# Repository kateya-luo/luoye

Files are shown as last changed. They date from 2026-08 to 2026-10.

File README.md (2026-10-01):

# 落叶（Luoye）录音卡---会议纪要AI录音卡

<!-- split-project-navigation -->
## 固件与服务器独立入口

落叶是同一个完整项目，固件与服务器通过 `luoye-device-api/2` 配合，分开维护和发布。

| 组件 | 独立入口 | 版本下载 |
| --- | --- | --- |
| 录音卡固件、硬件与使用说明 | [固件页面](https://github.com/kateya-luo/luoye/tree/main/firmware) | [固件历史发布](https://github.com/kateya-luo/luoye/releases) |
| ClearMeeting 服务器与网页 | [服务器项目](https://github.com/kateya-luo/clearmeeting-server) | [V2.1.0 R2](https://github.com/kateya-luo/clearmeeting-server/releases/tag/v2.1.0-r2) |

**最新服务器版本为 V2.1.0 R2。** 本仓库原 `server/` 和旧服务器 Release 保留作历史归档；
新部署、升级及服务器源码请使用上面的独立服务器项目。
下方旧兼容基线和固件功能描述对应历史公开版本，不代表新版省电固件的功能。
本次不发布或替换固件二进制。

<!-- /split-project-navigation -->

起因是我觉得钉TALK太贵了，这么个玩意儿自己做一个得了，结果就是漫长的三个月。
这也是我第一个全自研（AI助力）的项目，希望您能喜欢。
落叶是一套以 ESP32-S3、1.54 英寸电子墨水屏、双麦克风和 microSD 为核心的录音卡系统。设备负责可靠录音、离线保存、实时字幕显示与断点补传；ClearMeeting 负责转写、多人识别、会议纪要、待办和网页管理。

## 项目预览

|  |  |
| :---: | :---: |
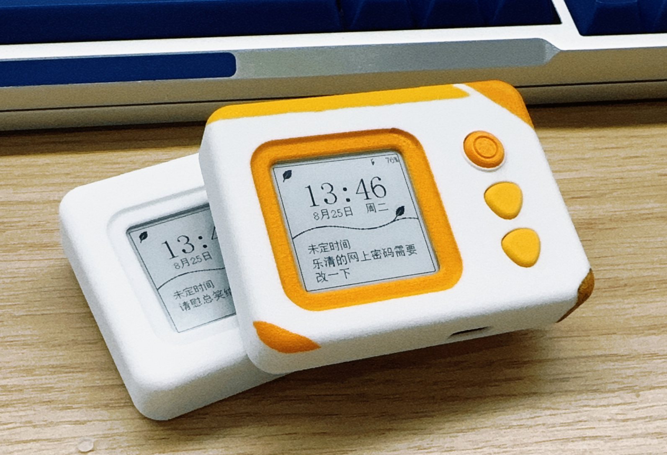
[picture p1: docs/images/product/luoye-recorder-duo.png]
两台落叶录音卡工程样机
|  | 截图_20261001234019 |
| **桌面使用** | **实机操作** |
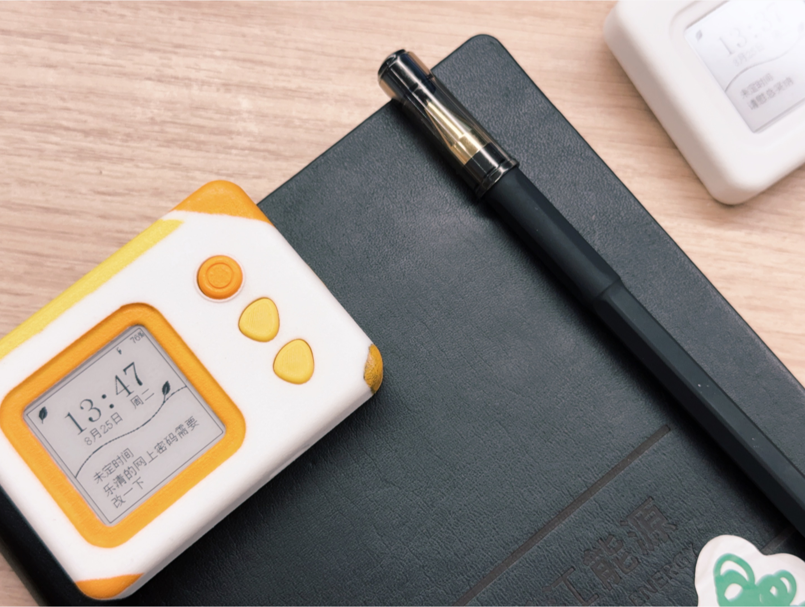
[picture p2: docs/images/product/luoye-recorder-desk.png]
落叶录音卡桌面使用场景
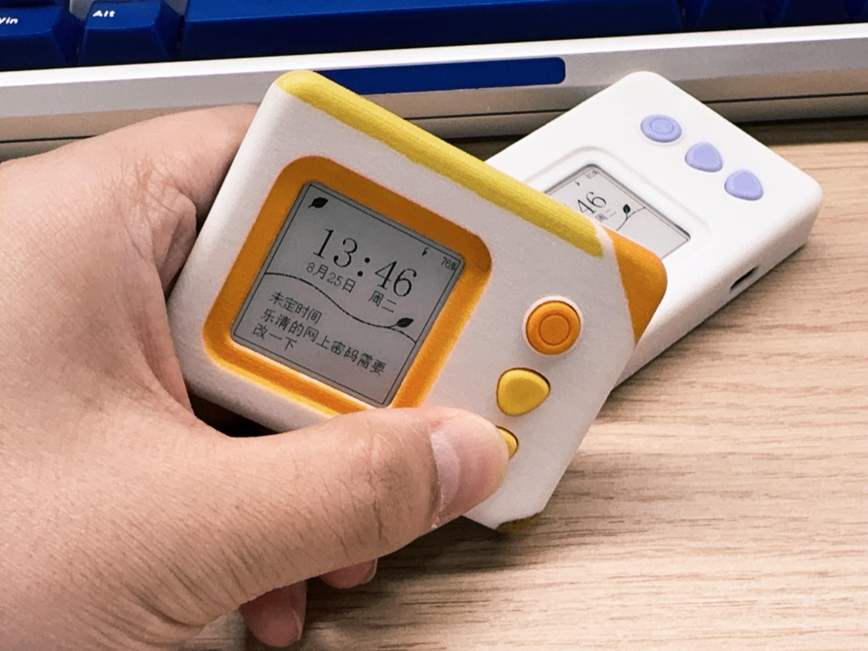
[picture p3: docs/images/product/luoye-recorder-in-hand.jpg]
手持操作落叶录音卡
|  |  |

以上为当前 3D 打印外壳的工程样机实拍。

## 当前兼容基线

| 组件 | 版本/标识 | 说明 |
| --- | --- | --- |
| 固件 | `2.0.0 stable-sdspi R1` | 由已验证的 `1.7.2` 稳定基线重新编号 |
| 服务器 | `2.0.0 stable R1` | 由 `0.21.0-upload-progress-r9` 稳定基线重新编号 |
| 设备 API | `luoye-device-api/2` | 固件与服务器的兼容边界 |
| 硬件 | `LY-HW-ENG-20260710` | 当前工程样机，尚未形成量产归档 |

详细变化和验证要求见 [发布兼容矩阵](docs/RELEASE_COMPATIBILITY.md)。

## ClearMeeting 网页

| 实时会议 | 会议历史 |
| :---: | :---: |
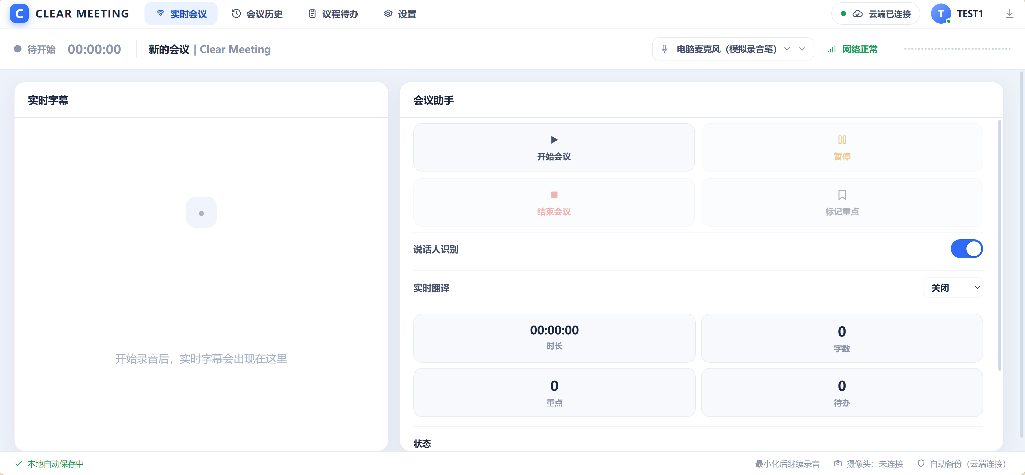
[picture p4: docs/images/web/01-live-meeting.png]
ClearMeeting 实时会议
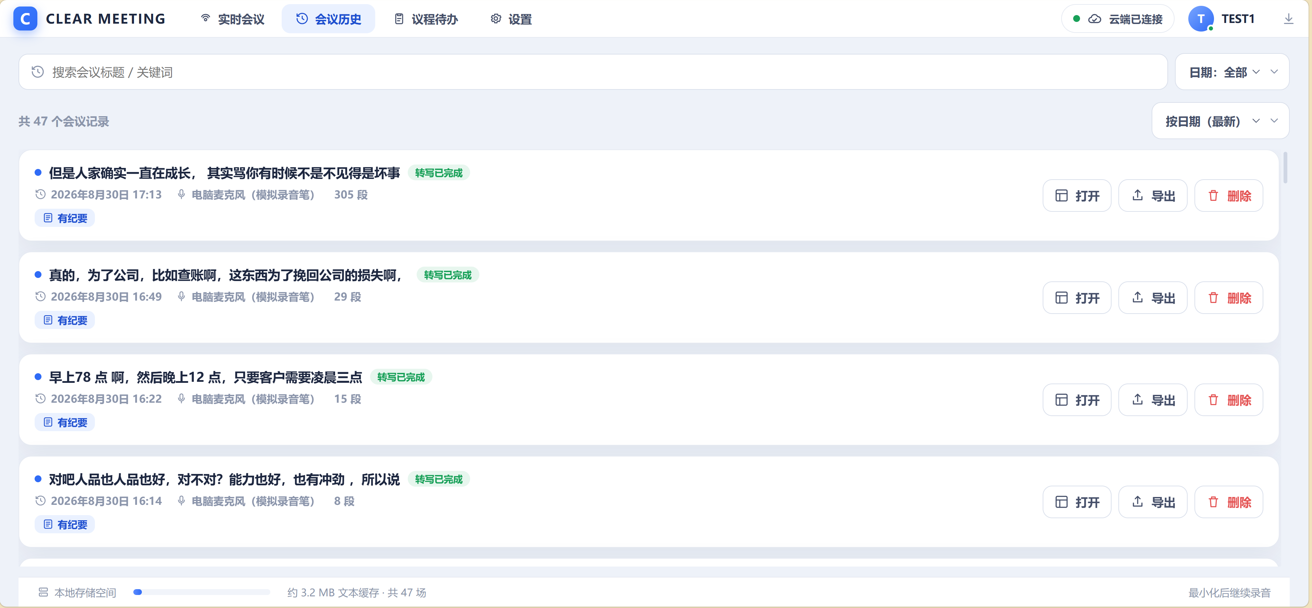
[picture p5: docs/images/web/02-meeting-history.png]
ClearMeeting 会议历史
|  |  |

| 完整转写与人员 | 议程与待办 |
| :---: | :---: |
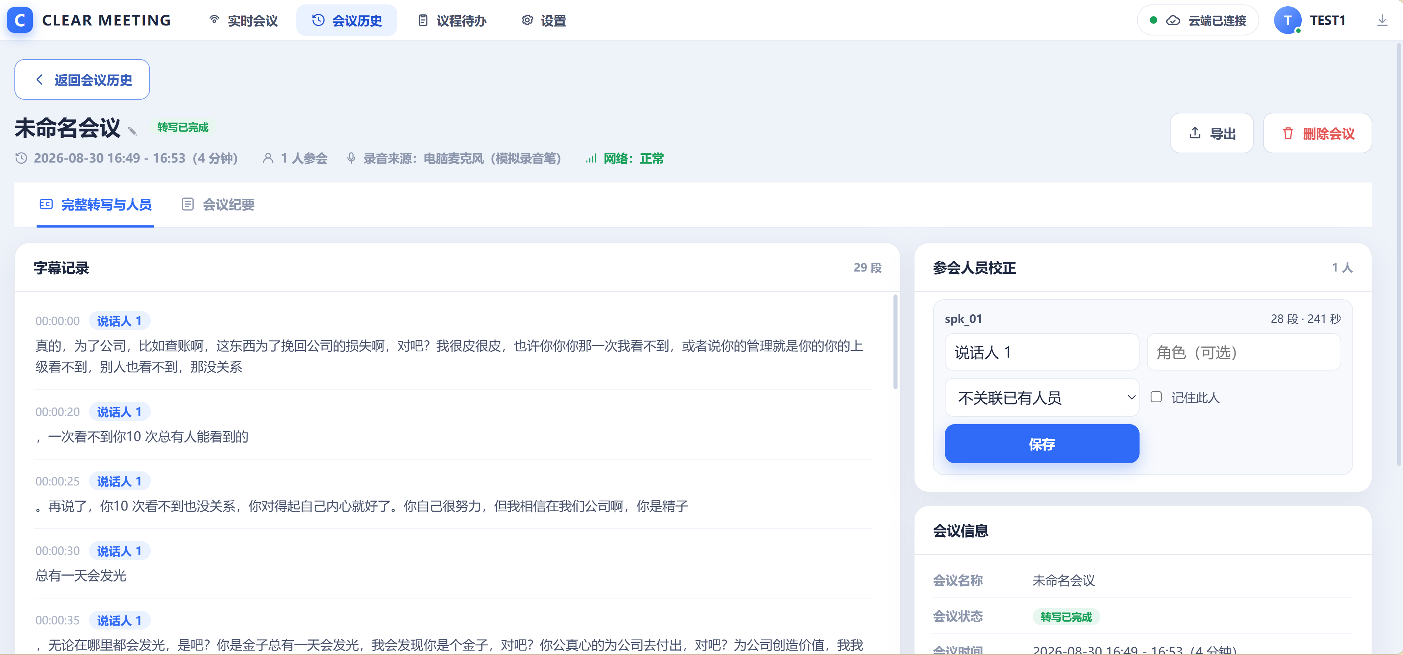
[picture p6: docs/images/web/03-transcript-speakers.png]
完整转写与说话人校正
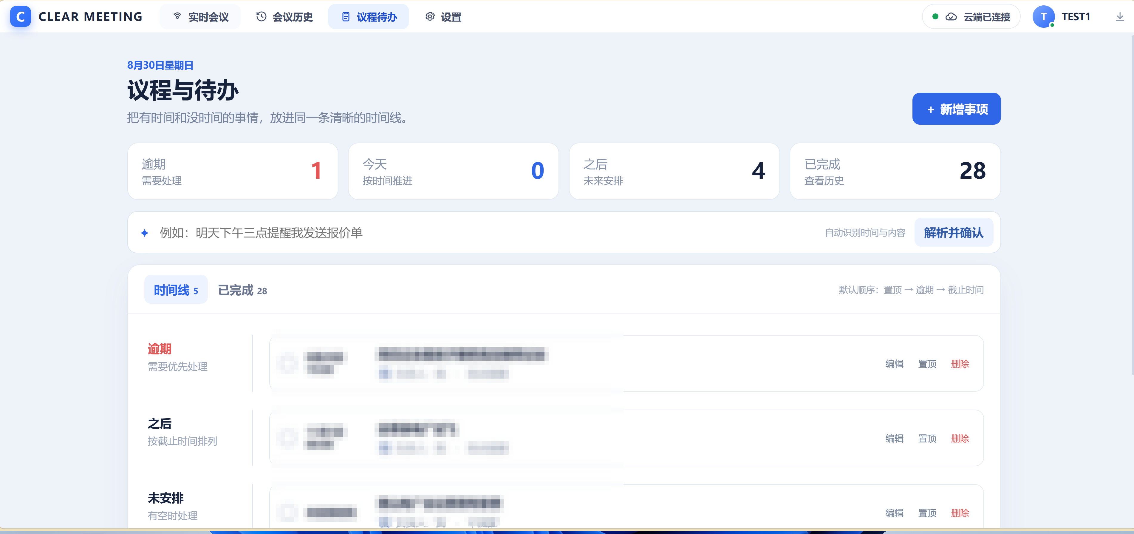
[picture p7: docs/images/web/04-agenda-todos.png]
议程与待办页面
|  |  |

| 设备管理 | 会议导出 |
| :---: | :---: |
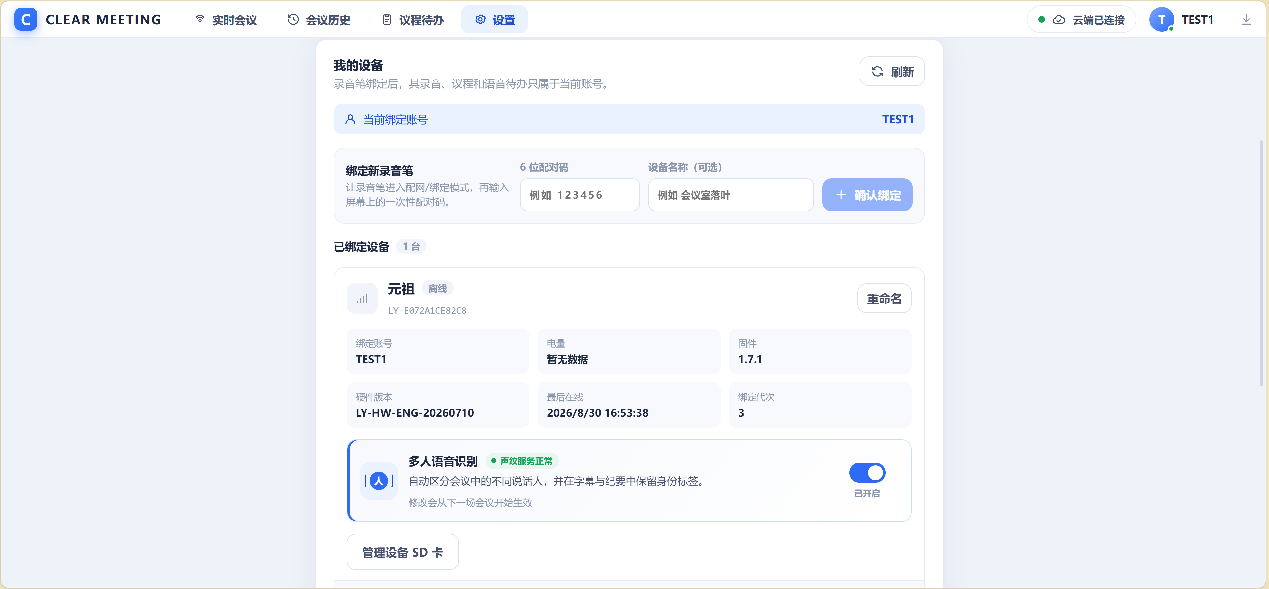
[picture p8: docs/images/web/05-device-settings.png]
录音卡设备管理
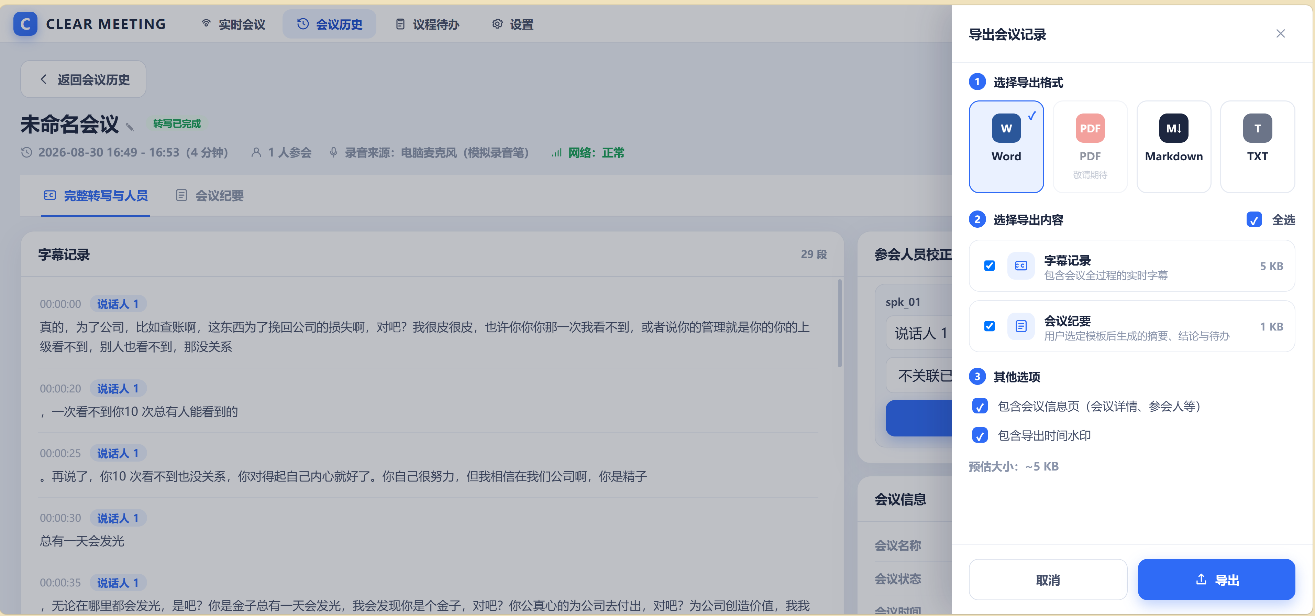
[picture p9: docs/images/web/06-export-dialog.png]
会议记录导出
|  |  |

## 主要能力

- 双 PDM 麦克风录音，16 kHz 单声道 PCM/WAV 先落 microSD。
- 断网、重启和手动退出后按服务器缺口继续补传。
- 电子墨水屏显示时钟、电量、录音状态、字幕、议程、提醒和语音待办。
- ClearMeeting 提供实时转写与翻译、整场离线规范化、多人识别和模板化会议纪要。
- 设备与网页共享账号隔离、幂等会话、SD 管理和后台处理状态。
- 固件、服务器、PCB 与机械结构在同一仓库记录兼容关系。

## 使用说明

### 产品的基本使用流程

1. 在自己的服务器上部署 ClearMeeting，复制 `.env.example` 为 `.env`，填写账号密钥、AI 服务密钥和自己的 HTTPS 地址。
2. 给录音卡插入 FAT32 microSD 卡并开机；首次使用时按屏幕提示完成 Wi-Fi 配网，然后在网页“设置”中输入六位配对码绑定设备。
3. 使用录音键开始或结束录音。音频先可靠写入 SD 卡，联网时同步到服务器；断网时继续本地录音，恢复网络后按服务端缺口续传。
4. 录音期间可在墨水屏和网页查看实时文字；启用翻译后，还可同步查看目标语言内容。
5. 会议结束后，在网页历史记录中查看完整转写、说话人、纪要和待办，并导出 Word、Markdown 或文本。

### 录音卡功能

- 双麦克风采集、16 kHz WAV 本地保存，断网、复位和中途退出后可继续补传。
- 电子墨水屏显示时间、电量、录音时长、实时文字、翻译、滚动纪要、议程与提醒。
- 待机期间以 RTC 保持离线到点提醒；联网唤醒后同步日程和待办。
- 录音与上传使用独立的持久化状态，上传不会清空日程数据。
- microSD 异常、服务器状态和上传进度均有诊断日志，便于通过 USB 串口排查。

### ClearMeeting 网页功能

- 账号登录、录音卡配对、在线状态与 SD 卡管理。
- 浏览器直接发起会议，或接收录音卡上传的在线/离线会议。
- 实时字幕、实时翻译、完整离线定稿和多人说话人识别。
- 会议历史检索、纪要模板、待办提取、时间线、人员校正和多格式导出。
- 日历式议程与待办同步，可创建有时间或无时间的提醒事项。

### 典型场景

- **会议与访谈**：可靠录音、实时字幕、会后定稿、说话人区分和纪要导出。
- **外文课堂**：把实时转写与翻译显示在网页或录音卡上，作为随身课堂字幕/翻译设备。
- **课程表提醒**：利用和日历系统关联的议程与待办，把课程安排同步到录音卡，并由 RTC 离线提醒。
- **讲座与学习整理**：长时间录音后自动形成可检索文字、重点和后续任务。

按键、烧录、串口诊断和开发构建的详细说明见 [固件使用文档](firmware/README.md)；部署和环境变量见 [服务器使用文档](server/README.md)。

## 数据流

```text
双麦克风 → ESP32-S3 → microSD/WAV → luoye-device-api/2 → ClearMeeting
               ↓                              ↓
          电子墨水屏                    转写 / 多人识别
                                             ↓
                                      纪要 / 待办 / 导出
```

## 仓库结构

```text
firmware/             ESP32-S3 固件源码、构建检查和诊断工具
server/               ClearMeeting 服务端、Web 前端与部署文件
hardware/pcb/         主板/双麦板原理图与 EPRO 工程
hardware/mechanical/  外壳、内壳、底壳和按钮 STEP
docs/                 跨组件版本、制造与发布说明
scripts/              发布前仓库审计
```

## 快速开始

- 固件编译、烧录和串口诊断：[firmware/README.md](firmware/README.md)
- 服务器部署与验证：[server/README.md](server/README.md)
- PCB 与机械资料：[hardware/README.md](hardware/README.md)
- GitHub 发布前检查：[docs/GITHUB_PUBLISH_CHECKLIST.md](docs/GITHUB_PUBLISH_CHECKLIST.md)

## 隐私与部署配置

- 仓库不内置作者的 DeepSeek API Key、个人服务器域名/IP、Wi-Fi 名称、账号密码或设备令牌。
- `DEEPSEEK_API_KEY`、CORS 来源和公开服务地址只在本地 `.env` 或构建参数中配置；`.env` 已被 Git 忽略。
- 固件公开源码默认使用不可路由的 `https://meeting.example.invalid`。构建前必须用 `-ServerBaseUrl https://你的域名` 指定自己的服务。
- 如需同一 Wi-Fi 下走局域网服务器，可同时设置 `LUOYE_LAN_WIFI_SSID` 与 `LUOYE_LAN_SERVER_BASE_URL`；公开源码中的默认值为空。

## 版本和发布

源码仓库不提交烧录包、服务端压缩包、数据库、录音或密钥。二进制发布附件使用独立组件标签：

- `firmware-v2.0.0`
- `server-v2.0.0`

固件当前仍按 Engineering 版本发布。正式量产前必须完成真机长录音、跨 10 MiB 边界、上传中断恢复、SD 故障和重复复位验证。

## 工程边界

- 当前硬件资料属于自研样机。不能直接作为生产或开模依据；详见 [制造归档检查](docs/MANUFACTURING_STATUS.md)。
- 工程部署仍可显式使用 HTTP；真实账号、设备令牌和真实录音必须改用 HTTPS。
- 当前未选择开源许可证。在加入 `LICENSE` 前，代码和设计资料默认保留全部权利。

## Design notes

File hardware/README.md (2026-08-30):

# 硬件资料

- `pcb/`：2026-08-30 主板与双麦板 EPRO 工程，以及 2026-06-21 原理图 PDF。
- `mechanical/`：V2 外壳、底壳、内壳和两个按钮的 STEP 文件。

> [!WARNING]
> ECAD 与 MCAD 当前是两个独立的工程参考基线，尚未完成板框、接口位置、按键行程、螺柱和装配公差的联合锁版。仓库中的实物照片能证明当前样机已经装配运行，但不能证明这些源文件可以直接投产。

正式发板、打印定版或开模前，请完成 [制造归档检查](../docs/MANUFACTURING_STATUS.md)。

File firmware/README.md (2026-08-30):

# 落叶（Luoye）录音卡固件

ESP32-S3 + 1.54" 方形墨水屏(GDEY0154D67/SSD1681, 200×200)+ 双 PDM 麦 + microSD。

当前方屏版本说明、按键表和烧录步骤见 [docs/UI154_FIRMWARE.md](docs/UI154_FIRMWARE.md)。
内部产品名为 **落叶 / Luoye**，ESP-IDF 工程名保留为 `recorder_card`。
当前固件版本：`2.0.0`，设备协议：`luoye-device-api/2`，配套服务器：ClearMeeting `2.0.0`（源自 `0.21.0-upload-progress-r9`）。
V1.5.0 的电量百分比改为 3.180–4.100V 被动电压映射；它只负责显示，不参与充电终止或录音权限判断。详见 [docs/V1_5_0_PASSIVE_BATTERY_DISPLAY.md](docs/V1_5_0_PASSIVE_BATTERY_DISPLAY.md)。
V1.5.1 调整墨水屏维护节奏：每分钟时间局刷、每10分钟 FAST、每逢整点 FULL，充电页每跨5%执行一次 FAST。详见 [docs/V1_5_1_REFRESH_CADENCE.md](docs/V1_5_1_REFRESH_CADENCE.md)。
V1.5.2 删除所有人为电量涨跌速度和99%封顶，滤波电压直接映射百分比。详见 [docs/V1_5_2_DIRECT_VOLTAGE_SOC.md](docs/V1_5_2_DIRECT_VOLTAGE_SOC.md)。
V1.6.0 R2 只修复手动补传再次进入时未立即继续的问题：重新确认同步会解除旧重试等待，并再次依据服务器 `upload-plan` 续传；不增加NVS状态，也不改变10 MiB和底层上传参数。详见 [docs/V1_6_0_MINIMAL_MANUAL_RESUME.md](docs/V1_6_0_MINIMAL_MANUAL_RESUME.md)。
V1.7.2 固定项目本地 ESP-IDF 5.5.4 `sdmmc` 组件。SDSPI 主机已拥有永久516字节内部 DMA 中转，因此通用读写层不再为 FatFS/PSRAM 缓冲临时申请512字节 DMA；原生 SDMMC 规则不变。实时录音、实时读取和离线上传共用这一根因修复，10 MiB分段、SHA、断点续传及网络参数保持不变。详见 [docs/V1_7_2_SDSPI_OUTER_DMA.md](docs/V1_7_2_SDSPI_OUTER_DMA.md)。
V2.0.0 是已通过真机稳定验证的 V1.7.2 正式升版，不引入功能或参数变化。它取代早期同号的 live-caption 实验包，作为后续维护基线。详见 [docs/V2_0_0_STABLE_BASELINE.md](docs/V2_0_0_STABLE_BASELINE.md)。
交互行为以 **250×122 交互模拟器** 为规格书(`ai-recorder-card-sim-index-250x122.html`),
`main/app_state.c` 是其中状态机的 1:1 C 移植 —— **改交互先改模拟器,确认后两边同步**。

## 架构

```
keys(10ms轮询) ──┐
power_poll(5s) ──┼─→ [app事件队列] → app_task(串行) → app_state 状态机 → hooks
network scheduler ─┘                                        │
                                                   ┌────────┼─────────┐
audio_cap(核1,p18) → StreamBuffer(PSRAM 256KB) → sd_writer(核0,p15)   │
                                                   ui(渲染,p6)   led(50ms)
```

数据流：
**PDM 双麦 → 16k 单声道 PCM → SD(WAV,先落卡) → 在线 160 KiB 实时上传；
整段离线/断网补洞按 10 MiB 逻辑范围、64 KiB RAM 流式上传
→ 最多 4 秒一次 revision 游标轮询字幕/译文 → 墨水屏节流回屏**。议程以 UTC/revision 缓存到固定 SD，
PCF8563 调度最近提醒；待机按住待办键可另存最长 30 秒的语音待办。当前录音在线时
实时上传，已结束的历史录音由录音键长按进入、待办键确认的 FIFO 同步；服务器验证字节覆盖并
完整确认后立即删除对应本地目录。录音与待办请求都使用稳定幂等键。所有已认证
HTTP 由单一网络业务调度器仲裁，SD 录音写入不依赖网络。

## 目录

| 路径 | 内容 |
|---|---|
| `main/board_pins.h` | **引脚真源**(网表+BOM 验证,2026-07-10),改板先改这里 |
| `main/luoye_build_info.[ch]` | 单一版本源、commit、硬件版本、IDF 和启动身份日志 |
| `main/luoye_diag.[ch]` | 统一 `LYE-xxx` 错误码、子系统状态和事件丢弃计数 |
| `main/app_state.[ch]` | 核心状态机(纯逻辑,可 PC 单测) |
| `main/input_keys.c` | 三键去抖 + 每键每态长按阈值（录音键1.5s/关机3s，设置键3s，待办键待机600ms） |
| `main/led_ctrl.c` | 三灯花样(语义同模拟器 renderLeds) |
| `main/ui_render.c` | 帧缓冲 + 各屏布局(中文文案对齐模拟器);5×7 ASCII 兜底 |
| `main/ui_font.c` | 16px 中文点阵字库加载与渲染(assets 分区 `font16.bin` → PSRAM,二分查找) |
| `tools/gen_font.py` | 字库生成脚本(TTF/TTC → font16.bin) |
| `tools/preview_screens.py` | 屏幕布局预览(不烧板看 250×122 真机像素效果) |
| `tools/test_app_state.c` | 状态机 PC 回归测试(`run_state_test.bat` 一键编译运行,改 app_state.c 必跑) |
| `tools/build_profile.ps1` | 固化 dev / rc / release 三种构建配置 |
| `tools/run_engineering_checks.ps1` | 回归测试、版本检查、构建和可选打包门禁 |
| `tools/package_firmware.ps1` | 生成带 manifest、SHA-256 和烧录说明的内部发布包 |
| `assets/font16.bin` | 21159 字 / 703KB(Noto Sans SC Light，GBK 全集汉字 + 中英标点 + 全角) |
| `components/epd_ssd1680/` | 屏驱动(厂商时序逐条移植;全刷 0xF7 / 快刷 0xC7 / 局刷 0xFF) |
| `components/audio_pdm/` | I2S PDM 采集 → PSRAM 环形缓冲 |
| `components/storage_sd/` | SD 挂载 + WAV 写入(64KB 修头+fsync,断电可恢复)+ 容量巡检 |
| `components/net_uploader/` | SoftAP、账号认领、持久补传、实时字幕/翻译协议 |
| `components/power_mgr/` | BQ25186 / MAX17048 / PCF8563(I2C)+ 深睡 |
| `components/agenda_todo/` | 议程原子缓存、RTC 调度、语音待办旁路录制与状态持久化 |

## 构建（固定 ESP-IDF v5.5.4）

在 ESP-IDF PowerShell 中执行：

```powershell
cd <仓库目录>\firmware
.\tools\run_engineering_checks.ps1 -Profile dev -FullClean
```

正式 HTTPS 开发构建（默认连接 `https://meeting.example.invalid`）：

```powershell
.\tools\build_profile.ps1 -Profile dev
```

局域网/公网工程联调必须显式给出服务器 origin 并打开明文 HTTP；该开关只允许 `dev` 或 `engineering`
工程构建，不能用于真实账号或敏感录音：

```powershell
.\tools\build_profile.ps1 -Profile dev `
  -ServerBaseUrl http://192.0.2.10:34567 `
  -AllowInsecureHttp
```

`ServerBaseUrl` 只能是无路径、无末尾 `/` 的 `http(s)://host[:port]`。
`rc` / `release` 构建拒绝 HTTP，并固定使用系统 CA 验证 HTTPS。

公开源码不包含作者的 SSID 或局域网服务器地址。如需在指定 Wi-Fi 下自动切换到局域网服务，
配置时必须同时传入 `LUOYE_LAN_WIFI_SSID` 和 `LUOYE_LAN_SERVER_BASE_URL`；两项默认均为空。

生成工程烧录包（必须先提交源码并保持 Git 工作树干净）：

```powershell
.\tools\run_engineering_checks.ps1 -Profile engineering -FullClean -Package `
  -ReleaseId luoye-fw-v2.0.0-engineering-stable-sdspi-r1 `
  -ServerBaseUrl https://meeting.example.invalid
```

当前正式构建机已使用 ESP-IDF v5.5.4 完成 baseline 干净构建。构建会自动把
`assets/`（含字库）生成 `assets.bin`；打包脚本不会擦除或覆盖设备 NVS。

版本单一真源是根 `CMakeLists.txt` 的 `PROJECT_VER`。UI、ESP app descriptor、
串口 `LY|BOOT` 记录和 release manifest 必须保持一致。

当前硬件标识暂定为 `LY-HW-ENG-20260710`，表示基于 2026-07-10 网表的工程样板；
正式 PCB 丝印版本确定后必须同步更新，禁止把暂定标识用于量产。

## 中文字库

- 运行时:`ui_font.c` 开机把 `font16.bin` 载入 PSRAM;文件缺失时 UI 自动退回 ASCII(中文显示空心框),设备不砖。
- 重新生成:`python tools/gen_font.py --font <字体文件> --out assets/font16.bin`,
  `--test 会议` 可先预览点阵,`--dump 会议` 验证已生成文件的解码。
- **字体授权**:当前 `font16.bin` 使用 Noto Sans SC Light 生成；固件页面使用单色点阵，
  不包含灰阶抗锯齿。

## 首次点亮前必读

1. **墨水屏方向校准**:若首帧镜像/颠倒,改 `epd_ssd1680.h` 里
   `EPD_ROT_FLIP_X / EPD_ROT_FLIP_Y / EPD_X_OFFSET` 三个宏即可,不用动代码。
2. **Strap 脚**(引脚表里已标 ⚠):
   - GPIO46(EPD_MOSI)启动瞬间必须为低 —— 屏端不得有上拉;
   - GPIO45(FULL_LED)、GPIO3(EPD_SCLK)同为 strap,当前用法安全,改板别挂强上拉。
3. **到点提醒的低功耗策略**:`RTC_INT` 在 **GPIO41(非 RTC-IO)**，不能作为深睡
   唤醒源。固件在存在已缓存提醒时改用 GPIO light sleep，由 GPIO41 或长按 REC
   唤醒；没有提醒时仍进入深睡。这样现板无需飞线即可到点唤醒，代价是有提醒期间
   待机功耗高于深睡。下一版 PCB 仍建议把 `RTC_INT` 改到 RTC-IO。
4. 按键无外部上拉(只有 100nF 去抖电容):运行态开内部上拉,深睡前开 RTC 域上拉
   (`power_enter_off` 已处理,别删)。

## 与模拟器的行为对照

| 模拟器 | 固件 |
|---|---|
| 待机短按 REC 开录 / BACK 翻页 | `app_state.c: short_press` |
| 录音短按 REC 暂停 / 长按 REC 1.5s 结束 | 同上 + 安全收尾 |
| 待机按住 REC 说话建待办，松开保存 | 独立截取单声道 WAV；断网上传、ASR 与确认状态均持久化 |
| 中间键 | 待机长按进入同步页；短按确认上传历史录音；BACK 取消 |
| 录音长按 BACK 3s 锁键;待机长按 BACK 配网 | `long_press` |
| 录音开始立即显示；章节纪要按自然分钟边界刷新；待机分钟刷新 | 所有产品页面统一使用 SSD1681 差分快刷 |
| RTC 到点提醒(REC 开录 / BACK 关闭 / 长按 BACK +10min) | `rtc_alarm` + PCF8563 闹钟 |
| 电量 <5% 拒绝开录;SD 将满 FULL 黄灯 | `start_rec` / `space_task` |

## 已知限制（工程版，量产前必修）

- 固件 2.0.0 和 ClearMeeting 2.0.0 已统一到 `luoye-device-api/2`；账号隔离、配对、断网补传、
  字幕/翻译、议程和语音待办仍需完成真实设备端到端验收后才能进入量产状态。
- 设备端只读取服务器给出的同一 revision 原文/译文；不在本地运行 ASR 或翻译模型。
- PCF8563 闹钟没有月份字段；服务器议程接口应只下发未来 14 天窗口。
- 状态快照跨任务读（UI/LED 读 app_state）对 64 位字段仍有理论撕裂风险。
- 有提醒时使用 light sleep 是当前硬件兼容方案，需在真板测量实际待机电流。

## TODO(按优先级)

1. ~~中文渲染~~ ✅ 已完成(16px 点阵字库 + UTF-8 渲染 + 折行;量产前换开源字体重新生成)。
2. ~~SoftAP 配网和账号认领客户端~~ ✅ API/2 客户端完成；待真板端到端验收。
3. ~~实时字幕/翻译协议与会议两页、翻译三页~~ ✅ API/2 客户端完成；待真板端到端验收。
4. ~~语音待办：MARK 按住期间单独截 PCM → 断网补传 → 确认后入日历~~ ✅ API/2 客户端完成；待真板端到端验收。
5. ~~SNTP 校准 PCF8563、议程原子缓存和最近提醒调度~~ ✅ 设备端完成；待真板端到端验收。
6. OTA(切双 app 分区);音频编码抽象(Opus/ADPCM 省流量)。

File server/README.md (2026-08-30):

# ClearMeeting Server 2.0.0

ClearMeeting 是落叶 ESP32-S3 录音卡的自托管云服务。当前 `2.0.0 stable R1` 直接由已经验证的 `v0.21.0-upload-progress-r9` 重新编号，保持 `luoye-device-api/2`、10 MiB 范围补传和真实上传进度语义不变。

## 主要功能

- 账号、会议、设备、议程与待办按用户隔离。
- 一次性设备配对、可撤销设备令牌和绑定代次校验。
- 在线录音实时转写与翻译，离线录音幂等分片补传。
- 完整音频到达后执行整场规范转写、说话人识别和会议纪要。
- 按持久化音频范围的并集显示真实上传覆盖率和缺失时长。
- 网页提供会议历史、人员校正、议程待办、设备/SD 管理及 Word、Markdown、TXT 导出。

## 版本边界

| 项目 | 当前值 |
| --- | --- |
| 服务器 | `2.0.0` / `clearmeeting-server-v2.0.0` |
| 来源基线 | `v0.21.0-upload-progress-r9` |
| 设备协议 | `luoye-device-api/2` |
| 推荐固件 | `Luoye 2.0.0 stable-sdspi R1`（源自固件 1.7.2） |
| 设备鉴权 | `engineering` |

设备可通过 `GET /api/v2/build-info` 检查版本、协议和能力列表。API/2 工程鉴权并不等同于量产设备证书体系。

## 快速部署

```bash
cd deploy
cp .env.example .env
# 编辑 .env，填写独立强密钥、自己的 HTTPS Origin 和可选 AI Key
docker compose --profile real-asr up -d --build
bash check.sh
bash verify_api_v2.sh
```

部署前至少设置：

- `TEST_ACCOUNT_PASSWORD`
- `AUTH_SECRET`
- `DEVICE_API_SECRET`
- `CORS_ALLOW_ORIGINS`
- `DEEPSEEK_API_KEY`（需要翻译或 AI 纪要时）

完整升级流程见 [V2.0.0 部署说明](docs/DEPLOYMENT-V2.0.0.md)。

## 隐私与密钥

- 仓库只提供 `.env.example`，真实 `.env`、数据库、录音、密码、token 和 API Key 不进入 Git。
- `DEEPSEEK_API_KEY` 从运行环境读取，示例值为空；代码中没有内置密钥。
- 示例地址使用 `meeting.example.invalid` 或 RFC 5737 文档地址，部署时替换为自己的 HTTPS 域名。
- 不要把真实 `.env` 打进发布 ZIP；`deploy/package_server.ps1` 只打包示例配置。

## 开发验证

后端：

```powershell
cd server
python -m unittest discover -s tests -p "test_*.py"
```

前端：

```powershell
cd apps/web-client
pnpm install --frozen-lockfile
pnpm test
pnpm build
```

## 目录

```text
server/             FastAPI、SQLite、设备 API 与后台任务
apps/web-client/    React 19 / Vite 网页
deploy/             Docker Compose、nginx、环境模板和验证脚本
docs/               API、部署、升级和架构说明
```

技术栈：FastAPI · React 19 · Vite · SQLite · Docker Compose · nginx · FunASR · CAM++ · DeepSeek

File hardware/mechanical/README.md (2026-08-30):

# 机械结构资料

| 文件 | 用途 | 来源日期 |
| --- | --- | --- |
| `luoye-enclosure-outer-v2.step` | V2 外壳主体 | 2026-08-13 |
| `luoye-enclosure-bottom-v2.step` | V2 底壳/后盖 | 2026-08-13 |
| `luoye-enclosure-inner-v2.step` | V2 内部支撑 | 2026-08-13 |
| `luoye-button-leaf-v2.step` | 圆润叶子按钮 | 2026-08-07 |
| `luoye-button-round-v2.step` | 圆润圆按钮 | 2026-08-07 |

## 已知差异

- 这些 STEP 早于 2026-08-30 的主板/麦克风板 EPRO，没有与最新 ECAD 重新做联合干涉检查。
- 当前仓库没有与最新板框严格对应的 PCB 装配 STEP。
- 实物照片展示的是可工作的工程样机，但不同打印批次、按钮颜色和细节处理存在差异。

打印定版或开模前，应重新核对屏幕窗口、USB/SD 开口、麦克风声孔、按钮行程、螺柱、电池空间、板间连接和装配公差。

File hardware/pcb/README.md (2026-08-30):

# 主板与麦克风板资料

| 文件 | 用途 | 状态 |
| --- | --- | --- |
| `luoye-mainboard-2026-08-30.epro` | 当前主板 ECAD 工程 | 当前工程源 |
| `luoye-microphone-board-2026-08-30.epro` | 当前双麦板 ECAD 工程 | 当前工程源 |
| `luoye-mainboard-schematic-2026-06-21.pdf` | 主板原理图预览 | 历史导出，仅供阅读 |
| `luoye-microphone-board-schematic-2026-06-21.pdf` | 双麦板原理图预览 | 历史导出，仅供阅读 |

## 已知差异

- 两份 PDF 的导出时间早于 2026-08-30 EPRO，不能视为最新工程的等价输出。
- 主板 PDF 中仍可见 nRF52840 模块，而当前固件目标是 ESP32-S3；因此 PDF 只能作为历史设计参考。
- 当前目录没有从 2026-08-30 工程重新导出的 BOM、Gerber、钻孔、贴片坐标和装配 STEP。
- 发板前必须以确认后的 EPRO 为唯一输入，重新导出并逐项核对制造文件。

不要把历史 PDF 与当前 EPRO 混合交付给生产方。

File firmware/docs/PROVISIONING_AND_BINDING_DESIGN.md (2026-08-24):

# 落叶 v0.6.1 配网与账号绑定设计

状态：`API V1 IMPLEMENTED / END-TO-END PENDING`

适用固件：`0.6.1-cloud-v1`

API 契约：`luoye-device-api/1`

## 1. 产品边界

- 落叶自身的 `LUOYE-XXXX` 配网热点为开放网络，不设置热点密码。
- 录音卡只接收并保存目标 2.4 GHz WiFi 的名称和密码；目标网络开放时密码可留空。
- SoftAP 页面不出现账号、账号密码、用户 ID 或服务器地址输入框。
- 服务器地址由固件固定，用户不能把设备引向任意服务器。
- 用户在 ClearMeeting 网页或客户端登录，然后用一次性配对码认领设备。
- 设备只保存服务器签发的可撤销 Device Token 和脱敏账号名。
- 未取得 Device Token 时，不上传会话元数据或音频。
- WiFi、服务器、绑定和录音存储是四个独立状态；任何联网故障都不能阻止本地录音。

## 2. 用户流程

1. 待机状态长按 `BACK` 3 秒。
2. 墨水屏显示开放热点 `LUOYE-XXXX`、“无需密码”和 `192.168.4.1`。
3. 手机连接热点，打开 `http://192.168.4.1/`。
4. 页面扫描并选择 2.4 GHz WiFi，只填写 WiFi 密码。
5. 设备先用候选凭据连接；只有获得 IP 后才原子写入 NVS。
6. 设备通过固定 HTTPS 服务器登记一次性配对码。
7. 用户断开设备热点，在 ClearMeeting 登录自己的账号并输入配对码。
8. 设备轮询同一个 nonce；服务器确认认领后返回 Device Token 和脱敏账号。
9. 设备原子保存绑定结果，自动关闭 HTTP portal/SoftAP、切回 STA 并返回正常页面。

已绑定设备再次主动进入配对时允许原账号认领并轮换 token；旧 token 在新 token
成功持久化前继续有效，轮换后的 `binding_generation` 必须保持不变。其他账号不能
借此转移设备，必须先由原账号解绑。

Device Token 返回 `401/403` 时，设备保留 WiFi，清除失效 token，生成新的
`pairing_code + nonce` 并自动回到账号认领页；旧 binding generation 的本地录音
不会上传到新账号。当本机时间早于 2020 年时，已认领的
`pair/status.server_time` 可一次性校准系统时间并回写 PCF8563；有效本机时间不会被
该兜底路径覆盖。

为解决空白板 1970 时钟无法验证首个 HTTPS 证书的问题，SoftAP 页面提交时用隐藏
字段携带浏览器当前 Unix UTC。固件只接受 2020..2099 的严格十进制秒数，只在
本机早于 2020 时 `settimeofday` 并同步 PCF8563；已有有效 RTC 不受浏览器影响。
字段缺失不会阻断旧浏览器配网，HTTPS 门禁会等待 SNTP 后再发起 API。

## 3. 信息流

```mermaid
sequenceDiagram
    participant U as 用户手机
    participant D as 落叶录音卡
    participant S as ClearMeeting服务器
    U->>D: 直接连接开放 SoftAP
    U->>D: SSID + WiFi密码
    D->>D: 候选凭据连接测试
    D->>D: 获得IP后提交NVS
    D->>S: GET /api/v1/build-info<br/>契约和能力门禁
    D->>S: POST /api/v1/device/pair/start<br/>device_id + code + nonce
    S-->>D: pending
    U->>S: 登录账号
    U->>S: POST /api/v1/me/devices/claim<br/>pairing_code
    S->>S: 固化owner与device关系
    D->>S: POST /api/v1/device/pair/status<br/>device_id + nonce
    S-->>D: bound + Device Token + 脱敏账号
    D->>D: 保存Token，不保存账号密码
```

## 4. 设备身份

工程版使用完整 eFuse WiFi MAC 生成稳定 ID：

```text
LY-AABBCCDDEEFF
```

它比旧版 `REC-XXXX` 后四位身份可靠，但仍是工程过渡方案。量产前必须烧录独立
`device_uuid` 和设备密钥，不能仅依赖 MAC。

## 5. NVS 数据

命名空间：`net`

| Key | 内容 | 写入时机 |
|---|---|---|
| `ssid` | WiFi SSID | 候选网络获得 IP 后 |
| `pass` | WiFi 密码 | 与 SSID 同一次 commit |
| `token` | 可撤销 Device Token | 服务器返回 bound 后 |
| `account` | 脱敏账号 | 与 token 同一次 commit |
| `binding_gen` | 当前 `binding_generation` | 与 token 同一次 commit |

当前 dev.1 工程包尚未启用 NVS 加密，只允许工程测试；不得作为生产安全版本。

## 6. 状态机

```text
IDLE
  -> AP_READY
  -> WIFI_CONNECTING
  -> WIFI_CONNECTED
  -> CLAIM_PENDING
  -> BOUND

任一步失败 -> ERROR
BACK -> IDLE
```

串口只输出状态、HTTP 状态码和错误码，不输出热点密码、WiFi 密码、配对 nonce、
Device Token 或账号内容。

## 7. 固定式 SD 交互

设备没有用户可插拔 SD 卡，因此固件界面删除：

- 请插入 SD 卡
- 插卡后重试
- 请勿拔卡
- 更换 SD 卡
- 检查卡座

统一显示：

- `存储不可用`
- `存储空间已满`
- `录音未保存`
- `正在保护录音文件`

“请勿断电”仍保留在安全收尾页，因为它是用户可执行且影响文件闭合的操作。

## 8. 当前验收点

ClearMeeting v0.12.0 与固件已统一到 API v1。仍需用两组真实测试账号验证：配对码
过期/重放、同账号 token 轮换不增加代次、其他账号不能抢绑、解绑后旧 token 立即
失效、设备重启后 NVS 绑定恢复。完成这些项目以前状态保持端到端待验收。

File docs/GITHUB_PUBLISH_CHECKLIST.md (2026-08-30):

# GitHub 首次发布检查清单

## 1. 确认发布边界

- 建议先创建 Private 仓库，完成团队复核后再决定是否公开。
- 若计划公开，先选择许可证；当前仓库没有 `LICENSE`，默认保留全部权利。
- 确认 PCB、器件库、字体、第三方依赖和模型文件允许按目标方式再分发。

## 2. GitHub 安全设置

- 启用 Secret Scanning 和 Push Protection。
- 启用 Private Vulnerability Reporting。
- 保护 `main` 分支，要求 Pull Request 和检查通过后合并。
- 限制 Actions 权限与仓库管理员数量。

## 3. 本地审计

```powershell
powershell -ExecutionPolicy Bypass -File scripts/repo_audit.ps1
git status --short --ignored
```

人工确认没有真实账号、内网地址、生产域名凭据、设备密钥、录音、数据库和客户数据。固件中当前工程服务器地址不是密钥，但公开或量产前仍应改成可配置且使用 HTTPS 的端点。

## 4. 初始化与首个提交

```powershell
git init -b main
git add .
git status --short
git commit -m "chore: prepare luoye monorepo baseline"
```

首次提交前应逐项审阅 `git status`；不要直接执行不经检查的全量推送。

## 5. 发布二进制附件

本地 `.github-release-assets/` 已被忽略。建议建立两个 GitHub Release：

- `firmware-v2.0.0`：上传固件 flash、symbols 及对应 SHA-256。
- `server-v2.0.0`：上传服务器 R1 发布包及对应 SHA-256。

不要把压缩包直接提交进 Git 历史。

当前固件发布名为 `luoye-fw-v2.0.0-engineering-stable-sdspi-r1`，服务器发布名为
`clearmeeting-server-v2.0.0-stable-r1`。两者都必须从清理过私人地址与密钥的干净源码提交重新打包；
清单中的 `git_clean=true`，关键源码哈希、版本号和烧录镜像 SHA-256 均已核验。
在完成真机长录音和中断续传验收前，仍应作为 Engineering/Pre-release 发布。

## 6. 干净环境复验

在另一台电脑或临时目录中重新克隆仓库，按 README 完成一次固件构建、服务端测试、Docker 部署和真机连接。这样可以发现依赖于本机缓存、绝对路径或未提交文件的问题。

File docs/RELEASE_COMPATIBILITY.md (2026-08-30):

# 发布兼容矩阵

## 当前推荐组合

| 固件 | 服务器 | 设备 API | 硬件 | 状态 |
| --- | --- | --- | --- | --- |
| `2.0.0 R1` | `2.0.0 R1` | `luoye-device-api/2` | 当前 ESP32-S3 工程样机 | Engineering 验证基线 |

固件联网后通过 `/api/v2/build-info` 核对服务器版本、协议标识和能力列表。协议不一致时，不能假定上传、字幕或议程接口兼容。

## 固件 2.0.0 stable-sdspi R1

- 直接由已经真机验证的 `1.7.2` 稳定固件重新编号，不引入上传、界面或电量策略变化。
- 在 1.7.2 基线上加入项目内 `sdmmc` 组件，消除 SDSPI 外层 DMA 临时分配失败的根因。
- SD 卡保持 20 MHz、单任务上传、16 KiB 应用层缓冲和 10 MiB 逻辑范围。
- SDSPI 使用永久内部 DMA 缓冲，但 SPI 线上仍发送精确字节数，避免卡边界错位。
- 修复跨块预读字节被清空为 `0xFF` 的 CRC 问题。
- 真实 SD I/O 故障会锁存，停止后续读写，避免继续破坏 FAT32 元数据。
- 实时录音的 `audio.wav` 改为无 stdio 缓冲、4096 字节内部 DMA 对齐写入块，避免 Wi-Fi 上传压力下为 PSRAM 缓冲临时申请 512 字节 DMA 失败。
- 离线上传、SHA、断点续传、网络窗口和服务器 API 保持不变。
- 电量显示采用 3.180–4.100 V 被动映射，不参与充电终止和录音权限判断。
- 每分钟局部刷新时钟和电量，每 10 分钟 FAST，整点 FULL。

## 服务器 2.0.0 stable R1

- 直接由 `v0.21.0-upload-progress-r9` 稳定服务重新编号，业务行为与 R9 保持一致。
- 实时阶段只提供实时转写；音频完整后执行整场 canonical ASR 与最终多人识别。
- 用户在历史页选择模板后生成正式会议纪要。
- 补传阶段显示服务器确认的真实音频覆盖率，不再使用流程加权百分比。
- 覆盖率按持久化字节范围的并集计算，并显示缺失音频时长。
- 后台进度区分上传、排队、离线转写、多人识别和写回。
- 保持 API/2、10 MiB 范围上传、幂等补传、设备恢复和账号隔离。

## 发布验证

1. `GET /api/v2/build-info` 返回 `server_version=2.0.0` 和 `api_contract=luoye-device-api/2`。
2. FAT32 卡完成启动测速与边界自检，不出现 CRC、DMA 分配或 `STORAGE_FAULT`。
3. 连续录音跨越 10 MiB 边界，验证在线上传和本地 WAV 均连续。
4. 手动同步中按设置键退出，再次进入后依据服务器 `upload-plan` 继续补传。
5. 只有服务器缺口为空且 `/complete` 成功后，设备才显示同步完成并清理本地录音。
6. 网页显示真实上传覆盖率，并在完整音频到达后完成规范转写、多人识别和模板纪要。
7. 验证待办、议程、RTC 提醒、电量刷新和录音上传彼此不互相清空或抢占。
8. 在线录音与实时上传并行时，确认 WAV 4096 字节写入路径无 DMA 分配失败、看门狗或音频断点。

## 版本来源说明

- 固件 `2.0.0` 的上一稳定编号是 `1.7.2`。
- 服务器 `2.0.0` 的上一稳定编号是 `v0.21.0-upload-progress-r9`。
- 两端共同使用 `luoye-device-api/2`；重新编号不代表把旧源码直接覆盖成新版本号。

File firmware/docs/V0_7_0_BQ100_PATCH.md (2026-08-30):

# Luoye v0.7.0 low-complexity rollback patch

This branch stays on the verified `luoye-fw-v0.7.0-engineering-lan` source
baseline. It does not include ESP-SR AFE or additional feed/fetch tasks.

Charge policy:

- BQ25186 is initialized and verified at boot; GPIO38 explicitly pulls CE_N low.
- Before a valid MAX17048 SOC sample, charging starts conservatively at 200mA.
- SOC below 80%: 1000mA battery-charge target.
- SOC 80% through 89%: 500mA battery-charge target.
- SOC 90% through 99%: 200mA battery-charge target.
- Input current limit stays at 1050mA in every band because it includes both
  the battery current and the live ESP32/WiFi/display/SD system load.
- At 100%, CHG_DIS stops charging. At 99%, charging is enabled again.
- An invalid MAX17048 read keeps the previous policy.
- Charge/full UI state changes require two valid five-second samples. A transient
  BQ I2C error does not publish a UI state transition.
- The BQ register watchdog is disabled so the selected policy persists.
- Periodic logs expose ILIM, VDPPM, VINDPM and thermal-regulation status bits.
- SYS uses battery-tracking regulation (`VBAT + 225mV`, minimum 3.8V) instead of
  the 4.5V reset default. The downstream TPS63001 remains the card-rail
  regulator. DPPM protection stays enabled.

Network route policy:

- `YOUR_LAN_SSID` uses `http://192.0.2.10`.
- Every other WiFi uses the compiled public endpoint
  `http://meeting.example.invalid:34567`.

Time display:

- RTC and system timestamps remain UTC.
- The home page consistently uses UTC+8, including when agenda metadata is
  missing or stale.

The audio path remains the original v0.7.0 single `audio_cap` task with hardware
PDM-to-PCM, software gain and L/R averaging. ESP-SR is absent.

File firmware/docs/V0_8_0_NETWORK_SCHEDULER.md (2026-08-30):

# 落叶 v0.8.0 网络调度与 API/2 发布说明

配套版本：ClearMeeting `0.14.0` / `luoye-device-api/2`。

## 本版本完成内容

- 在线录音维持 160 KiB 分片，字幕状态轮询上限为 4 秒。
- 完全离线录音与断网缺口统一使用固定 10 MiB 逻辑范围；无 2 MiB 回退。
- 10 MiB 正文使用 64 KiB 缓冲从 SD 流式发送，不在 ESP32 内存中整块展开。
- 单一网络调度任务统一处理在线录音、收尾、历史同步、待办、议程和存储命令。
- 每个通道独立退避，一次 HTTP 完成后重新仲裁；录音 SD writer 完全独立。
- 服务器 ACK、范围覆盖和上传模式写入 `upload.state`，断电/唤醒后继续。
- 远端不完整会话先取消再删除 SD；完整云端会议不会随 SD 副本删除。
- 正在录音或安全收尾时禁止休眠；闭合离线队列在联网失败 60 秒后允许持久休眠。
- 局域网 `YOUR_LAN_SSID` 使用 `http://192.0.2.10`，其他网络使用
  `http://meeting.example.invalid:34567`（仅工程版明文 HTTP）。

## 自动验证门槛

1. ESP-IDF v5.5.4 全量编译成功，目标 ESP32-S3、16 MiB Flash。
2. 状态机、存储格式、配网表单、上传协议、实时协议、议程协议主机测试全部通过。
3. API/2、无 2 MiB 回退、单调度器、手动 FIFO、删除和 UI154 静态门禁通过。
4. 配套服务器真实 HTTP 测试必须覆盖乱序范围、重复范围、双账号隔离、MARK、
   原子完成、取消和解绑令牌失效。

自动门禁通过只代表 `BUILD_PASS`。烧录真板后还需验证在线录音、纯离线录音、
中途断网补洞、重启续传、云端删除、60 秒休眠与按键唤醒，才进入 `BOARD_PASS`。

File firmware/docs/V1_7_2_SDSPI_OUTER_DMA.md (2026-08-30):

# V1.7.2：SDSPI 外层 DMA 根因修复

## 根因闭环

V1.7.1 已取消实时 WAV 的 Newlib 隐藏缓冲，但 WAV 数据从44字节头部后开始，
FatFS 仍需使用扇区缓存处理非512字节对齐的首尾数据。该缓存优先位于 PSRAM，
ESP-IDF 5.5.4 通用 `sdmmc_read_sectors`/`sdmmc_write_sectors` 因而在每次传输前
临时申请512字节 DMA。实时录音与上传并行时，这个运行期申请仍可能失败。

## 修复

- 固定项目本地 ESP-IDF 5.5.4 `sdmmc` 组件。
- 仅当 `host_is_spi(card)` 且主机对齐检查通过时，直接进入 SDSPI 事务层。
- SDSPI 事务层继续把非 DMA/PSRAM 数据分块复制到永久516字节内部 DMA。
- 原生 SDMMC 主机仍执行上游的 PSRAM DMA 能力判断和临时缓冲逻辑。
- 读写两条路径使用同一个 SPI 专用判断，覆盖 FatFS数据、元数据和离线上传。

## 保持不变

SD 20 MHz、单任务上传、16 KiB读取缓冲、10 MiB范围、SHA、断点续传、
TCP/HTTP参数和服务器协议均不改变。

## 真机验收

1. 连续录音并实时上传至少2小时。
2. 断网录制后上传多个10 MiB范围，并中断、重启、续传。
3. 不得出现 `sdmmc_*_sectors: not enough mem`。
4. 核对 WAV 时长、范围 SHA 和服务器最终字节数。

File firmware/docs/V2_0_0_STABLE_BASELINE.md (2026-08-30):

# V2.0.0：稳定基线

V2.0.0 由已完成真机稳定验证的 V1.7.2 原样升版。

本次只更新固件版本号、构建目录和发布标识，不改变运行逻辑或参数：

- 保留 SDSPI 永久内部 DMA 中转及读写根因修复；
- 保留 SD 20 MHz；
- 保留单任务串行上传、10 MiB 分段、SHA 和断点续传；
- 保留既有电量、充电、界面刷新、录音及日程策略；
- 继续兼容 `luoye-device-api/2`；配套服务器由 `0.21.0-upload-progress-r9` 同步重新编号为 `2.0.0`。

此前发布目录中的 `V2.0.0 live-caption` 属于早期实验分支，不是本稳定基线。
后续版本应以本目录和 `stable-sdspi` 发布包为准。

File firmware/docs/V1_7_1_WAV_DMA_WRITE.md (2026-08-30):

# V1.7.1：实时 WAV 固定 DMA 写入

## 现场根因

真机在实时录音并上传约54秒后出现：

```text
sdmmc_write_sectors: not enough mem, err=0x101
LY|STORAGE_FAULT|source=pcm_short_write ... errno=5
```

卡已成功挂载、建会并持续读写，故障不是文件系统或扇区对齐错误。Newlib
隐藏的 `FILE` 写缓冲可能位于 PSRAM，ESP-IDF 通用 `sdmmc` 层因此在每次
扇区写入时临时申请512字节 DMA 缓冲；录音与 Wi-Fi 上传并行时该运行期申请
可能失败。

## 修复边界

- 仅实时录音的 `audio.wav` 句柄使用 `_IONBF`。
- 4096字节 PCM 写入数组固定为 `DMA_ATTR` 内部内存。
- 每64 KiB更新 WAV 头、提交 `committed_bytes` 和持久化范围 SHA 的节奏不变。
- 离线上传仍使用独立只读句柄和16 KiB固定读取缓冲。
- TCP、HTTP、SD 20 MHz、10 MiB范围、SHA和断点续传协议均不变。
- 存储失败日志新增内部内存、DMA总余量和最大连续 DMA 块。

## 验证要求

1. 实时录音并上传至少30分钟，不能出现 `sdmmc_write_sectors: not enough mem`。
2. 停止录音后核对 WAV 可播放、长度正确且最终 SHA 一致。
3. 断网录制长文件后恢复网络，验证10 MiB离线上传和断点续传。
4. 手动中断上传并重启，确认服务器从已确认范围继续。

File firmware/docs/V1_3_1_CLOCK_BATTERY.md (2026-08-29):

# Luoye V1.3.1 clock and battery maintenance release

V1.3.1 is based exactly on the clean V1.3.0 serial-upload release. It keeps
Server V0.20.2 compatibility and does not change SD recording, the 160 KiB
live upload geometry, the single uploader task, offline ranges or caption
semantics.

## Fixed behavior

- The standby home page still wakes once per minute with Wi-Fi suspended.
- Clock and battery now share one fixed 174 x 78 logical partial window.
- The SSD1681 no longer receives an unreliable tiny glyph-only auto-diff after
  panel sleep.
- A minute is acknowledged only after the panel driver reports `ESP_OK`.
- A failed transaction remains pending and is retried by the one-second UI
  scheduler.
- The existing half-hour whole-panel refresh remains unchanged.

## Battery behavior retained from V1.3.0

- MAX17048/BQ25186 are sampled every five seconds while the CPU is awake.
- Charge display rises at most one percent per 30 seconds.
- Discharge display falls at most one percent per 60 seconds, except for the
  existing low-voltage fast path.
- The home battery percentage is carried by the same minute window as the
  clock; the status page continues to refresh immediately when its displayed
  percentage changes.

## Serial acceptance

Normal minute update:

```text
LY|UI_CLOCK|refresh=clock+battery-partial ... result=ESP_OK
```

If a panel transaction fails, V1.3.1 must log `event=render_retry`, must not
advance the acknowledged minute, and must try again without enabling Wi-Fi.

Test at least 45 minutes in standby and cross both an ordinary ten-minute
boundary and a `:00` or `:30` full refresh boundary.

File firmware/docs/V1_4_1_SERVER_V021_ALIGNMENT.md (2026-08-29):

# Luoye V1.4.1 / ClearMeeting V0.21.0 alignment

V1.4.1 is a narrow compatibility release based on the proven V1.3.1
maintenance branch.  It does not import the experimental V2.x storage or
dual-task upload work.

## Runtime contract

- Device API remains `luoye-device-api/2`.
- Required server release is ClearMeeting `0.21.0`.
- Build-info must advertise `transcript_only_live_v1` and
  `canonical_offline_diarization_v2` in addition to the existing upload,
  pairing, agenda, todo and storage capabilities.
- Live recording displays captions only.  The obsolete rolling-minutes parser,
  cache and recording-page switch have been removed.
- A short MARK press during recording still uploads a timeline mark.  A long
  MARK press during recording is intentionally inert.  Standby long MARK still
  records a voice todo.

## Post-meeting boundary

The recorder owns reliable audio delivery, not server-side finalization.  The
existing upload ACK rules are retained and explicitly match V0.21.0:

1. All audio bytes and marks must be acknowledged.
2. `/end` or `/complete` must report no missing chunks/ranges.
3. `processing` is a successful durable handoff, just like `done`; the local
   upload queue can settle and the server continues canonical ASR and final
   speaker diarization independently.
4. `transcript_ready`, template selection and DeepSeek minutes generation are
   web/server concerns and are never polled by the recorder.

This prevents a several-minute canonical finalization job from holding the
device on its upload screen or keeping the upload lane busy.

## Deliberately unchanged from V1.3.1

- single uploader task;
- 160 KiB live chunks and 10 MiB range repair;
- SD recording, storage format and deletion-after-cloud-ACK rules;
- TCP/HTTP/SD performance profile;
- caption polling and five-second recording-page refresh;
- clock/battery partial refresh fix;
- power, agenda, pairing and standby scheduling.

## Acceptance checks

- V0.21.0 build-info is accepted; a server without the two V0.21 capabilities
  is rejected instead of silently restoring obsolete rolling behavior.
- Recording starts on captions and can never switch to rolling minutes.
- Short MARK still increments the meeting mark count.
- After a complete upload returns `processing`, local data follows the existing
  cloud-accepted cleanup policy without waiting for `transcript_ready`.
- All host tests, static checks and an ESP-IDF 5.5.4 clean build must pass.

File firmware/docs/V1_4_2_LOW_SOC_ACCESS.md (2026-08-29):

# Luoye V1.4.2 low-SOC recording access

V1.4.2 is a narrow maintenance release based on V1.4.1.  Its server
contract and networking behaviour remain aligned with ClearMeeting 0.21.0.

## User-visible battery behaviour

- Battery percentage is display information only.  A displayed 0%, 1%, 2%,
  3%, or 4% does not block recording or voice-todo capture.
- A percentage update never stops an active recording.
- While unplugged, the measured cell voltage supplies a calibrated low-end
  display floor: 5% at 3500 mV, 4% at 3450 mV, 3% at 3400 mV, 2% at
  3300 mV, 1% at 3150 mV, and 0% below 3150 mV.
- The existing monotonic discharge filter remains active, so a resting-voltage
  rebound cannot make the displayed percentage rise while discharging.

The low-end anchors come from `0%很耐用版本.csv`, captured on 2026-08-28.
That run first displayed 0% around 3457 mV and later reached 3061 mV before
USB power was attached.  The new tail prevents integer SOC rounding from
hiding that usable reserve as a long-lived 0% reading.

## Physical data-integrity guard

Percentage-based restrictions are removed, but the firmware still protects an
open WAV from a real brownout.  When unplugged cell voltage is at or below
3000 mV for three consecutive power polls (approximately 15 seconds), the
power manager asks the recording state machine to close the active WAV safely.
This event does not create a percentage latch and does not forbid starting a
recording merely because the UI says 0%.

## Unchanged from V1.4.1

- ClearMeeting server release 0.21.0 and `luoye-device-api/2`
- recording, upload, storage, Wi-Fi, and charging implementations
- clock refresh and dynamic battery refresh behaviour
- ESP-IDF 5.5.4 engineering build profile

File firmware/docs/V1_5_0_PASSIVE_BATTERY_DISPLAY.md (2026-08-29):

# V1.5.0 被动电量显示策略

V1.5.0 只调整用户看到的电量百分比，不改变 BQ25186 的充电寄存器、1A 充电电流、1050mA 输入限流、恒压终止和自动补充充电策略。

## 电压映射

电池电压先经过 5 次采样中值滤波，再按下列锚点做分段线性插值：

| 电压 | 百分比 | 电压 | 百分比 |
|---:|---:|---:|---:|
| 3.180V | 0% | 3.650V | 30% |
| 3.200V | 1% | 3.700V | 39% |
| 3.250V | 2% | 3.750V | 48% |
| 3.300V | 3% | 3.800V | 57% |
| 3.350V | 4% | 3.850V | 66% |
| 3.400V | 5% | 3.900V | 75% |
| 3.450V | 7% | 3.950V | 83% |
| 3.500V | 10% | 4.000V | 90% |
| 3.550V | 15% | 4.050V | 96% |
| 3.600V | 22% | 4.100V | 100% |

3.180V 以下显示 0%，4.100V 以上显示 100%。曲线在低电区下降更快，符合本机完整放电数据呈现的锂聚合物放电末端特征。

## 显示稳定规则

- 电压窗口为 5 个样本，每个样本间隔约 5 秒，取中值抑制瞬时负载和充电纹波。
- 新百分比连续确认 3 次后才成为稳定目标。
- 放电时百分比不因静置回弹而上升；10% 以上最多每分钟下降 1%，10% 以下确认后直接跟随低电目标。
- 充电时最多每 30 秒上升 1%；BQ25186 尚未报告 Charge Done 时最高显示 99%。
- BQ25186 连续确认 Charge Done 后显示 100%。
- 插拔 USB 时清空旧电压窗口；拔线后立即按当前电池电压重新定基准，避免刷机或低电启动后长期卡在 0%。

## 与设备控制解耦

- 百分比仅用于屏幕和离线 `power.csv` 诊断，不决定充电是否继续。
- 显示 0% 仍允许开始录音、继续录音和上传。
- 数据安全只保留独立物理欠压保护：未接 USB 且电压连续 3 次不高于 3.100V 时，若正在录音则安全修复并关闭 WAV。该保护不属于电量百分比策略。
- MAX17048 原始 SOC 继续写入诊断日志用于对比，但不再作为屏幕百分比或充电控制输入。

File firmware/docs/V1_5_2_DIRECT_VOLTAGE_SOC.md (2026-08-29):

# V1.5.2 纯电压电量显示

V1.5.2 将电量百分比彻底改为被动只读值：同一滤波电压永远得到同一百分比，不再保存或模拟一个独立的“电量进度”。

## 计算链路

1. 每5秒读取一次 MAX17048 的电池端电压。
2. 对最近最多5个电压样本做中值滤波；偶数个样本取中间两项的平均值。
3. 将滤波电压直接代入 V1.5.0 确定的 3.180–4.100V 分段曲线。
4. 将结果直接提交给界面，不再进行第二层百分比限速或确认。

插入或拔出 USB 时会清空旧电压窗口，新供电状态的第一个电压样本立即生效，避免充电电压和放电电压相互污染。

## 已删除的行为

- 删除充电时每30秒最多上涨1%。
- 删除放电时每60秒最多下降1%。
- 删除放电百分比不允许回升的限制。
- 删除未 Charge Done 时最高99%的限制。
- 删除 Charge Done 强制把百分比写成100%的行为。
- 删除重启后会与运行中限速状态不同的虚拟百分比状态。

因此，滤波电压达到4.100V即可显示100%，但 BQ25186 仍可能继续其恒压和终止阶段。Charge Done只控制“充电中/已充满”文字，绝不控制百分比或充电寄存器。

## 保持不变

- BQ25186 仍按原有1A充电、1050mA输入限流、恒压终止及自动补充策略工作。
- 3.180V显示0%，4.100V显示100%，中间非线性曲线不变。
- 充电页每跨5%执行一次FAST。
- 时间每分钟局刷、每10分钟FAST、每逢00分FULL。
- 显示0%不限制录音和上传；3.100V连续三次物理欠压只负责安全关闭正在写入的WAV。

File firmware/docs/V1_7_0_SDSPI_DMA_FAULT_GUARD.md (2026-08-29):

# V1.7.0 R2：SDSPI 精确长度 DMA 与故障隔离

本版以 V1.5.2 的稳定存储、录音和上传行为为功能基线，只保留
V1.6.0 R2 的纯 RAM 手动续传重启逻辑。V1.6.0 R1 的 NVS 持久化方案
不在本版中；V1.7.0 R1 改变 SD 线上字节数的方案也已撤回。

## 已确认的根因

V1.7.0 R1 为规避 ESP-IDF 5.5.4 的临时 DMA 缓冲分配，把 SDSPI
事务的实际线上长度向上补齐到4字节。最终块原本应为512字节数据加
2字节 CRC，共514字节，却被发送成516字节。

部分 SD 卡会把这两个额外时钟带入下一块边界。现场测速块应以
`0x5A` 开始，实际却以相邻块 CRC 的首字节 `0x5C` 开始；错误块计算
出的 CRC 又与日志完全相同。因此这是确定的协议边界错误，不是
FAT32、卡容量或旧文件造成的，格式化无法修复驱动根因。

复核还发现第二个确定性边界错误：中间块为下一块预读的首字节仍
指向同一个516字节缓冲，旧代码会先清空该缓冲、再复制预读字节，
等同于主动把下一块首字节改成 `0xFF`。R2 在任何缓冲复用前先把
预读内容复制到最终目标，并拒绝超出当前块长度的异常 look-ahead。

## R2 根因修复

- 工程内固定 ESP-IDF 5.5.4 的 `esp_driver_spi` 与
  `esp_driver_sdspi`，构建时核验两个覆盖组件都实际生效。
- 回移 Espressif 后续 `release/v5.5` 的 DMA 判断：ESP32-S3 的内部
  DMA 缓冲只要求地址对齐，不要求有效事务长度也是4字节倍数。
- SDSPI 在设备初始化时一次性预留516字节、4字节对齐、
  `MALLOC_CAP_INTERNAL | MALLOC_CAP_DMA` 的缓冲。
- 上传任务使用 PSRAM 栈，因此命令对象也改为全局串行保护的内部
  DMA 对象；token、busy、CRC、停止命令等全部小事务复用永久缓冲。
- 全部12处 SPI 事务使用 `SPI_TRANS_DMA_BUFFER_ALIGN_MANUAL`，地址或
  能力不满足时直接失败；SDSPI 路径不再在上传压力下临时申请任何
  TX/RX bounce buffer。
- DMA 描述符可以拥有516字节容量，但 HAL 严格按照
  `spi_transaction_t.length` 产生线上时钟：中间块最多516字节，最终
  完整块严格514字节。
- 保留 SPI 私有缓冲 OOM 清理保护，避免任何其他调用者分配失败时
  在清理路径崩溃。

## 运行期故障边界

- SD 初始化完成后进入 `READY`；确认 EIO、ENODEV、ENXIO 或 ETIMEDOUT
  后只允许转入一次 `FAULTED`。
- `FAULTED` 后不热重挂载、不继续扫描、不删除测速文件，也不继续
  `unlink`、`rename`、`fsync` 或可写文件关闭；由下一次重启完整初始化。
- uploader 在 backlog 扫描前检查 `FAULTED`，保留最后已知进度，不再
  每3秒访问卡或刷错误日志。
- 会话目录扫描区分 FOUND、END、ERROR。真实 I/O 错误不能被解释为
  队列为空；单个缺文件、坏 JSON 或孤儿目录会保留并跳过，健康会议
  仍可上传。若只剩逻辑坏目录，手动同步报告失败而不是虚假完成。

## 明确保持不变

- 10 MiB 离线范围及服务器 `upload-plan` 权威断点。
- 单上传任务、16 KiB 应用层内部 DMA 顺序读取。
- SD SPI 固定20 MHz。
- TCP发送65535、接收32768、HTTP TX 16384、TCP SACK。
- 上传期间 `WIFI_PS_NONE`，结束后恢复省电模式。
- 电量显示、充电策略、墨水屏刷新、字幕和待办逻辑。
- 不自动格式化。空 FAT32 卡仍会自动创建 `/rec`、`/diag` 和卡清单；
  exFAT、NTFS 或损坏文件系统只安全拒绝，由用户明确格式化。

## 放行标准

自动检查覆盖 `extra_data_size=0..7` 的精确线上长度与516字节描述符
容量边界，并核验本地 SPI/SDSPI 覆盖组件。真机仍需完成：128 KiB
测速逐字节比对、连续多次超过10 MiB上传、设置键中断后按服务器
缺口续传，以及故障后仅一次 `STORAGE_FAULT` 且无后续 SD 写入。

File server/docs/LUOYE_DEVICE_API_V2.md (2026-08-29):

# 落叶设备 API/2

适用版本：ClearMeeting `0.15.0`、落叶固件 `0.8.2`。契约标识为
`luoye-device-api/2`，设备接口统一位于 `/api/v2`。

ClearMeeting v0.15.0 保持设备协议兼容，并在服务器内部把设备事项同步映射到统一事项模型。
设备上传协议和固件请求格式没有变化；网页通过现有活动会话和旁听 WebSocket
接收字幕与 `meeting_update`，因此 v0.8.2 固件无需重新烧录。

## 1. 音频和认证

- PCM S16LE、16 kHz、单声道、16 bit；一个采样 2 字节。
- 设备请求携带 `X-Luoye-Protocol`、固件版本和设备 ID。
- 配对后使用与账号、设备和 `binding_generation` 绑定的设备 Bearer token；解绑后旧 token 立即失效。
- 创建会话、实时分片、MARK、切换实时 epoch、延迟补洞和完成请求均支持幂等重放。

## 2. 在线录音

设备先调用 `POST /api/v2/device/sessions` 创建会议，再按 160 KiB 调用：

`PUT /api/v2/device/sessions/{server_id}/audio/{seq}`

请求携带绝对 `X-Byte-Offset`、长度和 SHA-256。服务器分别返回：

- `acknowledged_bytes`：从文件开头连续完整的权威进度；
- `live_acknowledged_bytes`：当前实时 epoch 的最新进度。

两条游标分离，保证网络恢复后实时字幕不需要等待旧缺口补完。

## 3. 录音中断网和恢复

断网期间录音始终继续写入 SD。恢复网络且录音仍在进行时，设备调用：

`POST /api/v2/device/sessions/{server_id}/live-resume`

请求给出缺口开始字节和当前录音字节。服务器登记新的实时 epoch，设备立即上传当前声音；断网期间的旧音频仍留在 SD，不占用实时通道追赶。

录音停止时，如存在缺口，设备调用：

`POST /api/v2/device/sessions/{server_id}/defer`

服务器将会议置为 `awaiting_repair` 并返回缺失范围。服务器重启恢复会跳过该状态，不会在用户同步前提前结束会议。

## 4. 手动同步和 10 MiB 补洞

用户长按中间键进入同步页，再单击中间键确认。固件调用 `upload-plan` 获取缺失范围，并以最大 10 MiB 的逻辑范围调用 `audio-range`。服务器按绝对字节偏移重建完整 PCM，再按时间轴识别并插入断网遗漏内容。没有 2 MiB 自动降级。

全部范围、MARK 和元数据到齐后调用 `complete`。只有服务器验证从字节 0 到文件末尾无缺口，会议才进入后台处理。

## 5. SD 删除完全独立

网页端的单项删除和一键删除全部，仅向对应录音卡下发本地删除命令：

- 不调用会议 `cancel`；
- 不删除云端会议、字幕、纪要、待办或音频；
- 不检查上传状态、会议状态或录音年龄；
- 正在录音的文件由固件等到安全收尾后再执行，本地删除结果通过命令 ACK 返回。

因此，网页“会议历史删除”和“设备 SD 删除”是两套互不关联的业务。

## 6. 关键端点

| 用途 | 方法与路径 |
|---|---|
| 兼容检查 | `GET /api/v2/build-info` |
| 配对 | `POST /api/v2/device/pair/start`、`pair/status` |
| 创建录音 | `POST /api/v2/device/sessions` |
| 在线分片 | `PUT /api/v2/device/sessions/{id}/audio/{seq}` |
| 恢复当前实时音频 | `POST /api/v2/device/sessions/{id}/live-resume` |
| 结束并等待补洞 | `POST /api/v2/device/sessions/{id}/defer` |
| 获取补洞计划 | `POST /api/v2/device/sessions/{id}/upload-plan` |
| 上传 10 MiB 范围 | `PUT /api/v2/device/sessions/{id}/audio-range` |
| 补洞完成 | `POST /api/v2/device/sessions/{id}/complete` |
| SD 清单和命令 | `/api/v2/device/storage/*`、`/api/v2/me/devices/*/storage*` |

## 7. 调度优先级

录音写 SD 独立于网络任务。云请求同一时刻最多执行一个，优先级为：在线音频/字幕、录音收尾、用户手动同步、语音待办、议程、SD 清单与删除命令。失败任务只记录自己的重试时间，不以长延时阻塞整个调度器。

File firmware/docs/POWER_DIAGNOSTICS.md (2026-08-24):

# 电量离线诊断

本版本按 1000mAh、3.7V 单节聚合物锂电池设置 BQ25186：

- ICHG 请求值固定为 1000mA；
- 输入限流为 1050mA；
- BQ25186 负责 CC、CV、ITERM 和自动再充电；
- MAX17048 只用于估算电量，不再用它的 100% 提前停止充电；
- BQ25186 连续两次 5 秒采样报告 Charge Done 后，UI 显示 100%；
- USB 在位但尚未 Charge Done 时，UI 最高显示 99%。
- 放电显示使用 2026-08-20 实测曲线进行单调分段校准；
- 正常放电段最多每分钟追降 1%，低于 10% 或电压不高于 3.55V 时立即服从
  安全低电量，防止显示虚高。

实际电池充电电流可能因系统负载、输入限流、DPPM、VINDPM 或热调节而低于
1000mA。诊断时必须同时观察相应状态位。

## 离线日志

日志不依赖 Wi-Fi、账号或服务器。SD 成功挂载后，固件每 60 秒追加一行：

`/sdcard/diag/power.csv`

同一条摘要也会通过 USB 串口输出，前缀为：

`LY|POWER_DIAG|`

CSV 主要字段：

| 字段 | 含义 |
|---|---|
| `epoch_utc` | RTC/SNTP 可用时的 UTC 秒；未校时以 `uptime_s` 为准 |
| `recording` | 1 表示采样时正在写录音，可用于比较录音与待机掉电速度 |
| `gauge_soc` | MAX17048 原始 SOC，保留两位小数 |
| `filtered_soc` | 实测分段校准后，再进行三点中值滤波的 SOC |
| `displayed_soc` | 屏幕实际显示值 |
| `mv` | MAX17048 VCELL 换算的电池电压 |
| `usb` | 1 表示 BQ PG 检测到输入电源 |
| `charge_state` | 0=未充电，1=充电中，2=已充满 |
| `bq_phase` | 0=空闲，1=CC，2=CV，3=Charge Done |
| `ichg_ma` | BQ25186 ICHG 寄存器请求值，不等于瞬时实测电流 |
| `ilim_ma` | 输入限流设置 |
| `stat0/stat1` | BQ25186 原始状态和故障寄存器 |
| `max_config` | MAX17048 CONFIG/RCOMP |
| `max_hibrt` | MAX17048 休眠阈值 |
| `max_status` | MAX17048 STATUS |
| `max_version` | MAX17048 VERSION |
| `voltage_fallback` | 1 表示 SOC 读取失败，UI 使用了电压兜底 |

## 建议测试流程

1. 从低于 10% 开始，断开网络或不配置 Wi-Fi也可以；
2. 插入稳定的 5V、至少 2A 电源；
3. 充到 `bq_phase=3` 和 `charge_state=2`，确认屏幕显示 100%；
4. 拔掉 USB，按正常场景录音放电到低电安全收尾；
5. 保存完整 `power.csv`，不要只截取百分比；
6. 分析 CC/CV 时间、VCELL、原始 SOC、显示 SOC，以及 ILIM/DPPM/热调节状态。

此日志不能测量真实电流。若要区分电量计误差和真实功耗，仍需用 USB 功率计、
电源分析仪或串联电流表测量输入/电池电流。

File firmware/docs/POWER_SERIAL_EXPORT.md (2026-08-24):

# 电量日志串口导出

固件通过 USB Serial/JTAG 提供只读命令，不把 SD 卡挂成电脑磁盘，也不会格式化、
删除或改写原有日志。

## 一键导出

1. 停止录音并用 USB 连接设备；
2. 双击 `EXPORT_POWER_CSV.bat`；
3. 如果电脑有多个串口，运行 `EXPORT_POWER_CSV.bat COM23`，把 COM23 换成实际端口；
4. 工具收到全部 Base64 数据块并通过长度、SHA-256 双重校验后，才会保存
   `power-YYYYMMDD-HHMMSS.csv`。

电脑需要 Python 和 pyserial。ESP-IDF 环境通常已经带有 pyserial；缺少时运行：

```powershell
python -m pip install pyserial
```

## 手工串口命令

用 115200 波特率打开串口后可以输入：

- `power_info`：只查看 `/diag/power.csv` 的大小和 SHA-256；
- `power_export`：输出带序号的 Base64 数据块；
- `power_help`：显示命令摘要。

录音过程中导出会返回 `recording_active`，防止读取 SD 卡影响录音写入。

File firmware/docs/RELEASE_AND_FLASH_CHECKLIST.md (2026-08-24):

# 落叶固件构建、烧录与发布门禁

> 适用项目：落叶（Luoye）Recorder Card
> 核心规则：**未达到 `READY_TO_FLASH` 的版本不烧录；未通过真板验收的版本不标记完成。**

## 1. 构建类型

| 类型 | 版本示例 | 允许用途 | 禁止用途 |
|---|---|---|---|
| Dev | `v0.2.0-dev.3` | 开发板调试、专项验证 | 交付、量产 |
| RC | `v0.2.0-rc.1` | 完整版本验收 | 量产 |
| Accepted | `v0.2.0` | 下一版本开发基线 | 对外正式发布 |
| Release | `v1.0.0` | 正式交付和生产 | 未审批变更 |

## 2. READY_TO_FLASH 前置检查

### 源码

- [ ] 当前工作树无来源不明的修改。
- [ ] 当前 commit 已记录。
- [ ] `PROJECT_VER` 与计划烧录版本一致。
- [ ] 本版本目标清单已全部完成。
- [ ] 不包含 WiFi 密码、账号密码、Token、私钥或生产证书。
- [ ] `board_pins.h` 与目标 PCB 硬件版本一致。
- [ ] 分区表变更已经单独评审。
- [ ] NVS/manifest schema 变更有迁移与回滚方案。

### 自动测试

- [ ] 状态机 PC 回归测试通过。
- [ ] 本版本新增单元测试通过。
- [ ] API 协议测试向量通过。
- [ ] 静态检查和编译警告检查通过。
- [ ] 若修改存储：断电恢复测试通过。
- [ ] 若修改上传：重复 chunk/final 幂等测试通过。
- [ ] 若修改账号：账号隔离和 Token 吊销测试通过。
- [ ] 若修改 OTA：升级失败和自动回滚测试通过。

### 干净构建

在“ESP-IDF 5.5 CMD/PowerShell”中执行：

```powershell
cd /d D:\OPENOP\recorder-card-hw-test\firmware\recorder-card
idf.py set-target esp32s3
idf.py fullclean
idf.py build
```

- [ ] 使用路线图指定的 ESP-IDF 版本。
- [ ] `idf.py build` 返回 0。
- [ ] 记录 app、IRAM、DRAM、Flash 和分区占用。
- [ ] 检查没有越过分区或内存预算。
- [ ] 保存完整 build log。

## 3. 产物归档

每个候选版本建立：

```text
releases/<version>/
  recorder_card.bin
  bootloader.bin
  partition-table.bin
  assets.bin
  flash_args
  build.log
  serial-COMxx.log
  manifest.json
  TEST_REPORT.md
  RELEASE_NOTES.md
```

`manifest.json` 至少记录：

```json
{
  "version": "v0.2.0-rc.1",
  "git_commit": "<40-char sha>",
  "idf_version": "v5.5.4",
  "hardware_revision": "<pcb revision>",
  "build_utc": "<ISO-8601>",
  "app_sha256": "<sha256>",
  "bootloader_sha256": "<sha256>",
  "partition_sha256": "<sha256>",
  "assets_sha256": "<sha256>",
  "sdkconfig_sha256": "<sha256>",
  "api_contract_version": "<contract version>",
  "server_release_id": "<server release>",
  "minimum_client_version": "<app version>"
}
```

- [ ] 所有文件存在。
- [ ] 所有 SHA-256 已重新计算并写入 manifest。
- [ ] manifest 的 commit 与源码一致。
- [ ] API contract、服务器 release、数据库 migration 和客户端兼容范围已记录。
- [ ] 上一个 accepted 版本 release 包仍完整可用。

## 4. 烧录前检查

- [ ] 确认目标板编号、PCB 版本和芯片型号。
- [ ] 确认串口号，不能凭上一次 COM 号假定。
- [ ] 关闭占用串口的 monitor、串口助手和其它程序。
- [ ] 确认目标是开发板、RC 板还是量产板。
- [ ] 保存当前 accepted 版本的回滚产物。
- [ ] 分区表或 NVS schema 变化已明确是否需要擦除。
- [ ] 普通版本禁止执行 `erase_flash`，除非版本说明明确要求且用户批准。
- [ ] 普通烧录禁止执行任何 eFuse 命令。

推荐先验证芯片连接：

```powershell
esptool.py --chip esp32s3 -p COMxx chip_id
```

烧录候选版本：

```powershell
cd /d D:\OPENOP\recorder-card-hw-test\firmware\recorder-card
idf.py -p COMxx flash monitor
```

退出 monitor：

```text
Ctrl + ]
```

## 5. 烧录后通用冒烟测试

- [ ] 串口打印的版本、commit、硬件版本与 manifest 一致。
- [ ] Reset reason 符合预期，无 boot loop 或 panic。
- [ ] Flash、PSRAM 初始化正常。
- [ ] 红、黄、绿 LED 状态正确。
- [ ] 墨水屏方向、镜像和文字正确。
- [ ] REC、MARK、BACK、BOOT 按键正常。
- [ ] BQ25186、MAX17048、PCF8563 正常。
- [ ] RTC 时间与电池电量合理。
- [ ] 双麦能够采集且左右输入均非固定值。
- [ ] SD 可挂载、写入、关闭和播放 WAV。
- [ ] WiFi 和服务器状态符合本版本能力。
- [ ] 无明显任务栈、内存、看门狗或 BUSY 超时错误。

## 6. 版本专项测试

每个版本必须执行路线图对应的真板验收；以下故障测试不得省略：

### 存储

- [ ] 录音时拔卡。
- [ ] 卡满/短写。
- [ ] close/fsync 前后复位。
- [ ] 启动时无卡、启动后插卡。
- [ ] 新旧 SD 卡 volume identity 不同。

### 网络和上传

- [ ] WiFi 断开/恢复。
- [ ] DNS、TLS、超时和 5xx。
- [ ] 401、403、409、413、429。
- [ ] chunk 已收但 ACK 丢失。
- [ ] final 已收但 ACK 丢失。
- [ ] 旧会话未完成又创建新会话。

### 电源

- [ ] 低电量告警。
- [ ] 临界电量安全收尾。
- [ ] USB 插拔和充满。
- [ ] 录音中请求关机。
- [ ] RTC 和按键深睡唤醒。

### 账号和隐私

- [ ] 账号 A/B 数据隔离。
- [ ] 设备解绑后旧 Token 失效。
- [ ] 换绑时旧 backlog 不上传给新账号。
- [ ] 删除/保留策略符合产品规则。

## 7. 判定规则

### 允许标记 BOARD_PASS

- 通用冒烟测试全部通过。
- 本版本专项测试全部通过。
- 串口无未解释的 panic、WDT、SD 写错和协议错误。
- 所有测试证据已保存。

### 必须判定失败并回滚

- 版本/commit 与 manifest 不一致。
- 启动循环、panic 或看门狗复位。
- 录音界面显示正常但 WAV 未写入。
- 会话未闭合却允许关机或新录音。
- 服务器 ACK 未确认却删除本地音频。
- 账号之间可看到对方会议。
- TLS 失败后降级为 HTTP。
- OTA 失败后无法回到旧版本。

回滚后：

- [ ] 记录失败版本和复现步骤。
- [ ] 保留失败串口日志和产物，禁止覆盖。
- [ ] 状态退回 `IN_PROGRESS`。
- [ ] 修复后增加 `dev.N` 或 `rc.N`，不得复用同一版本号。

## 8. 单次烧录记录模板

```text
烧录时间：
操作者：
设备编号：
PCB版本：
串口：
固件版本：
Git commit：
ESP-IDF版本：
构建类型：Dev / RC / Accepted / Release
是否修改分区：
是否擦除NVS：
App SHA-256：

烧录命令：
烧录结果：
启动结果：
冒烟测试：
专项测试：
串口日志路径：
发现问题：
回滚版本：
最终结论：FLASHED / BOARD_PASS / FAILED / ACCEPTED
```

## 9. eFuse 安全红线

下列命令或动作不属于普通固件烧录，必须单独批准：

- Secure Boot key digest 烧录。
- Flash Encryption Release 模式启用。
- 禁用 UART 下载、USB 下载或 JTAG。
- Anti-rollback `secure_version` 推进。
- 任何 `espefuse.py burn_*` 操作。

开发阶段只准备配置、镜像和验证流程，不执行不可逆烧录。

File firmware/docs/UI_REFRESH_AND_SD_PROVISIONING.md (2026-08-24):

# UI refresh and replacement SD-card behavior

## E-paper refresh policy

- The home clock wakes on each minute boundary and refreshes only the clock
  rectangle (`24,24,152,58`).
- At minute `00` and `30`, the visible clock page uses a FULL waveform to clear
  accumulated partial-refresh ghosting.
- Reconnecting Wi-Fi and refreshing the account binding while the home page is
  visible update cached state only; they do not repaint the panel.
- Entering/leaving the settings status page uses a full-screen partial window.
  Subsequent network, cloud, storage and battery changes refresh only the
  status area (`0,28,200,170`).
- The active recording body keeps its five-second partial refresh and uses a
  whole-panel FAST refresh every five minutes to bound accumulated ghosting.

## Blank or replacement SD cards

Boot follows this order:

1. Try four normal FAT/FAT32 mounts, including the existing SPI idle-clock
   recovery. Automatic formatting is always disabled.
2. Create `/rec` and `/diag` when missing.
3. Perform a durable create/write/fsync/close/delete probe.
4. Create `/luoye-card.json` on a card not previously initialized by Luoye.
5. Recover interrupted sessions before enabling recording.

ESP-IDF v5.5.4 has exFAT disabled in its FatFs component. An exFAT, NTFS or
unformatted card is left untouched and reported unavailable. Format a truly
blank replacement card as FAT32 on a computer before installing it.

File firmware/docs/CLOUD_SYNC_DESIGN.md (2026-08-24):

# 落叶 v0.7.0 API v1 手动历史同步设计

适用固件：`v0.7.0-ui154-r2.11-syncqueue-r1`

设备 API：`luoye-device-api/1`

状态：`DEVICE + SERVER IMPLEMENTED / BOARD PENDING`

## 核心规则

- 每段录音都是独立会话，目录、会话 ID 和上传进度互不覆盖。
- 当前录音在线时读取最近一次 `fsync` 的安全边界并实时上传；闭合后继续完成尾片、MARK 和 final。
- 旧的已闭合历史会话默认不抢占网络；用户长按中间键进入同步页并确认后，才按最早优先 FIFO 上传。
- 活动会话只发送完整 160 KiB 分片；闭合后才发送不足一整片的尾部。
- 每个 160 KiB 分片在发送前计算 SHA-256。
- 云端 PCM 分片固定使用 `Content-Type: audio/L16;rate=16000;channels=1`；
  语音待办 WAV 仍使用 `audio/wav`。
- 分片携带字节 offset/count/SHA；ACK 的 `next_seq`、`received_samples` 和
  `acknowledged_bytes` 必须形成同一个连续确认点，并至少覆盖本次分片，否则拒绝推进。
- create、audio chunk、marks、final 各自使用稳定幂等键。
- `upload.state` 使用临时文件、`fflush + fsync`、备份和 rename 原子更新，并镜像到 `session.json`。
- `final_ack=true` 持久化后立即进入本地删除阶段；云端已经接管完整音频和处理任务。
- `marks.jsonl` 按物理行流式读取，每行使用稳定的 `mark-N` PUT；总文件可超过
  16 KiB。断网重启从首行幂等重放，单条损坏或超长记录会被记录并跳过，不阻塞音频收尾。
- 云端完整确认后自动删除对应本地 WAV 和会话目录。
- 网页可在任意时间下发删除命令，不要求录音先上传完成；如果目标仍在写入，命令留在服务器排队，WAV 安全闭合后设备自动重试执行。

## 工作流

```text
local_closed/recovered
  -> wait for middle-key sync confirmation
  -> create session (幂等)
  -> chunk 0..N (每片 ACK 后持久化)
  -> marks (幂等)
  -> final (幂等)
  -> persist final ACK
  -> atomic local delete
```

活动会话在 create/chunk 之间轮询 live revision，保证字幕时效。活动会话关闭并完成
云端 final 后才释放实时通道；手动历史同步随后从最早一场继续。设备重启后不存在
“前台会话”持久特权，所有未完成历史会话重新等待用户确认同步。

断网、超时、429 和 5xx 进入指数退避，3 秒起步、随机抖动、最大 5 分钟。
401/403 清除失效 Device Token、保留 WiFi 和所有本地会话，并自动生成新配对材料
回到认领流程；普通 409 与 400/413/422 等
协议错误停止该会话上传。只有 end 返回明确 `AUDIO_CHUNKS_MISSING` 才回退补片。

## 账号隔离

创建录音时把当前 `binding_generation` 固化进会话。未绑定时录制的会话不自动归属
后续账号；重新绑定后，旧 generation 的积压不会上传给新账号。

## 当前验收点

服务端接口已经实现。仍需真板注入断网、超时、重复分片、响应丢失、缺片、重启和解绑，
验证每种情况下服务端只有一份音频、设备断点不倒退、旧账号录音不泄漏，并且只有
final ACK 或明确网页删除命令能清除已闭合本地目录。

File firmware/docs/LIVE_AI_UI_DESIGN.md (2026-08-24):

# 落叶 v0.6.1 实时字幕、翻译与墨水屏设计

适用固件：`0.6.1-cloud-v1`

设备 API：`luoye-device-api/1`

交互基准：250×122 HTML 真机像素模拟器

状态：`DEVICE + SERVER IMPLEMENTED / END-TO-END PENDING`

## 数据流

```text
PDM -> SD WAV
          |
          +-> 64 KiB 周期修头、fflush、fsync
          |
          +-> 仅从 committed boundary 读取
                 -> 完整 160 KiB 活动分片
                 -> HTTPS 幂等上传 + 精确 ACK
                 -> GET state?after_revision=N
                 -> 会话/游标/偏移/文本校验
                 -> RAM 最新结果快照
                 -> 墨水屏约 15 秒节流刷新
```

SD 仍是录音真源。网络线程不得读取 writer 尚未 `fsync` 的数据；活动录音的不足
160 KiB 尾部不能提前发送，否则一次失败重试可能让同一个幂等键对应不同正文。
只有会话闭合后才能上传不足一整片的最终尾片。
create 请求不携带会持续变化的 PCM 长度，保证响应丢失后同一 create 幂等键重试时
请求正文仍完全一致；最终长度只在 end 请求中提交。

## 结果一致性

- 服务端为每个活动会话维护单调 `revision`。
- 每个结果带 `upload.received_samples`，设备换算为连续 PCM 字节确认点。
- 设备只接受严格递增 revision、不倒退的连续偏移和不超过本地 ACK 的偏移。
- 原文和译文必须放在同一 translation 对象、同一 revision 中返回。
- 新会话开始时清空旧 RAM 结果，禁止跨会话串字幕。
- `result_revision` 与 `result_pcm_bytes` 写入 `upload.state`，断网恢复后从正确游标继续。
- final 确认云端已完整接管音频与后处理任务；设备持久化 ACK 后删除本地副本，
  最终结果继续在网页端生成，不再占用设备历史同步队列。
- state 只携带游标后的最新受限结果，整个响应不超过设备 8191-byte JSON 上限。
- 正文不写工程日志；本版本也不把完整云字幕另存到 SD。

## 页面映射

### 待机

- 主页：真实 RTC 时间、日期、场景和“暂无同步日程”。日程同步属于 v0.6，不显示
  虚构课程或会议。
- 充电页：USB-C、实际电量、REC/BACK/MARK 操作提示。
- 设备状态页：WiFi、云 API、账号绑定、固定式 SD、充电和固件版本。
- 配网页、绑定页、关机页、提醒页和错误页沿用现有真实状态机。

### 会议录音（2 页）

1. 字幕页：最新 meeting text 显示窗口；离线时明确显示本地保存和稍后补传。
2. 状态页：时长、SD、积压、网络、重点和待办计数。

### 翻译录音（3 页）

1. 译文页：一行原文 + 大字译文。
2. 双语页：同一 revision 的原文与译文上下对照。
3. 状态页：时长、SD、积压、网络、收藏和待办计数。

BACK 循环翻页；REC 暂停/继续，长按结束；MARK 在会议页标重点、翻译页收藏；
长按 BACK 锁键。重要状态立即刷屏，纯正文更新约 15 秒一次，控制墨水屏闪烁和寿命。

## 真实性边界

- 未绑定或云 API 不可用时，不显示字幕/译文，只显示本地录音事实。
- 服务器只返回 `202/204/304` 时，保留上一 revision，不虚构新内容。
- 收尾页只有在本地 WAV 安全闭合后才显示“本地已保存”；只有云可用时才显示
  “纪要生成中/双语生成中”。
- 今日议程、语音待办入日历、最终纪要和完整历史查看依赖后续服务器/客户端，
  不属于本版本设备端完成项。

## 真板验收

1. 会议模式说话 2 分钟，屏幕只显示来自服务器的 revision，正文刷新间隔约 15 秒。
2. 翻译模式核对每屏原文和译文 revision 相同，BACK 三页循环正确。
3. 断网继续录音，显示本地状态；恢复网络后补分片并继续增加 revision。
4. 注入旧 revision、偏移回退、跨会话 ID 和超长/非法 UTF-8，设备全部拒绝。
5. 连续刷新 4 小时，无错位、镜像、严重残影、栈溢出或持续内存下降。
6. 串口日志只出现长度、revision、偏移和状态，不出现会议正文。

上述接口已经实现，但必须完成真板长录音、断网恢复、旧 revision 注入和双账号隔离
测试后，才能标记 `BOARD_PASS` 或 `ACCEPTED`。

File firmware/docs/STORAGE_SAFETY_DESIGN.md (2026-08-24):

# 落叶 v0.2.0 存储安全设计

适用版本：`0.2.0-dev.1`

## 不变量

1. 屏幕只有收到 `SESSION_CLOSE_DONE` 后才能显示“本地已保存”。
2. `STARTING`、`RECORDING`、`CLOSING` 期间不得开始第二段录音或进入深睡眠。
3. 任意 `fwrite`、`fflush`、`fsync`、`fclose` 失败都进入 `STORAGE_ERROR`，不能继续显示正在录音。
4. 上传器只能读取 `pcm_bytes_committed`，不能读取尚未同步到卡的数据。
5. 每次录音使用“设备 MAC + NVS 单调计数器 + 随机数”生成唯一会话 ID。

## 会话目录

```text
/sdcard/rec/<session-id>/
  session.json
  audio.wav
  marks.jsonl
  upload.state
```

会话创建成功的判据是四个文件均已创建并完成 `fflush + fsync`。`session.json`
以临时文件写入，再替换正式文件。

## 状态与收尾

```text
STANDBY -> STARTING -> RECORDING -> CLOSING -> ENDING -> STANDBY
                      |             |
                      +------ STORAGE_ERROR
```

- `STARTING`：创建会话目录和四个文件，写入可恢复的空 WAV 头。
- `RECORDING`：每 4 KiB 检查短写并刷新 C 库缓冲；每 64 KiB 更新 WAV 头并 `fsync`。
- `CLOSING`：停止麦克风、排空音频环形缓冲、修正 WAV 头、同步并关闭文件，
  原子更新 `session.json`。
- `ENDING`：只在上述步骤全部成功后显示“本地已保存”。
- `STORAGE_ERROR`：停止采集，保留可修复文件，显示具体错误并阻止新录音。

## 断电恢复

挂载 SD 后扫描 `/sdcard/rec/*`：

1. 按 `audio.wav` 实际长度对齐到完整 16-bit PCM 帧；
2. 截断半个样本，重写 44 字节 WAV 头并同步；
3. 将 `marks.jsonl` 截到最后一个换行，移除断电造成的半条 JSON；
4. 将未闭合会话标为 `recovered`，记录修复次数和关闭原因；
5. 保留 `upload.state`，供后续版本断点上传。

## v0.2.0 真板验收

- 录音中拔卡：界面立即退出“录音中”，且不能显示“已保存”。
- 卡写满：已有 WAV 可播放，最后一个完整样本不被破坏。
- 录音中复位/断电：重启自动修复，修复后的 WAV 可播放。
- 连续录音 2 小时：音频丢弃计数为 0；若非 0，日志和会话元数据必须可见。
- 低电临界：停止麦克风、排空缓冲并完成同步后才允许关机。

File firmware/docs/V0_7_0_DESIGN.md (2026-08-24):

# 落叶 v0.7.0 电源、RTC、长稳与固定 SD 管理

版本：`0.7.0`
服务端：ClearMeeting `0.13.0`
协议：`luoye-device-api/1`（新增 `storage_management` 能力）

## 固件行为

- 电量低于或等于 5% 后锁定新录音和新语音待办；充电或恢复到 8% 才解除，避免阈值抖动。
- 录音中电量到 3% 时复用可靠录音收尾路径，先完成 WAV 头、日志与同步，再退出录音。
- MAX17048 读失败时按电池电压保守估算电量；正常样本使用三点中值滤波，临界低电量不延迟。
- PCF8563 的 VL、校时差值、闹钟设置和真实唤醒来源写入结构化串口日志。
- GPIO41 不是 RTC IO：存在日程提醒时使用 light sleep 等待 PCF8563 INT；无提醒时使用按键深睡唤醒。
- 每 10 分钟输出 uploader 堆、最大连续内存、PSRAM、栈余量和补传积压诊断。

## 固定式 SD 管理

- 设备分页上报总容量、可用容量、本地会话、上传状态与是否允许删除。
- 网页删除命令可以在设备离线时排队；上线后设备执行并回执。
- 删除前设备重新读取持久 manifest。仅当会话已关闭、PCM 全部分片确认、MARK 确认、final 确认且绑定代次一致时才允许删除。
- 默认自动策略：低于 15% 可用空间时，删除 30 天前的已上传副本，直到达到 20%；服务器可修改或关闭策略。
- 删除只影响录音笔本地副本，不删除云端会议、字幕、纪要或待办。

## 自动化门禁

- ESP-IDF v5.5.4 编译与分区容量检查。
- 状态机、掉电 WAV 修复、配网表单、上传协议、字幕协议、议程协议主机测试。
- 服务端账号隔离、存储清单、不可删除会话拒绝、命令投递与回执测试。
- Web Client 单元测试与生产构建。

72 小时运行、200 次录音收尾、断网补传、异常断电、RTC 多次唤醒和 SD 满载属于真板验收，由用户执行，不计入自动化构建通过。

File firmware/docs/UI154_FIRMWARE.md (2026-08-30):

# 落叶 1.54 寸方屏固件

## 目标

- 面板：Good Display `GDEY0154D67`
- 控制器：`SSD1681`
- 分辨率：`200 × 200`，黑白 1-bit
- 原有 ESP32-S3、双麦、SD、I²C、电源、配网、绑定、上传、议程与待办逻辑继续复用
- 页面视觉唯一来源：`D:\OPENOP\AI录音卡\UI设计图`

## 显示实现

`tools/gen_ui154_assets.py` 按 `docs/luoye_ui_layout_23pages_with_icons.json` 生成
23 个行优先、MSB 在左、`1=黑` 的 5000 字节页面资源。较低阈值不会把
设计图的灰色抗锯齿边缘误判为黑色，因此小字笔画更细、更清楚。生成结果位于
`assets/ui154/`，并随 `assets.bin` 一起烧录。

页面装饰、叶片、曲线、构图和静态文案直接使用设计图取模结果；以下字段在运行时覆盖：

- 时钟、日期和电量
- 今日日程和下一项日程
- Wi-Fi、云端、上传积压和存储状态
- 录音时长、暂停、锁键和安全收尾
- 录音开始时立即显示首帧；实时字幕/章节纪要在自然分钟边界刷新
- 第 23 页“本段纪要”的时间范围、章节标题和两条动态要点
- SoftAP 名称、密码、配对码和绑定账号
- 语音待办文本、时间和日程提醒

SSD1681 首帧用 `0xF7` 建立黑白基准；后续页面使用随屏幕模组提供的 GDEY0154D67
原厂快速初始化序列（`0xB1 → 0x1A/0x64 → 0x91`）和 `0xC7` 快刷。RAM 地址方向沿用
本项目已经验证的方向，因此移植快刷波形不会改变页面朝向。

## 按键定义

| 状态 | REC | BACK | 中间键 |
|---|---|---|---|
| 待机 | 短按开始会议；按住说语音待办，松开保存 | 短按主页/日程/状态翻页；长按 3 秒配网 | 长按进入同步确认页 |
| 同步确认 | 无动作 | 短按取消并回主页 | 短按开始按时间顺序上传历史录音 |
| 同步进行 | 无动作 | 短按回主页，后台继续上传 | 无动作 |
| 录音 | 短按暂停/继续；长按 1.5 秒安全结束 | 短按字幕/状态翻页；长按 3 秒锁键或解锁 | 无动作 |
| 提醒 | 短按开始会议 | 短按关闭；长按 3 秒推迟 10 分钟 | 无动作 |
| 待办确认 | 短按确认 | 短按取消 | 无动作 |

硬件电源开关负责整机断电，因此待机长按 REC 不再承担软件关机。

## 构建与烧录

当前验证构建目录为 `build-v170`，服务器地址为
`http://meeting.example.invalid:34567`。在 ESP-IDF 5.5 CMD 中执行：

```bat
cd /d D:\LUOYE_PROJECT_HANDOFF_2026-08-19\01_FIRMWARE\maintenance\recorder-card-v1.7.0
powershell -ExecutionPolicy Bypass -File tools\build_profile.ps1 -Profile engineering -ServerBaseUrl http://meeting.example.invalid:34567 -AllowInsecureHttp
idf.py -B build-v170 -p COM22 flash monitor
```

也可使用最终 FLASH 包里的 `flash_COM22.bat`。

## 真板首轮验收

1. 开机首帧允许做一次完整基准刷新，之后页面应为快速刷新。
2. 确认待机页方向、镜像和文字朝向正确。
3. BACK 连按两次，核对日程页、设备状态页。
4. 短按 REC，核对准备页、字幕页和红色录音灯。
5. 再短按 REC，核对暂停页；短按继续，长按结束，核对保存页。
6. 待机按住 REC 说一句待办，松开后核对识别与确认页。
7. 待机长按中间键进入同步确认页；短按 BACK 应取消，重新进入后短按中间键应开始上传。

如果方向不对，只调整 `components/epd_ssd1681/include/epd_ssd1681.h` 中的
`EPD_SWAP_XY / EPD_FLIP_X / EPD_FLIP_Y`，不修改 UI 坐标和页面资源。

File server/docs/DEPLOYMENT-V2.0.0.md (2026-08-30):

# ClearMeeting Server V2.0.0 部署说明

V2.0.0 是已稳定运行的 V0.21.0 R9 的正式版本升级。除版本标识外，不改变
上传、实时与离线转写、多人声纹、模板纪要、会议记忆或导出行为；设备 API
契约继续为 `luoye-device-api/2`，数据库仅沿用既有兼容迁移。

## 部署

```bash
cd /srv/clearmeeting
unzip -q clearmeeting-server-v2.0.0-stable-r1.zip -d clearmeeting-v2.0.0-stable-r1

# 1. 备份数据库与生产配置
mkdir -p /srv/clearmeeting/clearmeeting-backups/v2.0.0-predeploy
cd /srv/clearmeeting/clearmeeting/deploy
docker compose exec -T server python -c "import sqlite3; s=sqlite3.connect('/app/data/clearmeeting.db'); d=sqlite3.connect('/app/data/clearmeeting.db.pre-v2.0.0'); s.backup(d); d.close(); s.close()"
cp -p .env /srv/clearmeeting/clearmeeting-backups/v2.0.0-predeploy/deploy.env

# 2. 更新程序，保留会议数据、密钥和生产配置
rsync -a --delete \
  --exclude 'server/data/' \
  --exclude 'deploy/.env' \
  /srv/clearmeeting/clearmeeting-v2.0.0-stable-r1/ /srv/clearmeeting/clearmeeting/

cd /srv/clearmeeting/clearmeeting/deploy
if grep -q '^SERVER_RELEASE=' .env; then
  sed -i 's/^SERVER_RELEASE=.*/SERVER_RELEASE=clearmeeting-server-v2.0.0/' .env
else
  echo 'SERVER_RELEASE=clearmeeting-server-v2.0.0' >> .env
fi

# 3. 只重建业务服务与网页代理，不重新构建 ASR 模型
docker compose --profile real-asr --profile offline-asr-cpu build server nginx
docker compose --profile real-asr --profile offline-asr-cpu up -d server nginx

EXPECTED_SERVER_VERSION=2.0.0 bash ./verify_api_v2.sh http://127.0.0.1
```

验收时 `/api/v2/build-info` 必须返回：

```json
{
  "server_version": "2.0.0",
  "server_release": "clearmeeting-server-v2.0.0",
  "api_contract": "luoye-device-api/2"
}
```

## 回退

将部署前代码备份同步回 `/srv/clearmeeting/clearmeeting`，保留 `server/data` 与
`deploy/.env` 后重建 `server nginx`。若程序回退仍不足，停服务后再恢复
`clearmeeting.db.pre-v2.0.0`；数据库恢复前应先额外保存当前数据库。

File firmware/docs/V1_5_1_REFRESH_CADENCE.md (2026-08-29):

# V1.5.1 墨水屏刷新节奏

V1.5.1 只调整墨水屏刷新调度，保留 V1.5.0 的被动电量曲线、充电参数、录音、上传和日程同步策略。

## 待机时间页面

| 时刻 | 波形 |
|---|---|
| 普通分钟 | 时间与电池固定区域 PARTIAL |
| 每逢 10、20、30、40、50 分 | 整屏 FAST |
| 每逢 00 分 | 整屏 FULL |

`00` 分只执行一次 FULL，不额外叠加 FAST。原有每半小时日程同步仍在 `00/30` 分运行；`30` 分同步结束后只合并执行一次 FAST，取消原来的 FULL。

## 充电页面

- 插入 USB、退出充电页面时执行 FAST。
- 充电百分比跨入新的 5% 档位时执行 FAST，例如 82% 首次刷新到 85%，之后刷新到 90%、95%、100%。
- 83%、84% 等档位内部变化只更新内存，不触发屏幕。
- `充电中 → 已充满` 与紧随其后的 100% 合并为一次 FAST，避免连续闪两次。
- 后台仍每5秒采样一次电池；显示百分比在充电中最快每30秒增长1%，这两个频率都不是屏幕刷新频率。

## 录音页面

录音页保持原策略：计时每5秒局刷，累计5分钟执行一次 FAST。本次没有修改录音刷新节奏。

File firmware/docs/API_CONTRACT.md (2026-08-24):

# 落叶固件 API 契约

适用版本：落叶 `v0.9.1`、ClearMeeting `v0.14.2`。

## 基础契约

- 协议：`luoye-device-api/2`
- 音频：PCM S16LE、16 kHz、单声道、16 bit
- 在线分片：160 KiB
- 离线/补洞逻辑范围：10 MiB，不降级为 2 MiB
- 所有已认证请求由固件网络调度器串行仲裁，录音写 SD 不依赖网络

## 配对与认证

设备通过 `/api/v2/device/pair/start` 和 `/pair/status` 配对。业务请求使用与账号、设备和 `binding_generation` 绑定的设备 token；解绑后旧 token 失效。

## 在线录音

设备创建 `upload_mode=live` 会话后，将实时音频发送到 `/audio/{seq}`。每片携带绝对字节偏移、字节数和 SHA-256。服务器同时返回连续文件游标和当前实时 epoch 游标。

录音中断网时继续写 SD。网络恢复后，固件调用 `/live-resume`，从当前录音位置建立新实时 epoch，立即恢复当前字幕；断网缺口不会阻塞当前声音。

## 手动补洞

存在断网缺口的录音停止后，固件调用 `/defer`，本地进入等待手动同步状态。用户长按中间键进入同步页，单击中间键确认后，固件调用 `upload-plan`，只按服务器返回的缺失范围上传 `/audio-range`。全部范围补齐后调用 `/complete`。

服务器按绝对时间轴把补传转写插回原会议。设备和服务器重启均保留进度，重复范围按偏移、长度和 SHA-256 幂等处理。

## SD 删除

设备管理的 SD 删除与云端会议历史完全独立：

- `delete_sessions` 只删除指定的本地录音目录；
- `delete_all_closed` 只删除本机当前绑定下的全部已闭合录音目录；
- 不调用会议取消接口，不查询上传完成状态，不按保留天数限制；
- 正在写入的录音延迟到安全闭合后执行；
- 删除结果只作为存储命令 ACK 上报，不删除云端会议、字幕、纪要、待办或音频。

旧的 `cleanup_synced`、自动保留天数策略和 SD 删除前云端 `cancel` 路径不属于 v0.8.2。

## 调度优先级

1. 在线录音音频与字幕；
2. 录音安全收尾、MARK、`defer/end/complete`；
3. 用户手动同步；
4. 语音待办；
5. 议程；
6. SD 清单和删除命令。

失败任务仅设置自身的下次重试时间，不用长时间延时占住整个网络任务。

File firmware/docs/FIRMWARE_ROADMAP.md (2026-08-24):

# 落叶（Luoye）录音卡固件路线图

> 目标硬件：ESP32-S3 N16R8、GDEY0213B74、双 PDM 麦克风、microSD、BQ25186、MAX17048、PCF8563
> 正式固件目录：`D:\OPENOP\recorder-card-hw-test\firmware\recorder-card`
> 内部产品标识：`Luoye`；工程名：`recorder_card`
> 文档状态：V1 实施基线（2026-07-30）

## 1. 不可改变的实施原则

1. **SD 优先**：音频先可靠落卡，网络失败绝不能中断本地录音。
2. **录音与上传解耦**：录音生命周期和上传生命周期分别维护状态。
3. **真实状态驱动 UI**：未收到真实成功事件前，不显示“已保存、已同步、已入日历”。
4. **账号密码不进设备**：录音卡只接收 WiFi 凭据；账号在手机/电脑客户端登录并认领设备。
5. **会话可恢复**：断网、重启、重复分片、ACK 丢失均不能造成丢失或重复录音。
6. **安全收尾优先**：SD 故障、低电量和关机必须等待本地会话安全闭合。
7. **一个版本只解决一个主问题**：上一版本未验收，不进入下一版本。
8. **无证据不完成**：没有构建产物、SHA-256、串口日志和真板测试记录，不标记版本完成。
9. **生产链路强制 HTTPS**：禁止证书失败后自动降级 HTTP。
10. **普通烧录不操作 eFuse**：Secure Boot、Flash Encryption 等不可逆操作必须走独立量产审批。

## 2. 版本状态机

```text
PLANNED
  → IN_PROGRESS
  → CODE_COMPLETE
  → BUILD_PASS
  → READY_TO_FLASH
  → FLASHED
  → BOARD_PASS
  → ACCEPTED
```

任何阶段失败都回到 `IN_PROGRESS`。只有 `ACCEPTED` 版本可以作为下一版本的开发基线。

版本命名：

- 开发构建：`v0.2.0-dev.1`
- 候选构建：`v0.2.0-rc.1`
- 验收版本：`v0.2.0`
- 正式发布：`v1.0.0`

## 3. 总体版本路线

| 版本 | 主目标 | 前置依赖 | 完成后的能力 |
|---|---|---|---|
| `v0.1.0-baseline` | 冻结当前可运行基线 | 当前代码和硬件 | 可重复构建、烧录、回滚 |
| `v0.1.1-engineering` | 工程化与可追踪性 | baseline | 版本号、构建信息、结构化日志、测试框架 |
| `v0.2.0-storage-safe` | 可靠录音与安全收尾 | engineering | SD 故障不假录音，断电可恢复 |
| `v0.3.0-provisioning` | SoftAP 配网和账号绑定 | 线上后端源码/API 固化 | 新设备可由普通用户联网并绑定指定账号 |
| `v0.4.0-cloud-sync` | 持久离线补传 | provisioning | 重启、断网、多会话都能可靠上传 |
| `v0.5.0-live-ai-ui` | 字幕、翻译和 HTML V2 页面 | cloud-sync | 真实字幕/译文回屏，客户端可查看活动会话 |
| `v0.6.0-agenda-todo` | 议程、提醒和语音待办 | live-ai-ui | 日程同步、RTC 提醒、待办入日历 |
| `v0.6.1-cloud-v1` | 三端 API v1 收敛 | agenda-todo | 唯一正式协议、账号隔离、可端到端联调 |
| `v0.7.0-power-recovery` | 电源、恢复和长期稳定性 | agenda-todo | 低电量安全关机、RTC 唤醒、看门狗、长稳 |
| `v0.8.0-ota-security` | OTA 与安全加固 | power-recovery | 签名升级、失败回滚、量产安全配置 |
| `v0.9.0-rc` | 发布候选与故障注入 | 所有功能版本 | 功能冻结，完整产品验收 |
| `v1.0.0` | 首个正式发布 | RC 通过 | 可复制生产和交付 |

## 4. 各版本详细目标

### v0.1.0-baseline：冻结当前基线

目标：证明当前源码能够被重新构建、烧录和复现，保留一个确定可回退的起点。

- [ ] 在正式固件目录初始化 Git 仓库。
- [ ] 排除 `build/`、临时文件、密钥和本机配置。
- [ ] 保存当前源码快照。
- [ ] 使用固定 ESP-IDF 版本执行一次干净构建。
- [ ] 运行状态机 PC 回归测试。
- [ ] 在开发板烧录并保存完整启动日志。
- [ ] 验证按键、LED、墨水屏、麦克风、SD、I²C 和 WiFi 基础能力。
- [ ] 保存 bootloader、partition table、app、assets 和 flash 参数。
- [ ] 生成所有产物 SHA-256。
- [ ] 标记 `fw-v0.1.0-baseline`。

验收限制：

- 该版本只作为开发回退点。
- 不声明配网、账号绑定、可靠补传、字幕、翻译、待办或 OTA 已完成。

### v0.1.1-engineering：工程化与可追踪性

目标：以后每一次烧录都能回答“烧了什么、由什么源码构建、为什么失败”。

- [ ] CMake 注入 `PROJECT_VER`、Git commit、构建时间和硬件版本。
- [ ] 开机串口打印固件版本、commit、IDF 版本、硬件版本、reset reason。
- [ ] 增加统一错误码和子系统状态快照。
- [ ] 事件投递失败必须计数并报警，不允许静默丢失关键事件。
- [ ] 建立 `release/` 打包脚本和 manifest 格式。
- [ ] 固化开发、RC、Release 三套构建配置。
- [ ] 建立接口契约、会话 manifest 和测试向量文档。
- [ ] 固件 release manifest 记录兼容的 API contract、服务器 release 和最低客户端版本。
- [ ] 保证现有按键、屏幕和录音行为无回归。

真板验收：

- 连续重启 20 次版本信息一致。
- 串口日志可定位每个子系统初始化结果。
- 任意构建产物都能追溯到唯一源码提交。

### v0.2.0-storage-safe：可靠录音与安全收尾

目标：在没有网络的情况下，先把录音卡做好成一台可靠录音机。

- [ ] 使用随机 UUID 或设备 UUID + 持久计数生成会话 ID。
- [ ] 创建 `session.json`、`audio.wav`、`marks.jsonl`、`upload.state`。
- [ ] 增加 `STARTING`、`CLOSING`、`STORAGE_ERROR` 等真实状态。
- [ ] 检查所有 `fwrite`、`fflush`、`fsync`、`fclose` 返回值。
- [ ] 短写、卡满、拔卡和文件系统错误立即停止“假录音”。
- [ ] 收到 `SESSION_CLOSE_DONE` 后才能显示“本地已保存”。
- [ ] 会话未闭合时禁止新开录音和进入深睡。
- [ ] 启动扫描未闭合会话，根据真实文件长度修复 WAV 头。
- [ ] 修复 `marks.jsonl` 尾部不完整记录。
- [ ] 记录音频缓冲溢出和丢帧数量。
- [ ] 低电量进入 `CRITICAL_FLUSH`，主动停麦、排空和落盘。
- [ ] 增加“无 SD、SD 满、写失败、MIC 失败、电量不足”页面。

真板验收：

- 录音任意时刻拔卡不会继续显示正常录音。
- 写满 SD 后已有 WAV 保持可播放。
- 录音过程中复位，重启后 WAV 可修复并保留。
- writer 最坏积压下关机仍等待闭合。
- 连续录制 2 小时无丢帧、无文件损坏。

### v0.3.0-provisioning：SoftAP 配网和账号绑定

前置 Gate：必须同步线上正在运行的后端源码，并冻结设备 API 请求/响应结构。

- [ ] 服务器提供只读 `/api/build-info`，能返回 release、commit、镜像、API contract 和数据库 migration。
- [ ] 使用不可碰撞的制造期 `device_uuid`；dev.1 暂以完整 eFuse MAC 作为稳定工程 ID。
- [x] BACK 长按 3 秒启动带随机密码的 SoftAP。
- [x] 本地配置页只接收 WiFi，不接收账号密码或服务器地址。
- [x] 候选 WiFi 获得 IP 后才提交 NVS。
- [ ] 连接固定 HTTPS 生产服务器并验证证书。
- [x] 固件已实现一次性 code/nonce 请求与墨水屏配对码状态；待服务器实现。
- [ ] 客户端登录后选择账号并 Claim 设备。
- [x] 固件已实现轮询和 Device Token/脱敏账号 NVS 保存；待服务器联调。
- [x] 墨水屏已实现 WiFi、服务器、配对中、成功和错误状态。
- [ ] 支持解绑、重新配对和恢复出厂设置。
- [ ] 401/403 不影响本地录音，只暂停上传并提示重新绑定。

真板验收：

- 全新擦除 NVS 后，普通用户可独立完成联网和绑定。
- 账号 A 绑定后可看到设备；账号 B 不可见。
- 解绑后旧 Token 立即失效。
- 重配对不会把旧账号的积压录音上传给新账号。

### v0.4.0-cloud-sync：持久离线补传

- [x] 上传任务扫描所有未完成会话，而不是只处理当前会话。
- [x] 持久化 `remote_session_created`、`next_seq`、`acked_offset` 和 `final_acked`。
- [x] 分片携带 `device_uuid`、`session_uuid`、`seq`、`offset`、长度和 SHA-256。
- [ ] 服务端按 `(device_uuid, session_uuid, seq)` 幂等接收。
- [x] 设备端在 ACK 丢失后用同一幂等键原样重传；待服务端验证不会重复拼接。
- [x] Session create 和 finalize 均为独立、可重复请求。
- [x] 上传 `marks.jsonl` 中的重点、收藏和待办标记。
- [x] HTTP 状态按 401/403/409/413/429/5xx 分类处理。
- [x] 重连使用指数退避和随机抖动。
- [x] API/TLS 状态与 WiFi 获得 IP 状态分离。
- [x] 只有持久化 `final_acked=true` 后才标记会话上传完成。
- [x] 本版本上传后保留固定式 SD 本地录音，不自动删除。

真板验收：

- 离线录音 30 分钟，重启后联网，最终完整上传。
- 旧会话未传完时开始新会话，两场都能完成。
- 每个 chunk 和 final 在“服务已收但 ACK 丢失”窗口复位，服务端最终只有一份数据。
- 恰好整 160 KiB 边界的录音仍能可靠 finalize。

### v0.5.0-live-ai-ui：字幕、翻译和 HTML V2

- [ ] 服务器响应带 `revision`、连续接收偏移和最新结果；设备端 0.4-draft 解析器已完成。
- [x] 会议场景解析最终/临时字幕并缓存。
- [x] 翻译场景支持同一 revision 的原文、译文和双语页面。
- [x] 墨水屏正文约每 15 秒刷新一次，重要状态立即刷新。
- [x] 会议两页、翻译三页与 HTML V2 对齐。
- [x] 完成充电页、议程占位页、设备状态页、配网页、收尾页和错误页。
- [x] 锁键、提醒、待办覆盖层不破坏活动录音。
- [x] 录音中提醒按 REC 只关闭提醒，不重启会话。
- [ ] 客户端“活动会话”能够加入录音卡会话旁听，不再使用电脑麦克风替代。
- [x] UI 文案只表达真实后端状态；无日程、无云结果时明确显示等待或不可用。

真板验收：

- 在线会议字幕可回屏并在客户端同步出现。
- 翻译页的原文和译文来自同一 segment/revision。
- 断网时显示本地录音和积压，恢复后继续更新。
- 墨水屏连续刷新 4 小时无错位、镜像和严重残影。

### v0.6.0-agenda-todo：议程、提醒和语音待办

- [x] SNTP 校时并反向校准 PCF8563。
- [x] 统一使用 UTC 存储，按账号时区显示。
- [x] 同步今日议程和 revision 到本地原子缓存。
- [x] 调度最近一条 PCF8563 闹钟，处理后调度下一条。
- [x] 提醒支持 REC 开始会议、MARK 延后 10 分钟、BACK 关闭。
- [x] 收尾/待办采集期间的提醒进入待处理队列，不允许丢失。
- [x] MARK 按住期间独立截取最长 30 秒待办语音。
- [x] 离线先保存，在线幂等上传并轮询 ASR/时间解析结果（设备端）。
- [x] 收到服务器创建/确认 ACK 后才显示“已创建”。
- [x] 明确本地保存、等待确认、创建成功和永久失败交互。
- [x] 固件与服务器统一实现 `luoye-device-api/1`。
- [ ] 完成配对、断网补传、字幕/翻译、议程与待办的真板端到端联调。

真板验收：

- 离线仍能显示已缓存议程并触发本地提醒。
- “明晚七点学生会”可创建正确时区的待办。
- 延后 10 分钟后 RTC 在正确时间再次提醒。
- 录音中提醒不会重置当前会话。

### v0.7.0-power-recovery：电源、恢复和长期稳定

- [ ] 验证新 PCB 的 `RTC_INT` 已接到可深睡唤醒的 RTC-IO，并同步 `board_pins.h`。
- [ ] 实现 `NORMAL → LOW_WARNING → CRITICAL_FLUSH → SAFE_OFF`。
- [ ] 充电、满电、USB 拔插具有去抖和滞回。
- [ ] 关键任务加入 watchdog/supervisor。
- [ ] 保存 boot count、clean shutdown、reset reason 和最小崩溃记录。
- [ ] 网络上传不能阻塞状态机和按键事件。
- [ ] 关键事件采用不可静默丢失的投递策略。
- [ ] 完成长时间录音的 `hh:mm:ss`、文件分段和容量管理。
- [ ] 完成高通、AGC、限幅和可选降噪的音质验收。

真板验收：

- 电池临界条件下仍有足够能量完成最坏积压的 close + fsync。
- 深睡后按键和 RTC 均能按规格唤醒。
- 连续运行 72 小时无死锁、无内存持续下降。
- WiFi、服务器和 SD 故障交替出现时仍可恢复。

### v0.8.0-ota-security：OTA 与安全加固

- [ ] 重规划 `otadata + ota_0 + ota_1` 分区。
- [ ] assets 与固件版本兼容，必要时实现 A/B 或校验回滚。
- [ ] HTTPS 下载并验证版本、硬件、哈希和签名。
- [ ] 录音中、CLOSING、低电量和未安全持久化时禁止安装重启。
- [ ] 新固件以 TRIAL 启动，通过本地健康门后才标记有效。
- [ ] 失败自动回滚，NVS/manifest schema 迁移保持向后兼容。
- [ ] 启用加密 NVS。
- [ ] 准备 Secure Boot V2、Flash Encryption Release 和调试口量产策略。
- [ ] 建立密钥生成、保管、轮换和报废流程。
- [ ] 将当前开发字体替换为授权允许量产分发的字体，并完成许可证清单。

安全警告：

- 开发和普通真板测试阶段不得烧录不可逆安全 eFuse。
- 只有经过书面审批的 RC 板才执行量产安全配置演练。

### v0.9.0-rc：发布候选

- [ ] 功能冻结，不再加入新功能。
- [ ] 完成断网、拔卡、卡满、低电量、复位、服务器错误和 OTA 断电故障注入。
- [ ] 两个账号互相不可查看、修改或删除对方会议。
- [ ] 解绑后的旧 Token 和旧设备会话访问立即失效。
- [ ] 完成录音保留、删除、导出和隐私策略验收。
- [ ] 至少 5 台设备执行相同测试矩阵。
- [ ] 完成 72 小时长稳和多会话压力测试。
- [ ] 所有 P0/P1 缺陷清零。

### v1.0.0：正式发布

- [ ] 从干净环境可重复构建。
- [ ] 固件、bootloader、partition、assets 全部签名并生成 SHA-256。
- [ ] 完成版本说明、烧录说明、回滚说明和工厂测试说明。
- [ ] 完成服务器 API/数据库迁移备份。
- [ ] 完成最终 RC 到 Release 的差异审计。
- [ ] 经批准后执行量产安全配置。
- [ ] 标记 `fw-v1.0.0`，归档完整 release 包。

## 5. 版本依赖 Gate

### G0：源码与构建可追踪

未完成 Git 基线、版本注入和可重复构建前，不开始功能修改。

### G1：线上服务器源码同步

线上部署已比本地 `server/` 源码更新。未拿到线上准确源码、数据库 schema 和设备 API 契约前，不开始 `v0.3.0`。

线上事实必须注明证据等级：`线上探测确认 / 线上端到端确认 / 部署源码确认 / 本地旧源码参考 / 待确认`。仅看到路由存在，不等于接口契约或账号隔离已经通过。

### G2：存储安全

未通过 `v0.2.0` 的拔卡、卡满、断电和安全闭合测试前，不允许把“已保存”作为产品文案。

### G3：账号隔离

未通过账号 A/B 隔离、解绑和 Token 吊销测试前，不允许设备上传真实用户录音。

### G4：不可逆安全操作

Secure Boot、Flash Encryption Release、JTAG/下载口限制等 eFuse 操作必须等 `v0.9.0-rc` 通过并单独审批。

## 6. 每版统一完成定义

一个版本只有同时满足以下条件才可标记 `ACCEPTED`：

- [ ] 版本范围内所有清单完成。
- [ ] 单元测试、状态机测试和版本专项测试全部通过。
- [ ] 固定 ESP-IDF 环境下执行干净构建通过。
- [ ] 无新增编译警告；已有警告有明确记录。
- [ ] 产物大小、SHA-256、commit 和 sdkconfig 已归档。
- [ ] 使用候选版本烧录开发板并保存完整串口日志。
- [ ] 真板冒烟测试和版本专项验收通过。
- [ ] 失败场景不会显示虚假成功状态。
- [ ] 上一个 accepted 版本仍可回滚。
- [ ] `FIRMWARE_PROGRESS_LOG.md` 和发布记录已更新。
- [ ] Git commit/tag 与归档产物一一对应。

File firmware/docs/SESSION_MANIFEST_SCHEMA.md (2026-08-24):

# 落叶录音会话 Manifest 规范

Schema：`luoye-session/1-draft`
状态：设备端由 `v0.6.1-cloud-v1` 继续读写；API v1 端到端联调待验收。

每个录音目录必须独立拥有 `session.json`。它是录音恢复、后台补传和账号归属的本地
真源，不能只把状态保存在 RAM。

## 1. 示例

```json
{
  "schema": "luoye-session/1",
  "client_session_id": "LY-20260730-210000-a1b2c3d4",
  "server_session_id": null,
  "device_id": "pending-device-id",
  "binding_generation": 1,
  "scene": "meeting",
  "title": null,
  "started_at_utc": null,
  "ended_at_utc": null,
  "source_language": "zh-CN",
  "target_language": null,
  "audio": {
    "path": "audio.wav",
    "codec": "pcm_s16le",
    "sample_rate": 16000,
    "channels": 1,
    "pcm_bytes_committed": 0,
    "wav_closed": false,
    "sha256": null
  },
  "upload": {
    "state": "queued",
    "remote_session_created": false,
    "next_seq": 0,
    "acknowledged_bytes": 0,
    "final_ack": false,
    "marks_acked": false,
    "retry_count": 0,
    "last_http_status": 0,
    "result_revision": 0,
    "result_pcm_bytes": 0,
    "last_error": null
  },
  "marks": {
    "path": "marks.jsonl",
    "count": 0,
    "uploaded_count": 0
  },
  "recovery": {
    "close_reason": null,
    "repair_count": 0,
    "last_repaired_at": null
  }
}
```

## 2. 状态

`upload.state` 是上传进度的原子真源，`session.json.upload` 是同内容的可读镜像。
`v0.5.0` 写入 `luoye-upload/2`，在 v1 字段基础上增加 `result_revision` 和
`result_pcm_bytes`；缺失字段按 0 迁移。
状态只能按下列方向迁移：

```text
recording
  → closing
  → local_closed
  → queued
  → uploading
  → awaiting_final
  → final_acked
  → local_deleted
```

故障可以进入 `local_error`、`upload_retry` 或 `auth_blocked`，但不得删除本地会话。
不可重试的协议错误可进入 `permanent_error`，需由兼容固件或人工迁移后恢复。

## 3. 原子更新

更新 `session.json` 必须：

1. 写入同目录的 `session.json.tmp`。
2. `fflush`。
3. `fsync`。
4. 校验完整 JSON 和 schema。
5. 原子替换正式文件。
6. 目录项同步能力受 FATFS 限制时，保留上一代 `session.json.bak`。

启动恢复顺序：

1. 扫描所有会话目录。
2. 优先读取有效 `session.json`，无效时尝试 `.bak`。
3. 对未闭合 WAV 根据实际文件长度修复 WAV 头。
4. `acknowledged_bytes` 不得超过实际 PCM 长度。
5. 所有未完成会话重新进入队列，不只恢复最近一次会话。

## 4. ID 与幂等

- `client_session_id` 在设备本地永久唯一；RTC 无效时也不能复用。
- 会话创建幂等键：`session:{client_session_id}:create`。
- 分片幂等键：`session:{client_session_id}:audio:{seq}:{sha256}`。
- 标记幂等键：`session:{client_session_id}:mark:{client_mark_id}`。
- final 幂等键：`session:{client_session_id}:end`。
- 换绑后旧会话保留创建时的 `binding_generation`，不得自动转移到新账号。

## 5. 兼容与迁移

- 未识别的高版本 schema 不得被低版本固件改写。
- 新增字段默认向后兼容，删除或改语义必须提升 schema 主版本。
- release manifest 必须记录可读写的 session schema 范围。
- 当前录音在线时实时上传；已闭合历史会话只在用户从中间键确认同步后按最早优先上传。
- 云端 final ACK 持久化后立即删除该本地会话；若在删除中断电，`delete.safe` 标记用于重试原子收尾。
- 当前绑定账号可随时从网页请求删除本地会话，不以 `final_acked` 为前置条件；正在写入时命令保持 pending，安全闭合后自动执行。
- 活动录音期间 `upload.state` 可以更新；`session.json` 仍由录音 writer 管理，避免
  两个任务同时 rename manifest。会话闭合后再镜像上传状态。

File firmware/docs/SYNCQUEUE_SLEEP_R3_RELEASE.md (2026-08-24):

# 落叶 v0.7.0 UI154 syncqueue-sleep-r3 工程版

日期：2026-08-06

状态：`BUILD_PASS / READY_TO_FLASH`，尚待真板验收。

## 本版内容

- 网页设备存储新增“清空本地历史录音”。命令不受 30 天保留策略限制；正在写入的录音会等 WAV 安全关闭后再删除。
- 录音卡空闲 60 秒后停止 Wi-Fi，并进入 light sleep。
- light sleep 每到下一分钟唤醒一次，只读取 PCF8563、用黑白 FAST 更新主页时间，然后继续休眠；定时更新不恢复 Wi-Fi。
- REC、中间键（MARK）、BACK，以及 PCF8563 的 RTC_INT 均可唤醒；按键唤醒后恢复 Wi-Fi。
- SSD1681 编译路径只保留 1-bit 黑白全刷、1-bit 黑白 FAST 与 BUSY 等待；不包含四灰刷新函数、四灰帧缓冲或旧局刷枚举。
- uploader 任务栈保持 32 KiB，避免大批量 SD 清单和命令处理期间的栈溢出。

## 自动验证

- ESP-IDF v5.5.4-3 完整构建通过。
- 应用镜像：`1,240,448` 字节（`0x12ed80`），6 MiB factory 分区剩余约 80%。
- 服务端：`78 passed`。
- Web：`5 passed`，Vite 生产构建通过。
- 固件静态检查：manual sync/FIFO/delete、UI154、idle/light-sleep/bulk-delete/monochrome EPD 全部通过。

## 发布物

- 固件：`releases/luoye-fw-v0.7.0-ui154-r2.11-syncqueue-sleep-r3-flash.zip`
- 固件 SHA-256：`6ca3a4b2384bffbf495483b6ed6f4271927769b60fcb6f2f1528f2df7cb80606`
- 配套服务端：`clearmeeting-server-v0.13.0-syncqueue-r2.zip`
- 服务端 SHA-256：`f9fe372e12d6c25526355e992c5d863d96089b47c9ae12832e58a9f9162adba3`

## 真板待验

1. 待机 60 秒后出现 `LY|IDLE|state=enter`，路由器侧设备断开 Wi-Fi。
2. 每分钟出现 `LY|IDLE|state=minute_update`，屏幕时间 FAST 更新且 Wi-Fi 仍关闭。
3. REC、中间键、BACK 分别能唤醒，随后出现 `LY|IDLE_NET|state=resumed` 并重新联网。
4. 网页“清空本地历史录音”能删除所有已关闭本地会话；录音中的会话停止后自动执行。
5. 黑白 FAST 显示、全刷初始化和 BUSY 超时处理正常，无四灰显示路径。

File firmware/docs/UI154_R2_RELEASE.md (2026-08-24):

# 落叶 v0.7.0 UI154-r2 工程版

## 基线

- 面板：GDEY0154D67 / SSD1681 / 200×200 / 1-bit
- 业务基线：落叶 v0.7.0 轻量双麦录音、断网补传、议程待办与自适应充电
- UI 布局：`luoye-ui-layout/v3`
- 页面：22
- 动态文字字段：130
- 固定图标位置：20
- 布局 SHA-256：`8a48be441477e57a69809ec35fb88f2eb9c4c2212364cd2a6533bfc4687828ac`

## 本版变更

1. 22 张静态资源只保留叶片、曲线、状态图形等画面元素。
2. 固定图标按最终 JSON 的坐标和尺寸合入页面资源。
3. 所有文字由 `font16.bin` 在运行时绘制；时间、电量、日程、字幕、录音状态、配网和绑定信息可实时变化。
4. 文字坐标、字号、行高、最大行数和对齐方式由生成的 `ui154_layout_generated.c` 统一管理。
5. 录音字幕仍以 8 秒为周期使用 SSD1681 FAST 刷新；待机主页按分钟刷新。
6. 中间键长按进入同步确认页，短按中间键开始上传，BACK 取消；历史录音按最早优先顺序同步。
7. 云端完整确认后自动清除对应本地录音；网页可删除任意已结束的本地录音，不再要求先上传完成。

## 构建

```bat
cd /d D:\OPENOP\recorder-card-hw-test\firmware\recorder-card-v070-100ma
idf.py -B build-154-ui build
```

烧录包使用 `flash_COM22.bat`，或者执行包内 README 给出的 esptool 命令。

## r2.1 EPD 修复

`r2-final` 在连续刷新时错误地相信 SSD1681 深度睡眠后的旧帧 RAM 仍然有效，可能把未初始化的旧帧参与差分快刷，表现为整屏随机噪点。`r2.1-epdfix` 在 ESP32 内存中保存上一帧，并在每次唤醒后同时重载旧帧 RAM2 和当前帧 RAM1；BUSY 超时也会终止快刷基线。请使用 `r2.1-epdfix`，不要继续使用 `r2-final`。

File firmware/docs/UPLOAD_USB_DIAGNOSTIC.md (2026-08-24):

# USB 离线上传诊断

本诊断只增加串口计时，不改变服务器地址、10 MiB 范围大小、重试策略或 TCP 配置。
日志不会写入 SD，也不会输出设备令牌、音频内容或 SHA 摘要。

## 测试准备

1. 使用 USB 数据线连接工程调试板。
2. 断网录制 6–8 分钟，确保产生至少一个完整 10 MiB 离线范围。
3. 恢复 Wi-Fi，进入手动同步。
4. 串口过滤 `LY|UPLOAD_DIAG`，至少保存一个 `range_begin` 到
   `range_done` 的完整序列。

## 日志字段

- `range_begin`：上传路由、RSSI、范围偏移、字节数和工作缓冲大小。
- `range_hash`：第一次 SD 读取与 SHA-256 阶段；`sd_read_ms` 是 `fread`
  累计时间，`sha_ms` 是 mbedTLS SHA 累计时间，`other_ms` 包含打开、定位和关闭文件；
  `sd_Bps` 与 `sha_Bps` 分别给出两个阶段的吞吐。
- `range_http`：第二次 SD 读取和 HTTP 流式发送；`connect_ms` 是连接及请求头阶段，
  `write_ms` 是 `esp_http_client_write` 累计阻塞时间，`response_ms` 是等待服务器响应时间。
- `effective_Bps`：从准备 HTTP 到收到响应的端到端速度。
- `write_Bps`：仅按 HTTP 写调用累计时间计算的发送速度。
- `read` 和 `sent`：发生错误时可确认失败前实际从 SD 读取和写入 TCP 的字节数。
- `range_done`：服务器确认并持久化本地上传游标后的总耗时。

计时使用 `esp_timer_get_time()`。循环内计时调用的开销远低于一次 SD 或 TCP 操作，
但诊断包仍只用于工程定位，不作为量产性能结论。

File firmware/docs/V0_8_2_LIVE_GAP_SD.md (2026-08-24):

# 落叶 v0.8.2 实时断网恢复与独立 SD 删除

配套服务器：ClearMeeting v0.14.2；设备协议：`luoye-device-api/2`。

## 录音网络规则

- 在线时：按 160 KiB 分片上传，服务器实时转写。
- 录音中断网：麦克风和 SD 录音不停止，断网起点持久化到 `upload.state`。
- 录音中恢复网络：从当前录音位置建立新的实时 epoch，立即上传现在说的话；不在实时通道追赶旧缺口。
- 停止时仍有缺口：本地文件进入“等待手动同步”，不会自动在后台长期占用网络。
- 用户长按中间键进入同步页，单击中间键确认后，按服务器返回的缺失范围用 10 MiB 逻辑块补传。
- 服务器完整确认后，本地文件才进入已完成清理流程。

## 固定式 SD 删除规则

- 网页单项删除和一键删除全部只操作 SD 本地录音文件。
- 不调用服务器会议取消接口，不删除、不修改云端会议历史。
- 不要求录音达到指定天数，也不检查是否已经上传。
- 当前正在写入的录音不会被直接破坏，命令在安全收尾后执行。

## 验收日志

串口重点观察：

- `LY|UPLOAD|event=live_gap`
- `LY|UPLOAD|event=live_resume`
- `LY|UPLOAD|event=defer`
- `LY|SYNC|...`
- `LY|STORAGE_CMD|...`

验收时必须确认：恢复网络后的新字幕先出现；断网内容仅在手动同步后补入；删除 SD 后云端历史仍可打开。

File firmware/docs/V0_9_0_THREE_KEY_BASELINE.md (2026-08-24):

# 落叶 v0.9.0 三功能键交互基线

配套服务器：ClearMeeting v0.14.2；设备协议：`luoye-device-api/2`。

## 三键定义

| 状态 | 录音键 | 待办键 | 设置键 |
|---|---|---|---|
| 待机 | 单击开始录音；长按进入同步确认 | 单击进入/翻阅日程；长按开始待办、松开保存 | 单击进入设备状态；长按配网 |
| 录音 | 单击暂停/继续；长按安全结束 | 单击写入重点 MARK；长按无操作 | 单击切换字幕/状态；长按锁定 |
| 锁定 | 无操作 | 无操作 | 长按解锁 |
| 待办确认 | 无操作 | 单击确认 | 单击取消 |
| 同步确认 | 无操作 | 单击开始上传 | 单击取消 |
| 日程 | 单击开始录音；长按进入同步确认 | 单击下一页 | 单击返回主页；长按配网 |

提醒页、配网页、错误页和保存页具有更高的上下文优先级，不执行待机态全局动作。

## 日程分页

- 每页两条；每条第一行显示时间，下面最多两行显示内容。
- 页数为 `ceil(可见待办数 / 2)`，页码显示 `当前页/总页数`。
- 主页单击待办键进入第 1 页；继续单击循环到下一页，末页后回第 1 页。
- 任意日程页单击设置键立即返回主页。
- 日程 revision 更新时重置到第 1 页；没有数据时显示空状态 `1/1`。

## 输入安全规则

- 短按只在松手且未达到长按阈值时产生，因此长按不会先误触短按。
- 待办录音的 RELEASE 事件由 MARK/待办键产生，REC 不再负责待办松手收尾。
- 待办录入、待办确认、同步、配网、录音收尾等覆盖页会屏蔽不适用的按键动作。
- 录音中的 MARK、字幕/状态切换、锁定/解锁仍然保留。

## UI 来源

- 现有 21 页沿用已验证布局。
- `02_agenda` 单独取自用户确认的 `luoye_ui_layout_22pages_with_icons.json`。
- 合并后的可复现布局：`docs/luoye_ui_layout_v090.json`。
- 布局 SHA-256 记录在 `assets/ui154/manifest.json`。

## 验收重点

1. 待机短按录音键不会进入同步；长按录音键不会开始录音。
2. 长按待办键开始采音，松手后结束并进入云端解析/确认流程。
3. 待办确认页单击待办键确认、设置键取消。
4. 三条以上日程不会重复，页码和每页两条保持一致。
5. 日程页连续按待办键循环翻页，设置键一次返回主页。
6. 录音中待办键仍能写入重点 MARK，设置键仍能切页和锁定。

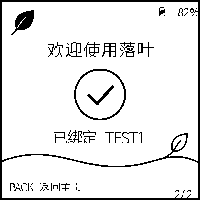
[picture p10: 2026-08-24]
firmware/docs/ui154_firmware_r2_pages/19_bind_ok.png

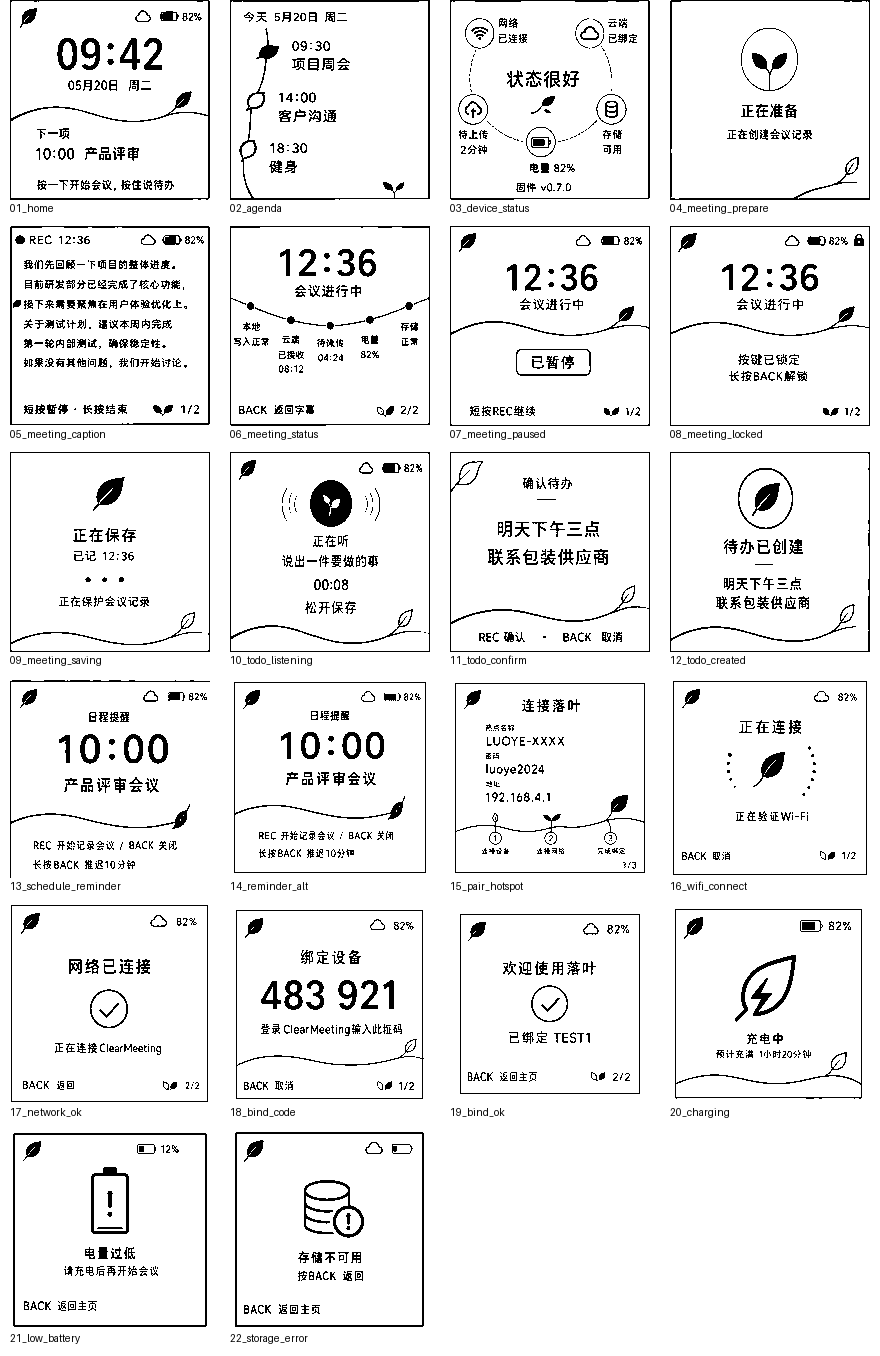
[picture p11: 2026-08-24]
firmware/docs/UI154_THRESHOLD_144.png

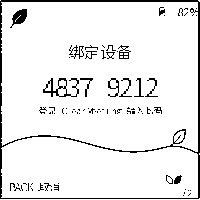
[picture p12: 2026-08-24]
firmware/docs/ui154_firmware_r2_pages/18_bind_code.png

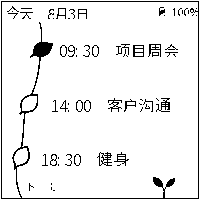
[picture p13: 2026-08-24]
firmware/docs/ui154_firmware_r2_pages/02_agenda.png

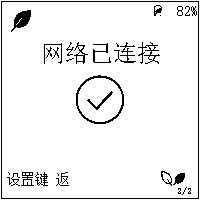
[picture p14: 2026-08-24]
firmware/docs/ui154_native_font_pages/17_network_ok.png

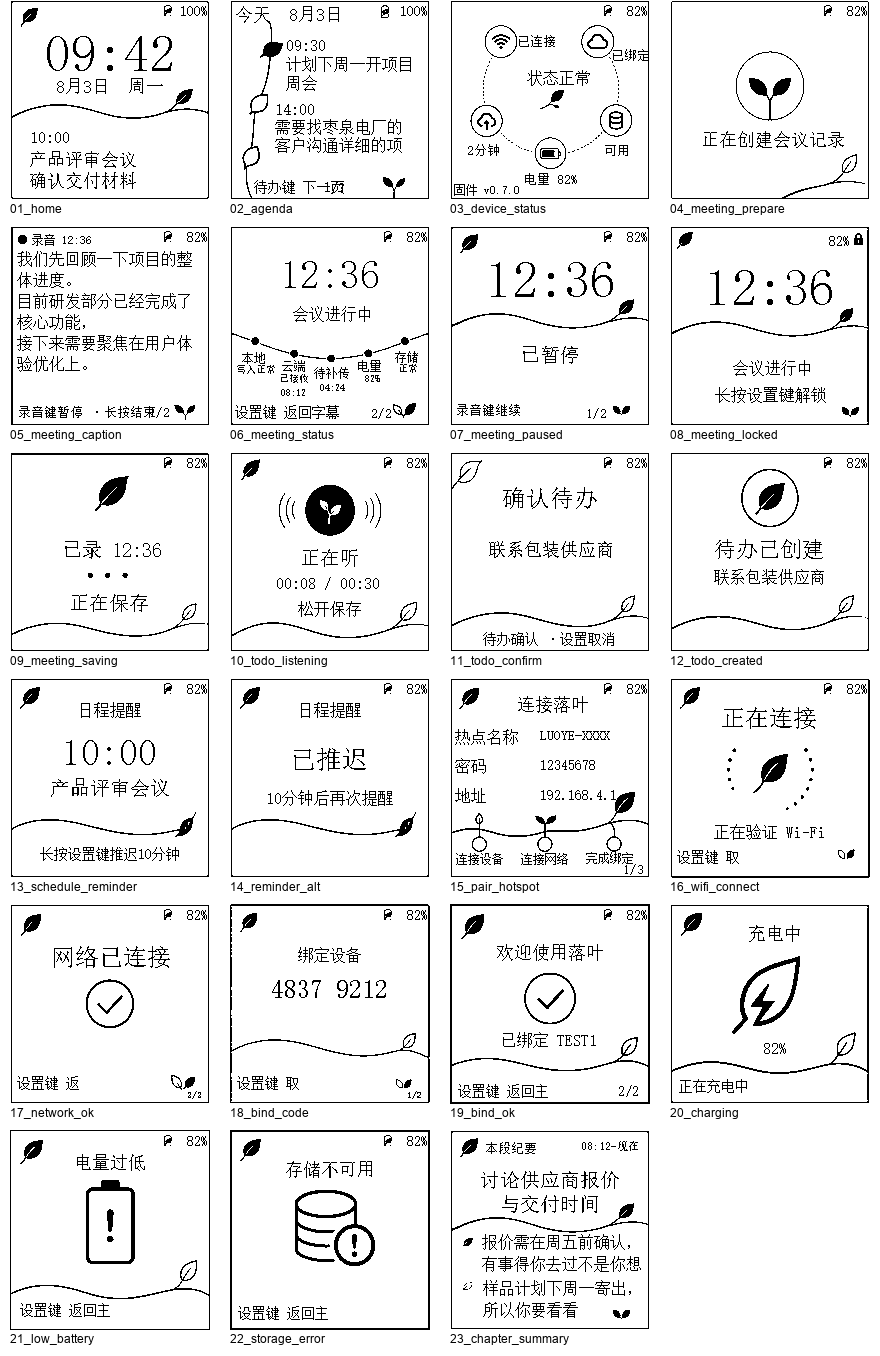
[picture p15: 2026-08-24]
firmware/docs/UI154_FIRMWARE_23PAGES_PREVIEW.png

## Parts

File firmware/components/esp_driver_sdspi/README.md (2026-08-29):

# Project-local SDSPI host driver

This is the ESP-IDF 5.5.4 SDSPI component pinned inside the Luoye firmware.
Its read protocol remains upstream-compatible: intermediate block reads use
up to 516 exact wire bytes and the final block uses no more than 514 bytes.

The component reserves one 516-byte, four-byte-aligned internal DMA buffer at
device initialization and uses it for payload, token, busy, CRC, and stop
transactions. Command objects use separately serialized internal DMA storage.
All SPI transactions are marked with
`SPI_TRANS_DMA_BUFFER_ALIGN_MANUAL`. The paired project-local
`esp_driver_spi` component accepts exact non-word-sized lengths for aligned
internal ESP32-S3 DMA memory, so no upload-time private bounce allocation or
extra SD clock bytes are needed.

Do not round `spi_transaction_t.length` here. Descriptor capacity and wire
length are intentionally different concerns.

# Upstream overview

SD Host side related components are:
- `sdmmc`
- `esp_driver_sdmmc`
- `esp_driver_sdspi` (current component)

For relationship and dependency among these components, see [SD Host Side Related Component Architecture](../sdmmc/README.md).

`esp_driver_sdspi` components is a driver based on ESP GPSPI master driver to help you:
- do SD transactions (under SDSPI mode) via ESP GPSPI peripheral.
- tune ESP GPSPI hardware configurations, such as clock frequency, bus width, etc.
- ...

You can
- use this driver to implement `sdmmc` protocol interfaces
- directly use `esp_driver_sdspi` APIs

to communicate with SD slave devices under SDSPI mode.

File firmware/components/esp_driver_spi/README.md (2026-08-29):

# Project-local ESP-IDF 5.5.4 SPI driver

This component is a source-pinned copy of ESP-IDF 5.5.4 `esp_driver_spi` for
the ESP32-S3 firmware build. It contains two narrowly scoped fixes:

- `LUOYE_SPI_EXACT_LENGTH_DMA_BACKPORT`: backports Espressif's later
  `release/v5.5` DMA-alignment rule. An aligned internal DMA buffer may carry
  an exact non-word-sized transaction without allocating a private buffer.
- `LUOYE_V230_SPI_OOM_GUARD`: preserves valid local pointers on a private DMA
  allocation error before the common cleanup path runs.

The SDSPI caller still uses `SPI_TRANS_DMA_BUFFER_ALIGN_MANUAL`, so an invalid
address fails closed. DMA descriptor capacity may be word-aligned, but the HAL
wire bit length remains the exact `spi_transaction_t.length` value.

The build is frozen to ESP-IDF 5.5.4 and ESP32-S3. When either changes, compare
this whole component with the new upstream implementation before carrying the
backport forward.

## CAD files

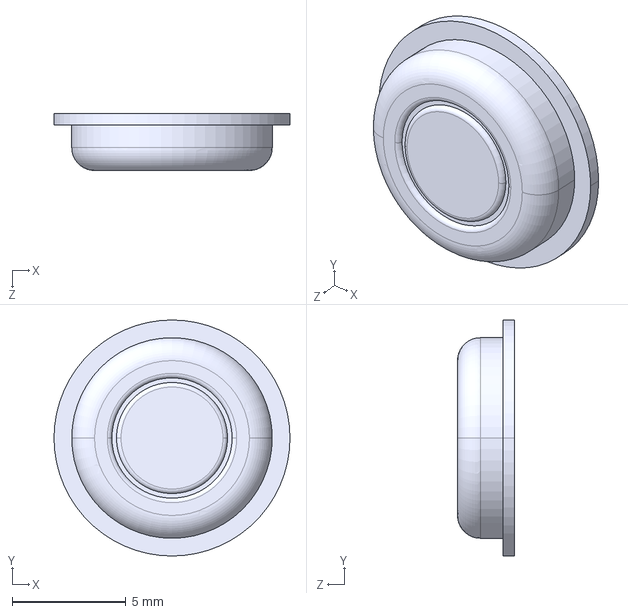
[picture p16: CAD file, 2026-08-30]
hardware/mechanical/luoye-button-round-v2.step
10.4 x 10.4 x 2.50 mm

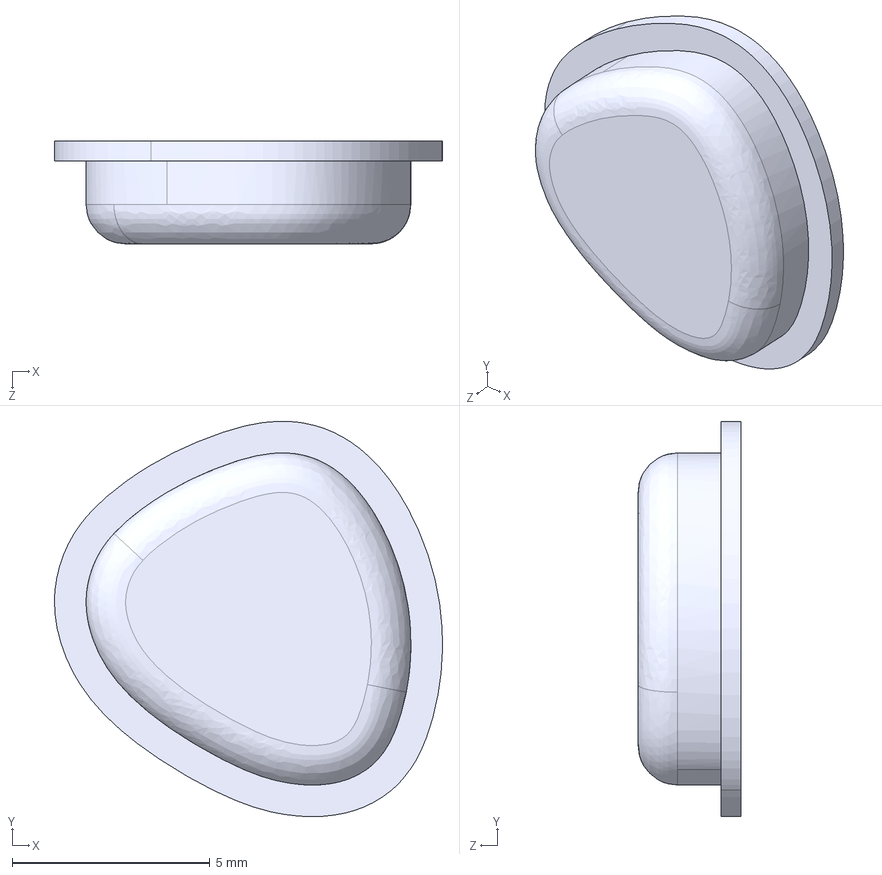
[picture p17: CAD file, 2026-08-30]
hardware/mechanical/luoye-button-leaf-v2.step
9.82 x 10.0 x 2.60 mm

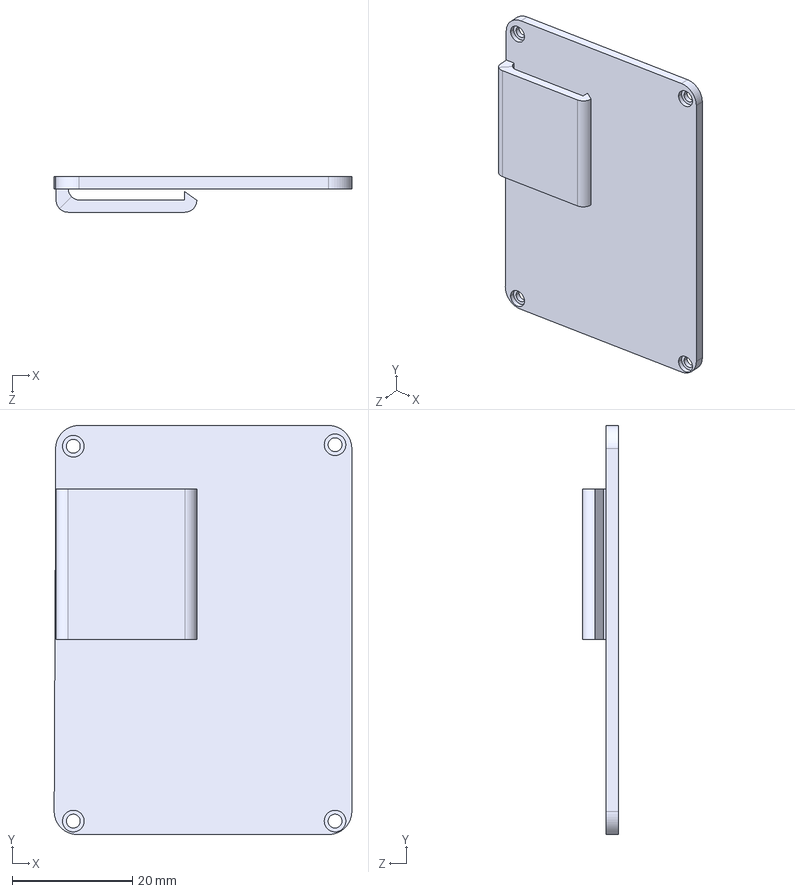
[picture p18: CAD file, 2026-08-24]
hardware/mechanical/luoye-enclosure-bottom-v2.step
49.5 x 68.1 x 5.91 mm

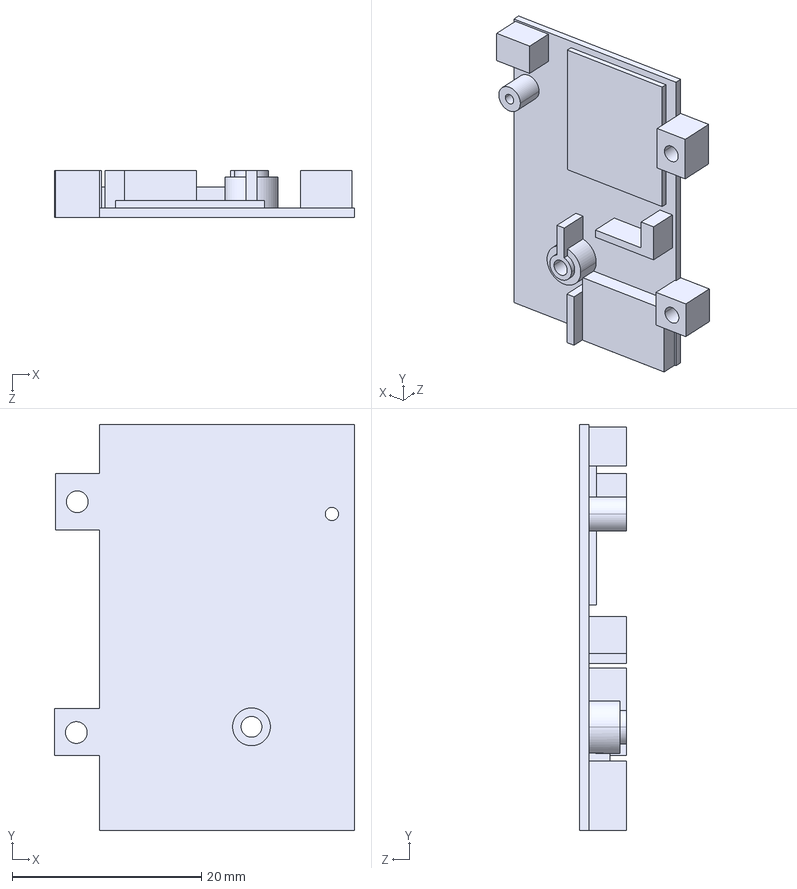
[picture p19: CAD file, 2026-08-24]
hardware/mechanical/luoye-enclosure-inner-v2.step
31.7 x 43.0 x 5.00 mm

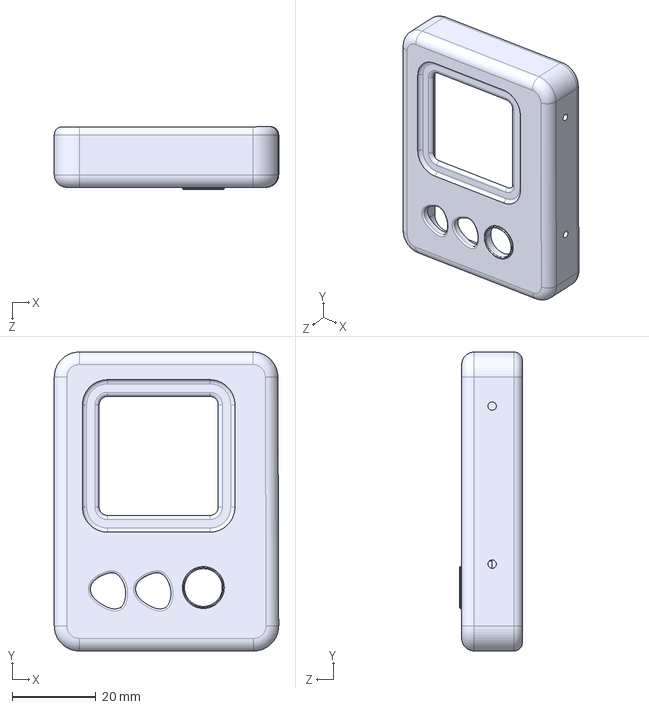
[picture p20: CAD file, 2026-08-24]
hardware/mechanical/luoye-enclosure-outer-v2.step
53.6 x 71.4 x 15.0 mm

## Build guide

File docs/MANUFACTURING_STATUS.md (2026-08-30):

# 硬件制造归档状态

当前资料可用于工程协作、样机展示和设计回溯，但不是完整量产制造包。ECAD、原理图 PDF 与机械 STEP 的日期和技术基线并不一致。

## 当前文件基线

| 类别 | 文件 | 日期/状态 |
| --- | --- | --- |
| 主板 ECAD | `hardware/pcb/luoye-mainboard-2026-08-30.epro` | 2026-08-30，当前工程源 |
| 双麦板 ECAD | `hardware/pcb/luoye-microphone-board-2026-08-30.epro` | 2026-08-30，当前工程源 |
| 主板原理图 | `hardware/pcb/luoye-mainboard-schematic-2026-06-21.pdf` | 2026-06-21，历史导出 |
| 双麦板原理图 | `hardware/pcb/luoye-microphone-board-schematic-2026-06-21.pdf` | 2026-06-21，历史导出 |
| 外壳/底壳/内壳 | `hardware/mechanical/luoye-enclosure-*-v2.step` | 2026-08-13 |
| 两类按钮 | `hardware/mechanical/luoye-button-*-v2.step` | 2026-08-07 |

## 已确认的基线差异

- 原理图 PDF 早于 EPRO；其中主板 PDF 仍显示 nRF52840，而当前固件目标为 ESP32-S3。
- 机械 STEP 早于最新 ECAD，尚未与 2026-08-30 板框和接口位置重新对齐。
- 仓库没有与当前 EPRO 匹配的生产 BOM、Gerber、钻孔、贴片坐标和 PCB 装配 STEP。
- 固件仍上报硬件标识 `LY-HW-ENG-20260710`；它是工程设备兼容标识，不等于 2026-08-30 ECAD 已量产锁版。

## 投产前必须完成

1. 从确认后的 2026-08-30 EPRO 重新导出原理图 PDF、BOM、Gerber、钻孔和贴片坐标。
2. 生成最新主板、麦克风板及连接器的装配 STEP，并与五个机械 STEP 联合干涉检查。
3. 复核固件 `board_pins` 与最终原理图的引脚、极性、上拉和电源域。
4. 核对充电电流、电池极性、USB 供电、热设计、屏幕接口和 SD 信号完整性。
5. 检查屏幕、USB、SD、麦克风孔、按钮行程、螺柱、电池空间和装配公差。
6. 首件完成上电、充电、录音、SD、Wi-Fi、电子墨水屏和长时间稳定性测试。
7. 建立明确的 PCB、麦克风板、机械和整机修订号，再制作独立硬件 Release。

在上述项目完成前，README 实物照片和本目录源文件均应标记为 Engineering reference，不应发送给生产方作为唯一制造依据。

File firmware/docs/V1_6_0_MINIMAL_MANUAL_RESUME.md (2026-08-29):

# V1.6.0 R2 最小化手动断点续传

本版从稳定的V1.5.2重新建立，不包含V1.6.0 R1的NVS自动恢复设计。

唯一行为变化：

- 设置键离开同步进度页时，只返回主页，不取消后台上传。
- 再次进入同步页并按待办键确认时，立即重新武装上传调度，取消旧的重试等待时间。
- 上传任务重新选择SD卡中的原会话；对于 `bulk`/`repair` 会话，下一步仍然调用服务器 `upload-plan`。
- 服务器返回的 `missing_ranges` 是续传位置的唯一依据。
- 同步确认页不再根据可能滞后的本地 `backlog_s` 宣称“当前没有待传录音”，而是始终允许检查服务器并继续。

保持不变：

- 10 MiB范围与SHA校验。
- 单上传任务。
- TCP、HTTP缓冲、Wi-Fi省电切换和SD 20 MHz参数。
- 每个完整范围收到服务器确认后写入SD卡 `upload.state`。
- `/complete` 成功且 `missing_ranges=[]` 后才完成并清理本地录音。
- V1.5.2电量显示与V1.5.1墨水屏刷新策略。

本版不承诺无人操作的断电自动上传。设备复位后，用户重新进入同步页并确认一次，即可继续服务器尚未收到的范围。

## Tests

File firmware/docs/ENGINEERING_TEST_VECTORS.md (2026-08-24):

# 落叶 v0.6.1-cloud-v1 Engineering 测试向量

目标：证明任何一个烧录包都能追溯到唯一源码，并能从串口判断各子系统初始化结果。

## 1. 自动门禁

| ID | 输入 | 预期 |
|---|---|---|
| `ENG-001` | `tools/run_state_test.bat` | 退出码 0，现有交互断言全部通过 |
| `ENG-002` | `build_profile.ps1 -Profile dev` | app descriptor=`0.6.1-cloud-v1`，target=`esp32s3` |
| `ENG-003` | `build_profile.ps1 -Profile rc -FullClean` | 无编译错误；产物地址来自 `flasher_args.json` |
| `ENG-004` | dirty Git 工作树运行打包 | 必须拒绝 |
| `ENG-005` | 版本不一致运行打包 | 必须拒绝 |
| `ENG-006` | 正确 RC 构建运行打包 | 生成 flash/symbols ZIP、manifest 和 SHA-256 sidecar |
| `ENG-007` | 解压两个 ZIP | 所有 `SHA256SUMS.txt` 校验通过 |
| `ENG-008` | 源码敏感词扫描 | 不得存在私钥、生产证书、真实 WiFi 密码或 Token |
| `ENG-009` | `tools/run_provisioning_test.bat` | 表单解码、UTF-8 SSID 和 WiFi 长度边界通过 |
| `ENG-010` | `tools/run_provisioning_static_checks.ps1` | 固定 HTTPS、无账号字段、无插拔卡文案 |
| `ENG-011` | `tools/run_upload_protocol_test.bat` | 分片边界、ACK、幂等键、HTTP 分类与退避通过 |
| `ENG-012` | `tools/run_cloud_sync_static_checks.ps1` | 持久字段、全会话扫描、SHA/幂等请求头和本地保留策略通过 |
| `ENG-013` | `tools/run_live_protocol_test.bat` | revision、连续偏移、UTF-8、文本长度和查询游标边界通过 |
| `ENG-014` | `tools/run_live_ui_static_checks.ps1` | 活动会话、安全边界、会议/翻译页面和 15 秒刷新门禁通过 |
| `ENG-015` | `tools/run_agenda_protocol_test.bat` | UTF-8、revision、账号代际、最近提醒和查询游标通过 |
| `ENG-016` | `tools/run_agenda_todo_static_checks.ps1` | 原子缓存、RTC、待办旁路、账号隔离和全 FAST 刷新门禁通过 |
| `ENG-017` | dev + HTTP origin 但无 `-AllowInsecureHttp` | 构建脚本必须拒绝 |
| `ENG-018` | rc/release + HTTP origin | 即使传开关也必须拒绝 |
| `ENG-019` | 普通 409 注入 | create/chunk/mark/action 均不得推进成功状态 |
| `ENG-020` | `TODO_REVISION_MISMATCH` | action 回到 result 轮询，不标记 created/cancelled |

## 2. 启动日志

每次启动必须出现且内容一致：

```text
LY|BOOT|product=Luoye version=0.6.1-cloud-v1 ... commit=<12hex> dirty=0 ...
LY|HW|... flash=16777216 psram=8388608 ...
LY|COMPAT|api=luoye-device-api/1 ...
LY|INIT|subsystem=nvs ...
LY|INIT|subsystem=event_queue ...
LY|INIT|subsystem=timers ...
LY|INIT|subsystem=led ...
LY|INIT|subsystem=ui ...
LY|INIT|subsystem=keys ...
LY|INIT|subsystem=power_i2c ...
LY|INIT|subsystem=storage_sd ...
LY|INIT|subsystem=audio_pdm ...
LY|INIT|subsystem=agenda_todo ...
LY|INIT|subsystem=network ...
LY|BOOT_READY|ok=... degraded=... failed=... event_drops=0
```

错误码：

| 范围 | 子系统 |
|---|---|
| `LYE-100` | NVS |
| `LYE-110`～`LYE-120` | 事件队列和状态机定时器 |
| `LYE-200`～`LYE-220` | LED、屏幕、按键 |
| `LYE-300` | 电源与 I²C |
| `LYE-310` | SD |
| `LYE-320` | PDM 音频 |
| `LYE-330` | 网络 |

## 3. 故障向量

| ID | 操作 | 预期 |
|---|---|---|
| `ENG-HW-001` | 软件注入存储不可用 | 显示“存储不可用/录音未保存”，不提示插拔卡 |
| `ENG-HW-002` | 无 WiFi 凭据启动 | network 初始化可完成，业务状态保持离线 |
| `ENG-HW-003` | 断开墨水屏启动 | `ui=FAILED, code=LYE-210` 或刷新错误；其余日志仍可读 |
| `ENG-HW-004` | I²C 总线器件不可达 | `power_i2c` 错误可定位，不打印密码/Token |
| `ENG-HW-005` | 麦克风初始化失败 | `audio_pdm=FAILED, code=LYE-320`，按 REC 拒绝假录音 |
| `ENG-HW-006` | 注入满事件队列 | `LY|EVENT_DROP` 计数增长并限频报警 |
| `ENG-HW-007` | 无 WiFi 凭据长按 BACK 3 秒 | 出现无需密码的 `LUOYE-XXXX` 开放 SoftAP 和 `192.168.4.1` |
| `ENG-HW-008` | 提交错误 WiFi 密码 | 不覆盖 NVS 中已验证的旧凭据；页面可重试 |
| `ENG-HW-009` | 提交正确 WiFi | 获得 IP 后才写 NVS，复位后自动重连 |
| `ENG-HW-010` | 服务器 pair API 不可达 | 显示“服务器不可用”，本地录音正常 |
| `ENG-HW-011` | 账号 A Claim，账号 B 查询 | A 可见设备，B 不可见；需要服务器联调 |
| `ENG-HW-012` | 离线连续录制 A、B 后重启联网 | 两个目录均保留，补传任务依次发现两个会话 |
| `ENG-HW-013` | 每个分片 ACK 前断网/复位 | `acked_pcm_bytes` 不前进，恢复后用相同 seq/offset/SHA 重发 |
| `ENG-HW-014` | 服务端收到分片但丢弃响应 | 重发命中同一幂等键，服务端音频只拼接一次；需要服务器联调 |
| `ENG-HW-015` | 恰好录制 160 KiB PCM | 分片 ACK 后仍单独发送 final，最终 `final_acked=true` |
| `ENG-HW-016` | 上传完成 | 固定式 SD 中 WAV、marks 和 manifest 仍存在 |
| `ENG-HW-017` | 活动录音不足 160 KiB | 不上传不稳定尾片；达到完整分片后才发送 |
| `ENG-HW-018` | 服务端返回旧 revision、回退偏移或错误会话 ID | 拒绝结果，屏幕保留上一有效 revision |
| `ENG-HW-019` | 翻译返回同一 revision 原文/译文 | 译文页和双语页内容一致，BACK 三页循环 |
| `ENG-HW-020` | 在线录音时断网再恢复 | 离线页保持录音；恢复后从已持久化 revision 继续 |
| `ENG-HW-021` | 连续字幕回屏 4 小时 | 无镜像、错位、严重残影、栈溢出或持续内存下降 |
| `ENG-HW-022` | 缓存未来提醒后断网关机 | 使用 light sleep；PCF8563 到点唤醒并显示正确标题 |
| `ENG-HW-023` | 提醒页按 MARK | 10 分钟后再次提醒，RTC 只编程一次，不提前/重复触发 |
| `ENG-HW-024` | 按住 MARK 说“明晚七点学生会” | 本地生成单声道 WAV；联网后出现确认页，REC 确认后才显示已创建 |
| `ENG-HW-025` | 待办录音后立即断网/复位 | todo sidecar 保持 queued；恢复后相同幂等键上传且只创建一次 |
| `ENG-HW-026` | 账号 A 留下待办后解绑并绑定 B | B 不显示、不上传、不确认 A 的待办或议程 |

## 4. 真板验收

- 同一 RC 连续复位 20 次，version/commit/hardware/IDF/ELF SHA 前缀一致。
- 开机后墨水屏设备状态页显示 `0.6.1-cloud-v1`（空间不足的页面可显示 `0.6.1`）。
- REC、MARK、BACK、BOOT 行为与 baseline 一致。
- 固定式 SD 录音 10 分钟并播放；左右麦、存储和墨水屏不回归。
- 使用软件故障注入验证存储不可用、写失败、满卡和关闭失败。
- 保存完整串口日志、COM 口、板号、硬件版本和操作者结论。

未完成上述真板测试时，版本状态只能是 `READY_TO_FLASH`，不能标记 `ACCEPTED`。

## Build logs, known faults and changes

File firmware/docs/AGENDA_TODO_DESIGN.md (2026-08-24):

# 落叶 v0.6.1 议程、提醒与语音待办设计

固件版本：`0.6.1-cloud-v1`
设备 API：`luoye-device-api/1`
目标硬件：`LY-HW-ENG-20260710` / ESP32-S3 / PCF8563 / 固定式 SD

## 1. 完成边界

本版本在设备端一次性完成：SNTP/RTC UTC 校时、账号时区显示、revision 议程同步、
原子缓存、最近提醒调度、关机态到点唤醒、提醒三种操作、MARK 语音旁路、断网持久化、
幂等上传、服务端结果确认以及账号代际隔离。

ASR、自然语言时间解析、账号日历写入和跨客户端同步在服务器完成。固件不内置语音
模型，也不接收账号密码。API v1 两端实现已统一，云端闭环仍需真板端到端验收。

## 2. 时间与提醒信息流

```mermaid
flowchart LR
  SNTP["SNTP UTC"] --> SYS["ESP32 system UTC"]
  SYS --> RTC["PCF8563 UTC"]
  API["Agenda API + account offset"] --> CACHE["agenda.json atomic cache"]
  CACHE --> NEXT["nearest reminder"]
  NEXT --> RTCALM["PCF8563 minute/hour/day alarm"]
  RTCALM --> INT["GPIO41 RTC_INT"]
  INT --> STATE["single app event queue"]
  STATE --> UI["FAST EPD reminder"]
```

- RTC、系统时间、议程时间戳全部存 UTC；`timezone_offset_minutes` 只用于墨水屏显示。
- 联网收到 SNTP 后先校准 PCF8563，再重新调度最近提醒。
- 若系统时间早于 2020 年，已通过设备鉴权且 generation 有效的议程响应
  `server_time_utc` 可作为无公网 NTP 环境的启动校时源，并同步写入 PCF8563；
  正常时钟不做覆盖。
- `agenda.json` 使用 `tmp → fsync → rename`，保留 `.bak` 作为损坏回退。
- 提醒页：REC 以议程标题开始会议；MARK 推迟 10 分钟；BACK 确认关闭。
- 录音安全收尾或语音待办采集期间到达的提醒进入状态机待处理槽，不覆盖收尾/采集。

PCF8563 闹钟没有月份字段，因此固件固定请求未来 7 天完整滚动窗口。

## 3. 当前 PCB 的低功耗兼容方案

GPIO41 不是 RTC-IO，无法从 ESP32-S3 deep sleep 唤醒。设备存在已编程提醒时使用
GPIO light sleep，只开放 `RTC_INT` 和 REC 唤醒；长按 REC 仍需持续 3 秒。没有提醒时
继续使用 deep sleep。此方案无需改板，但有提醒期间必须在真板测量静态电流。

## 4. 语音待办信息流

```mermaid
flowchart LR
  MARK["MARK hold"] --> TAP["PDM stereo tap"]
  TAP --> MONO["8x PCM, L/R average"]
  MONO --> WAV["16 kHz mono WAV, max 30 s"]
  WAV --> SIDE["todo.json state"]
  SIDE --> PUT["idempotent audio PUT"]
  PUT --> ASR["server ASR + time parse"]
  ASR --> RESULT["revision result poll"]
  RESULT -->|"needs_confirmation"| CONFIRM["REC confirm / BACK cancel"]
  RESULT -->|"created"| DONE["created ACK UI"]
  CONFIRM --> ACTION["idempotent action POST"]
  ACTION --> DONE
```

- PDM tap 位于主 WAV 静音判断之前，因此主录音暂停时仍能录待办。
- 主录音进行中复用同一 PDM 流；待机时临时开启麦克风和低噪声电源模式。
- 本地路径：`/sdcard/todo/<client_todo_id>/audio.wav` 与 `todo.json`。
- 采集过程中每累计 64 KiB 执行一次 `fflush + fsync`；若异常断电，开机扫描
  `capturing` 条目、按已有 PCM 长度修复 WAV 头，并恢复为待上传队列。
- 状态：`capturing → queued → uploaded → needs_confirmation → confirm_pending → created`；
  取消与永久失败分别持久化为 `cancelled`、`failed`。
- 每次传输失败均保留音频；只有服务端动作 ACK 后才显示“已创建”。
- 确认/取消 action 携带结果 revision 和稳定幂等键；服务器返回
  `TODO_REVISION_MISMATCH` 时重新拉取结果，不能把过期操作当成功。

## 5. 账号隔离

议程和待办都绑定 NVS 中的 `binding_generation`：

- 议程响应 generation 不一致时整包拒绝。
- 解绑或 Token 失效立即清除议程缓存和 RTC 闹钟。
- SD 中旧 generation 待办保留，但新账号不会扫描、显示、上传或确认。
- 服务器仍必须从 Device Token 确定 owner，不能信任设备自报账号。

## 6. 墨水屏与按键

- 待机第 1 页：时钟、账号时区、下一项议程。
- 待机第 2 页：最多四条后续议程。
- 待机第 3 页：网络、云端、绑定、积压、存储、充电和版本。
- 所有产品刷新统一调用 `epd_frame_fast()`；录音字幕 15 秒刷新，待机时钟每分钟刷新。
- 待办流程区分“本地已保存”“等待确认”“已创建”“处理失败”，不以 WiFi 在线冒充云端完成。

## 7. 验证门禁

- `run_agenda_protocol_test.bat`：UTF-8、revision/generation、最近/到期提醒和查询游标。
- `run_state_test.bat`：待机三页、待办采集/确认、RTC 竞态和安全收尾延迟显示。
- `run_agenda_todo_static_checks.ps1`：原子持久化、账号隔离、RTC、音频旁路与全 FAST。
- ESP-IDF v5.5.4 clean build、release manifest、SHA-256 与解压复验。

真板仍需验证：SNTP 写 RTC、离线关机到点唤醒、+10 分钟、30 秒待办、录音中待办、
复位后补传、两账号交叉隔离，以及有提醒/无提醒两种关机电流。

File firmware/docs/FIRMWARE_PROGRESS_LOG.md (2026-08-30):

# 落叶（Luoye）录音卡固件进度日志

> 更新时间：2026-08-14
> 当前活动版本：`v0.9.9-engineering-timeline-font-r1`（`0.9.9`）
> 当前阶段：`BUILD_PASS / READY_TO_FLASH`

## 1. 状态说明

| 状态 | 含义 |
|---|---|
| PLANNED | 范围已定义，尚未编码 |
| IN_PROGRESS | 正在编码或修复 |
| BLOCKED | 被明确的外部依赖阻塞 |
| CODE_COMPLETE | 代码范围完成，尚未完成构建 |
| BUILD_PASS | 干净构建和自动测试通过 |
| READY_TO_FLASH | 产物与清单齐全，可烧录 |
| FLASHED | 已烧录，尚未完成真板验收 |
| BOARD_PASS | 真板专项测试通过 |
| ACCEPTED | 已归档并可作为下一版本基线 |

## 2. 当前基线事实

正式固件目录：

```text
D:\OPENOP\recorder-card-hw-test\firmware\recorder-card
```

当前工程情况：

- Git：已初始化；当前开发分支 `codex/luoye-api-v1`
- baseline commit：`ed04e41de642be1fecb1391b9f78d77e5c8dfd32`
- baseline tag：`luoye-fw-v0.1.0-baseline`
- v0.1.1 RC commit：`120f90404b7bfd905ec0ea7a52687bea861a5ccb`
- v0.1.1 RC tag：`luoye-fw-v0.1.1-engineering-rc.1`
- v0.1.1 CMake 项目版本：`0.1.1-engineering`
- UI 版本来源：ESP app descriptor（不再手写第二份版本）
- 目标芯片：ESP32-S3
- Flash：16 MiB
- PSRAM：8 MiB
- 当前分区：factory 6 MiB + assets 8 MiB，**没有 OTA 分区**
- 最近观察到的新板串口：COM22（每次烧录仍需重新确认）
- 当前状态机回归结果：通过，72 次渲染调用
- 已有真板证据：I²C、墨水屏显示、按键、双麦、SD、WiFi 基本通过
- v0.1.1 RC 尚缺：正式烧录日志和真板验收

Git 初始化前的构建产物（历史证据，不能作为发布包）：

| 文件 | 大小 | 时间 | SHA-256 |
|---|---:|---|---|
| `recorder_card.bin` | 1,078,832 B | 2026-07-30 11:48:20 | `A42A38888F5E877A304BA5C98326831EFD96739778E20B1B130444E3CA573C02` |
| `bootloader.bin` | 22,272 B | 2026-07-14 18:11:19 | `B558981B61876F17DECA1679D607D99DFC3BE35071E02DE270CCFC993837D21B` |
| `partition-table.bin` | 3,072 B | 2026-07-14 18:08:56 | `790DA65D2865060DEAA60622AC02D0E47FF454DDB426729351593934AD9ACC45` |
| `assets.bin` | 8,388,608 B | 2026-07-30 11:48:02 | `8DD07AAAE9BE6569F8158CB7637530FAE79A0A4AF350B2767196B8B35C9BB4CB` |

已标记的 `v0.1.0` 源码/构建 baseline：

| 文件 | SHA-256 |
|---|---|
| `recorder_card.bin` | `179FBC57E0DB2754DF305E1BC397318A8B9ED0D5AB624828663696DF221B9B6B` |
| `bootloader.bin` | `C5B50333900677D76E678F27AA5E35969F8F8ABEFE0EA9CCAD02869F99C1720F` |
| `partition-table.bin` | `790DA65D2865060DEAA60622AC02D0E47FF454DDB426729351593934AD9ACC45` |
| `assets.bin` | `8DD07AAAE9BE6569F8158CB7637530FAE79A0A4AF350B2767196B8B35C9BB4CB` |

该 baseline 已通过 PC 回归和干净构建，但未完成正式固件真板验收，因此状态是
`BUILD_PASS`，不是 `ACCEPTED`。

## 3. 版本总进度

| 版本 | 目标 | 状态 | 构建 | 烧录 | 真板 | 结论 |
|---|---|---|---|---|---|---|
| `v0.1.0-baseline` | 冻结当前基线 | BUILD_PASS | 通过 | 未执行 | 待记录 | 源码/构建已冻结 |
| `v0.1.1-engineering` | 版本、日志、测试工程化 | BOARD_PASS | RC.1 通过 | COM22 成功 | 用户确认功能通过 | 待 20 次复位后 ACCEPTED |
| `v0.2.0-storage-safe` | 可靠录音与安全收尾 | READY_TO_FLASH | dev.2 通过 | dev.1 已烧录 | dev.1 栈溢出 | dev.2 待真板 |
| `v0.3.0-provisioning` | SoftAP 配网和账号绑定 | READY_TO_FLASH / SERVER_BLOCKED | dev.1 通过 | 未执行 | 待验证 | SoftAP 包就绪，服务器 API 缺失 |
| `v0.4.0-cloud-sync` | 持久离线补传 | READY_TO_FLASH / SERVER_BLOCKED | dev.1 通过 | 未执行 | 待验证 | 设备包已冻结，服务器 API 缺失 |
| `v0.5.0-live-ai-ui` | 字幕、翻译、HTML V2 | READY_TO_FLASH / SERVER_BLOCKED | dev.1 通过 | 未执行 | 待验证 | dev.1 已冻结，服务器 0.4 API 缺失 |
| `v0.6.0-agenda-todo` | 议程、提醒、语音待办 | READY_TO_FLASH / SERVER_BLOCKED | RC 全量构建通过 | 未执行 | 待验证 | 工程包已冻结，云端依赖 0.5-draft |
| `v0.6.1-cloud-v1` | 三端 API v1 收敛 | BUILD_PASS / API_V1_INTEGRATION | 6 组主机测试、4 组静态门禁、clean build 通过 | 未执行 | 待验证 | 不打包、不烧录；等待三端端到端联调 |
| `v0.7.0-power-recovery` | 电源、恢复、长稳、固定 SD 管理 | BUILD_PASS | 主机测试、静态门禁、ESP-IDF dev build | 待执行 | 待验证 | 与 ClearMeeting 0.13.0 成套部署 |
| `v0.8.0-ota-security` | OTA 与安全加固 | PLANNED | — | — | — | — |
| `v0.9.0-rc` | 发布候选 | PLANNED | — | — | — | — |
| `v1.0.0` | 正式发布 | PLANNED | — | — | — | — |

## 4. Baseline 收尾与当前活动版本

### v0.1.0-baseline

### 范围

- [x] 初始化正式固件 Git 仓库。
- [x] 增加适合 ESP-IDF 的 `.gitignore`。
- [x] 固定 ESP-IDF v5.5.4 构建证据。
- [x] 清理并重新生成 build。
- [x] 重新运行状态机测试。
- [ ] 生成 baseline manifest 和 SHA-256。
- [ ] 确认开发板串口。
- [ ] 烧录 baseline 候选版本。
- [ ] 保存完整串口日志。
- [ ] 执行通用硬件冒烟测试。
- [ ] 记录所有已知限制。
- [x] 标记 `luoye-fw-v0.1.0-baseline`。

### 不在本版本范围

- SoftAP 配网
- 账号绑定
- 可靠离线补传
- 字幕和翻译
- 议程和语音待办
- OTA 和 eFuse 安全配置

### 完成标准

- 当前源码可以从干净环境重复构建。
- 烧录后的版本、commit 和归档 manifest 完全一致。
- 现有按键、LED、屏幕、录音、SD 和 I²C 行为无回归。
- 上述证据全部记录后，状态才从 `BOARD_PASS` 改为 `ACCEPTED`。

### v0.1.1-engineering

- [x] 统一内部产品名为落叶 / Luoye。
- [x] CMake 单一注入 `PROJECT_VER`、commit、dirty、硬件版本和构建类型。
- [x] UI 改为读取 ESP app descriptor 版本。
- [x] 增加 `LY|BOOT / LY|INIT / LY|BOOT_READY` 结构化日志。
- [x] 增加 `LYE-xxx` 错误码和子系统状态快照。
- [x] 事件队列投递失败计数并限频报警。
- [x] 固化 dev / rc / release 构建配置。
- [x] 建立 API draft、session manifest draft 和测试向量。
- [x] 建立 release manifest 与 SHA-256 打包脚本。
- [x] 在正式分支提交精确源码。
- [x] 运行 PC 回归、RC fullclean 构建和打包。
- [x] 生成 `luoye-fw-v0.1.1-engineering-rc.1`。
- [x] 确认串口并烧录 RC.1。
- [x] 确认“按键后屏幕不更新”由接错屏幕造成，RC.1 无固件缺陷。
- [x] 撤销 RC.2 代码并删除 RC.2 标签、发布包和生成目录。
- [x] 用户确认 RC.1 墨水屏、按键、录音、标记、暂停/继续和收尾功能正常。
- [ ] 保存 20 次启动和整机冒烟测试证据。

## 5. 当前阻塞项

| ID | 阻塞项 | 影响版本 | 解除条件 | 状态 |
|---|---|---|---|---|
| B-001 | 线上服务器源码比本地源码更新 | v0.3+ | 导出线上准确源码、DB schema、配置和迁移 | CLOSED：已取得统一源码基线 |
| B-002 | 设备 API 请求/响应未冻结 | v0.3+ | 三端实现 `luoye-device-api/1` | CLOSED：2026-08-01 契约冻结 |
| B-003 | 新 PCB RTC_INT 实际引脚尚未同步到正式 `board_pins.h` | v0.7 | 核对网表并真板验证深睡唤醒 | OPEN |
| B-004 | 当前工程没有 Git/版本注入 | 全部版本 | 完成 v0.1.1-engineering | CLOSED |
| B-005 | 新板当前未连接，系统仅见蓝牙 COM3/COM4 | v0.1.1 | 重新连接新板并识别 Espressif 串口 | CLOSED |

## 6. 风险台账

| ID | 风险 | 严重度 | 应对版本 | 状态 |
|---|---|---:|---|---|
| R-001 | SD 写失败时界面仍显示录音 | P0 | v0.2 | OPEN |
| R-002 | 收尾 3.2 秒不等待文件真正闭合 | P0 | v0.2 | OPEN |
| R-003 | 重启/新会话使旧上传进度永久丢失 | P0 | v0.4 | OPEN |
| R-004 | 默认 HTTP 明文传输音频和 Token | P0 | v0.3/v0.4 | OPEN |
| R-005 | 设备 ID 只有 MAC 后四位，可能碰撞 | P0 | v0.3 | OPEN |
| R-006 | 线上和本地后端源码不一致 | P0 | v0.3 Gate | OPEN |
| R-007 | 账号换绑可能错误转移旧 backlog | P0 | v0.3/v0.4 | OPEN |
| R-008 | RTC_INT 仍配置为 GPIO41，不能深睡唤醒 | P1/P0* | v0.7 | OPEN |
| R-009 | 单 factory 分区，无 OTA/回滚 | P1 | v0.8 | OPEN |
| R-010 | Secure Boot/Flash/NVS encryption 未启用 | P1 | v0.8 | OPEN |
| R-011 | 当前中文字体仅允许开发原型使用，可能阻断量产分发 | P1 | v0.8 | OPEN |
| R-012 | 曾误判 GDEY0213B74 深睡后刷新失败 | P1 | v0.1.1 | CLOSED：根因为接错屏幕，RC.2 已撤销 |

`*`：若“关机后到点提醒”是必须承诺，则 R-008 为 P0。

## 7. 工作日志

### 2026-07-30 — 规划与基线审计

**版本**：`v0.1.0-baseline`

**完成内容**：

- 完成 HTML 交互、正式固件、服务器和线上接口的交叉审计。
- 固定 WiFi 直传、SD 优先、单账号拥有者、异步云端处理等产品规则。
- 形成版本路线图、发布门禁和进度日志。
- 记录现有 build 产物大小与 SHA-256。

**发现问题**：

- 正式固件目录尚无 Git。
- 当前项目没有 CMake 版本信息。
- 线上服务器设备路由存在，但对应源码不在本地仓库。
- 当前 build 不是经过本门禁重新产生的 accepted 基线。

**下一步**：

1. 在正式固件目录建立源码版本基线。
2. 固定 ESP-IDF 版本并执行干净构建。
3. 生成 `v0.1.0-baseline-rc.1` 产物。
4. 经用户确认串口后烧录并保存日志。
5. 真板通过后标记 baseline accepted，再开始 `v0.1.1-engineering`。

### 2026-07-30 21:08 — 启动落叶 v0.1.1-engineering

**版本**：`v0.1.1-engineering`
**阶段变化**：`PLANNED → IN_PROGRESS`
**证据等级**：本地源码与构建确认

**已完成**：

- 正式目录初始化 Git，冻结 commit `ed04e41de642be1fecb1391b9f78d77e5c8dfd32`。
- 建立 annotated tag `luoye-fw-v0.1.0-baseline`。
- baseline 状态机测试通过，ESP-IDF v5.5.4 干净构建通过。
- 当前工作分支切换为 `codex/luoye-v0.1.1-engineering`。
- 设计单一版本源、启动诊断、统一错误码、构建配置和归档门禁。

**决定**：

- `v0.1.0` 保留为不可移动的源码/构建锚点。
- `v0.1.1-engineering` 是第一份准备正式烧录验收的“落叶工程 baseline”。
- 暂定硬件标识为 `LY-HW-ENG-20260710`；量产前必须换成正式 PCB revision。

**未完成**：

- v0.1.1 代码提交、RC 干净构建和发布包。
- COM 口确认、烧录、20 次启动一致性和整机真板验收。

### 2026-07-30 21:41 — 落叶 v0.1.1 RC.1 进入 READY_TO_FLASH

**版本**：`v0.1.1-engineering`
**阶段变化**：`IN_PROGRESS → CODE_COMPLETE → BUILD_PASS → READY_TO_FLASH`
**证据等级**：本地精确源码、干净构建、归档解包校验

**版本组合**：

- 固件 commit：`120f90404b7bfd905ec0ea7a52687bea861a5ccb`
- annotated tag：`luoye-fw-v0.1.1-engineering-rc.1`
- 硬件标识：`LY-HW-ENG-20260710`
- 构建类型：`rc`
- API contract：`luoye-device-api/0.1-draft`
- ESP-IDF：`v5.5.4`

**代码修改**：

- 建立 Luoye 单一版本源、commit/dirty/硬件/构建类型注入。
- 增加 `LY|BOOT`、`LY|INIT`、`LY|BOOT_READY`、`LYE-xxx` 诊断。
- 让各硬件初始化返回真实错误；事件队列失败可观测。
- 建立 dev/rc/release 构建配置、归档清单、SHA-256 和 API/测试文档。
- 构建入口每次先 reconfigure，防止增量构建沿用旧 Git 身份。
- 打包器兼容 Windows PowerShell 5.1、CRLF 和 UTF-8 产品名。

**自动测试**：

- 状态机/界面回归：全部通过，43 次渲染调用。
- PowerShell 脚本语法：通过。
- 发布包：压缩后解包，`SHA256SUMS.txt` 逐文件复验通过。

**构建**：

- Git dirty：`false`
- 内嵌 commit：`120f90404b7b`
- App 大小：`0x100640`（1,050,176 B），app 分区剩余 83%。
- `bootloader.bin`：`1888c9d31f5ded5c33fccee31747ce5b191c3ba335ec5a47257ce1ef25e0ec84`
- `partition-table.bin`：`790da65d2865060deaa60622ac02d0e47ff454ddb426729351593934ad9acc45`
- `recorder_card.bin`：`80a0f32ad57b56adbf65db33c8caedcbaaee154943acff4f84c9b9903e624dac`
- `assets.bin`：`8dd07aaae9be6569f8158cb7637530fae79a0a4af350b2767196b8b35c9bb4cb`

**归档**：

- Flash ZIP SHA-256：`682746d00936a310a7a9c78ccf9d5bd5775a6ba8063ea6d62cf6ec23df9608ca`
- Symbols ZIP SHA-256：`a80abeef4cc65793ee8d55acc2dc94993e33ff826ec8a910f1f4f0667ef5be6b`
- 烧录偏移：`0x0` bootloader、`0x8000` partition、`0x10000` app、`0x610000` assets。
- 清单确认：产品中文名“落叶”、版本、commit、硬件标识和四个偏移均正确。

**烧录**：

- 2026-07-30 21:41 扫描仅发现蓝牙 COM3/COM4。
- 未发现 COM22 或其他 Espressif USB 串口；为避免误烧，未执行 flash。

**下一步**：

1. 连接新板并重新识别 Espressif 串口。
2. 仅烧录 tag `luoye-fw-v0.1.1-engineering-rc.1` 对应包。
3. 保存启动日志并核对 `LY|BOOT` 的 version/commit/dirty/profile。
4. 执行 20 次启动一致性、按键、LED、墨水屏、录音、SD、I²C 和 WiFi 冒烟测试。

### 2026-07-30 21:57 — RC.1 已烧录至新板

**版本**：`v0.1.1-engineering`
**阶段变化**：`READY_TO_FLASH → FLASHED`
**证据等级**：COM22 真板启动日志

**烧录结果**：

- 四个镜像均完成写入并显示 `Hash of data verified`。
- 烧录端口：COM22。
- 未执行整片 `erase_flash`，仅擦写发布清单中的四个区域。

**启动身份**：

- version：`0.1.1-engineering`
- commit：`120f90404b7b`
- dirty：`0`
- hardware：`LY-HW-ENG-20260710`
- flavor：`rc`
- ESP-IDF：`v5.5.4`
- reset：`POWERON`

**初始化结果**：

- `nvs / event_queue / timers / led / ui / keys / power_i2c / storage_sd / audio_pdm / network` 全部 `status=OK`。
- `LY|BOOT_READY`：`ok=0x000003ff degraded=0x00000000 failed=0x00000000 event_drops=0`。
- SD 挂载成功，容量约 15,193 MB。
- PDM：2.048 MHz、16 kHz 双声道、软件增益 8x。
- WiFi 无凭据，按设计保持离线，不影响 SD 录音。

**观察项**：

- ESP-IDF 输出 I²C 上拉检查提示，但 `power_i2c=ESP_OK`，当前不是失败。
- SD 初始化阶段的 CMD52/CMD5 “not supported” 是 SPI 模式探测过程；随后挂载成功。

**下一步**：

1. 完成 LED、按键、墨水屏方向与内容的人工检查。
2. 录制并回放左右声道 WAV，检查增益、底噪和远场效果。
3. 设置 WiFi 凭据并验证配网流程。
4. 完成 20 次复位启动一致性后，才进入 `BOARD_PASS`。

### 2026-07-30 22:13 — RC.2 临时修复尝试（已撤销）

> 2026-07-30 22:22 更正：后续确认根因是接错屏幕，RC.1 固件正常。
> 本节仅保留审计过程；RC.2 标签、发布包、生成目录和代码修改均已撤销，不得烧录。

**版本**：`v0.1.1-engineering`
**阶段变化**：`FLASHED（RC.1）→ READY_TO_FLASH（RC.2）`
**证据等级**：RC.1 COM22 真板复现 + RC.2 本地全量构建/归档校验

**RC.1 复现**：

- 短按 REC 后红灯常亮。
- 串口出现 `LY|REC|action=start result=ok`。
- 墨水屏仍停留在待机首帧，没有进入录音页面。
- 结论：按键、事件队列和录音状态机正常；故障位于 EPD 后续刷新路径。

**RC.2 修改**：

- GDEY0213B74 从 deep sleep 唤醒前，循环一次屏幕外部电源，再执行硬件复位。
- FAST/PART 暂时统一降级为已验证的全刷路径。
- 首次发生降级时输出 `LY|UI|safe_refresh=full` 诊断日志。
- 代价：页面刷新更慢且会闪屏；快刷在单独完成真板波形验证后再恢复。

**构建与归档**：

- commit：`3cd50ef489446f42a5f9d83a1bc7f2c8cabe85cd`
- tag：`luoye-fw-v0.1.1-engineering-rc.2`
- 状态机/界面回归：全部通过，43 次渲染调用。
- RC.2 全量构建：通过。
- App：1,049,136 B，SHA-256 `2645cbf4eaa1dbdb627bee00f46e81a30a484e4cbb071ab1f4a38b1c6effdefb`
- Flash ZIP SHA-256：`77f42425f99aec4d4631c59eaa92a029dee0ccdb66d671d3d35180fd73aa11ec`
- Symbols ZIP SHA-256：`f453a7e70891160e5f994ba835144cacc72cbe0f1febfaf9b90309b27a8cf744`

**当时计划（已作废）**：

- 原计划烧录 RC.2 验证刷新；根因更正后取消，RC.2 未烧录。

### 2026-07-30 22:22 — 撤销 RC.2，RC.1 进入 BOARD_PASS

**版本**：`v0.1.1-engineering`
**阶段变化**：`READY_TO_FLASH（RC.2）→ BOARD_PASS（RC.1）`
**证据等级**：用户真板更正与功能确认

**更正结论**：

- RC.1 的按键、事件、录音和 GDEY0213B74 刷新逻辑均正常。
- 此前“按键后屏幕不更新”由接错屏幕造成，不是 RC.1 固件问题。
- 用户确认墨水屏页面切换、按键、录音、MARK、暂停/继续、结束收尾及其余检查功能正常。

**RC.2 清理**：

- 删除 annotated tag `luoye-fw-v0.1.1-engineering-rc.2`。
- 删除 RC.2 Flash/Symbols ZIP 及两个 SHA-256 sidecar。
- 删除生成目录 `build-rc2`。
- commit `e4fe7b0` 通过 Git revert 撤销 RC.2 的 EPD/UI 代码，不改写审计历史。
- RC.1 tag `luoye-fw-v0.1.1-engineering-rc.1` 与四个发布文件保持不变。

**当前结论**：

- RC.1 状态：`BOARD_PASS`。
- 尚未执行 20 次复位启动一致性，因此暂不进入 `ACCEPTED`。
- 后续所有烧录继续使用 RC.1，不得使用已撤销的 RC.2。

## 8. 后续日志模板

### 2026-07-30 22:30 — 启动 v0.2.0 可靠录音与断电恢复

**版本**：`0.2.0-dev.1`
**阶段变化**：PLANNED → IN_PROGRESS
**目标**：SD 可靠录音、安全收尾、录音中断电后的启动修复。

**代码修改**：

- 新增 `STARTING`、`CLOSING`、`STORAGE_ERROR` 三个真实状态。
- 屏幕仅在 `APP_EV_SESSION_CLOSE_DONE` 后显示“本地已保存”。
- 会话 ID 改为设备 MAC + NVS 单调计数器 + 随机后缀。
- 每段录音创建 `session.json`、`audio.wav`、`marks.jsonl`、`upload.state`。
- 所有写入、刷新、同步和关闭返回值进入统一错误处理。
- 启动扫描未闭合会话，按实际文件长度修复 WAV 头和 JSONL 尾部。
- 增加音频环形缓冲丢弃样本与溢出次数统计。

**自动测试**：

- `tools\run_state_test.bat`：通过。
- `tools\run_storage_test.bat`：通过。
- 覆盖“未收到关闭完成不能显示已保存”、写卡失败、关闭同步失败、
  低电安全收尾、WAV 奇数尾字节和 JSONL 半条记录。

**下一步**：

- 完成 ESP-IDF v5.5.4 干净构建并修复编译差异。
- 生成 `0.2.0-dev.1` 工程烧录包。
- 真板依次执行拔卡、满卡、录音中复位和 2 小时连续录音。

### 2026-07-30 23:10 — v0.2.0-dev.1 首次构建通过

**版本**：`0.2.0-dev.1`
**阶段变化**：IN_PROGRESS → BUILD_PASS

**自动测试**：

- 状态机回归：通过，40 次渲染请求。
- 存储格式与断电尾部测试：通过。
- `git diff --check`：通过。

**构建**：

- ESP-IDF：`v5.5.4`
- Target：`esp32s3`
- Profile：`dev`
- App 大小：约 1.11 MiB，factory 分区余量约 82%。
- 结果：完整构建和加固后的增量构建均通过。

**风险边界**：

- 当前 `BUILD_PASS` 只证明代码和构建通过，不等于 SD 真板故障注入通过。
- 未对用户板上的 `v0.1.1-engineering-rc.1` 执行覆盖烧录。
- 生成开发烧录包后仍需验证拔卡、满卡、录音中复位和长录音。

### 2026-07-30 23:20 — v0.2.0-dev.1 开发包冻结

**版本**：`0.2.0-dev.1`
**阶段变化**：BUILD_PASS → READY_TO_FLASH

**版本组合**：

- 源码 commit：`2231aadc0b3aee7e020c52325afab3443dc5c773`
- annotated tag：`luoye-fw-v0.2.0-dev.1`
- 构建 profile：`dev`
- 固件 manifest：`dirty=false`，target=`esp32s3`，Flash 文件数=`4`

**发布产物**：

- `releases\luoye-fw-v0.2.0-dev.1-flash.zip`
- Flash ZIP SHA-256：
  `5dec6e3162317fe09c68d3ae7a3307f39ddd788a1cf5be643b74275abda8cc2f`
- `releases\luoye-fw-v0.2.0-dev.1-symbols.zip`
- Symbols ZIP SHA-256：
  `210841aad2058f19bd35dc9257d610e27b3a60041f2042dcf3e835c80398b134`

**结论**：

- 可以烧入专用测试板开始 SD 故障注入。
- 该包尚未标记 `BOARD_PASS`，不得替代已确认正常的 RC.1 生产基线。

### 2026-07-30 23:35 — 撤销 v0.2.0-dev.1

**版本**：`0.2.0-dev.1`
**阶段变化**：READY_TO_FLASH → REVOKED

**真板证据**：

- app descriptor、commit 和 ELF 均与 dev.1 manifest 一致。
- 启动到 `LY|INIT|subsystem=led status=OK` 后触发
  `A stack overflow in task main has been detected`。
- Backtrace 已用 dev.1 ELF 符号化，确认由
  `vApplicationStackOverflowHook` 触发；不是 SD 读写错误。
- 构建配置 `CONFIG_ESP_MAIN_TASK_STACK_SIZE=3584`，UI/文件系统初始化调用链
  已超过该余量。

**修复决策**：

- dev.1 标签保留用于追踪，但烧录包不得继续使用。
- 新版本号为 `0.2.0-dev.2`，不覆盖、复用 dev.1 产物。
- 主任务栈提高到 8192 字节。
- 在 boot、UI 前后、storage 后和 boot-ready 输出主任务最小剩余栈水位。

**下一步**：

- 构建 dev.2 并确认固件描述中的版本和新栈配置。
- 重新烧录真板，要求日志完整到 `LY|BOOT_READY` 和
  `LY|STACK|task=main stage=boot_ready`。

### 2026-07-30 23:55 — v0.2.0-dev.2 修复包冻结

**版本**：`0.2.0-dev.2`
**阶段变化**：IN_PROGRESS → BUILD_PASS → READY_TO_FLASH

**修复内容**：
- 将 `CONFIG_ESP_MAIN_TASK_STACK_SIZE` 从 3584 提高到 8192 字节。
- 在 boot、UI 前后、storage 后和 boot-ready 输出 `LY|STACK` 主任务栈水位。
- `v0.2.0-dev.1` 保留标签用于追溯，但已撤销，禁止继续烧录。

**自动测试与构建**：
- 状态机回归：通过，40 次渲染请求。
- 存储格式与断电尾部测试：通过。
- ESP-IDF `v5.5.4`、target `esp32s3`、dev profile 干净构建：通过。
- 生成配置确认：`CONFIG_ESP_MAIN_TASK_STACK_SIZE=8192`。

**版本组合**：
- 源码 commit：`01d0d367dee5816ce1088e288d5bad7e7d754e22`
- annotated tag：`luoye-fw-v0.2.0-dev.2`
- App：1,112,000 B
- App SHA-256：`8bbe009343813048d1388b9677978a88d5ea6b516f36feab96cc9491a1e0c188`
- manifest：`dirty=false`，target=`esp32s3`，Flash 文件数=`4`

**发布产物**：
- `releases\luoye-fw-v0.2.0-dev.2-flash.zip`
- Flash ZIP SHA-256：
  `ad492f324050d0792bbdaaaddd35e3c77465bf7754840832907689fe0daae793`
- `releases\luoye-fw-v0.2.0-dev.2-symbols.zip`
- Symbols ZIP SHA-256：
  `d31ec0dd3f658c86da26635a05f1809e5df86a370a00da88ac603b65cd15b296`

**结论**：
- `dev.2` 可以烧入专用测试板验证完整启动。
- 尚未完成真板启动和 SD 故障注入，因此不得标记 `BOARD_PASS`。

**下一步**：
- 烧录后核对 `version=0.2.0-dev.2 commit=01d0d367dee5 dirty=0`。
- 串口必须先后出现 `LY|STACK ... after_ui`、`LY|STACK ... after_storage`、
  `LY|BOOT_READY` 和 `LY|STACK ... boot_ready`。

### 2026-07-31 00:40 — 启动 v0.3.0 SoftAP 配网和账号绑定

**版本**：`0.3.0-dev.1`
**阶段变化**：PLANNED → IN_PROGRESS → BUILD_PASS / SERVER_BLOCKED

**产品决策**：
- 固定式 SD 不再显示插卡、拔卡、重新插卡、更换卡或检查卡座提示。
- SoftAP 页面只接收 WiFi，不接收账号、账号密码、用户 ID 或服务器地址。
- 用户在 ClearMeeting 登录并用一次性配对码认领设备。
- 未获得可撤销 Device Token 前，固件禁止上传会话和音频。

**设备端代码**：
- BACK 长按 3 秒启动 `LUOYE-XXXX` SoftAP，密码每次随机生成。
- `192.168.4.1` 提供 WiFi 扫描、SSID/密码提交和连接状态接口。
- 候选凭据获得 IP 后才写入 NVS；错误密码不覆盖已验证配置。
- 设备 ID 从 MAC 后四位升级为完整 eFuse MAC 工程 ID。
- 实现 pair code/nonce 请求、状态轮询、Device Token 和脱敏账号保存。
- 墨水屏实现 AP、连接中、WiFi 已连接、待认领、已绑定和错误页面。
- 存储错误统一显示“存储不可用/录音未保存”等固定式存储文案。

**自动测试**：
- 状态机回归：通过，43 次渲染请求，包含配网状态迁移。
- 存储格式与断电尾部测试：通过。
- 配网页表单测试：通过，覆盖 UTF-8 SSID、URL 解码和密码长度边界。
- 静态安全检查：通过，确认固定 HTTPS、无账号输入框、日志不引用敏感值、
  UI 不含可插拔 SD 指令。
- ESP-IDF v5.5.4 增量构建：通过；App 约 1.19 MiB。

**线上服务器核验**：
- `http://meeting.example.invalid:34567/` 当前 Web 可访问。
- `/api/build-info` 返回 404。
- 当前 Web bundle 只有 auth、meetings、agenda 等接口，没有 device pair/claim。
- HTTPS 固件入口、Device Token、账号 Claim、解绑和设备列表尚未实现。

**契约**：
- 新草案：`luoye-device-api/0.2-draft`。
- 设计文档：`docs/PROVISIONING_AND_BINDING_DESIGN.md`。
- 设备端已按草案实现，但在服务器补齐前不得宣称账号绑定端到端完成。

**下一步**：
- 提交设备端源码后执行一次 `dirty=0` 全量构建并生成 SoftAP 真板测试包。
- 取得线上服务器源码、数据库 schema 和部署权限，实现 pair/claim/build-info。
- 真板验证热点可见、网页可打开、WiFi 可保存并在复位后自动重连。

### 2026-07-31 17:04 — v0.3.0-dev.1 SoftAP 工程包冻结

**版本**：`0.3.0-dev.1`
**阶段变化**：BUILD_PASS → READY_TO_FLASH / SERVER_BLOCKED

**版本组合**：
- 源码 commit：`ab837325dcd0e6720399d3bca3eaa67d3d88de07`
- annotated tag：`luoye-fw-v0.3.0-dev.1`
- API contract：`luoye-device-api/0.2-draft`
- server release：`unbound`
- build profile：`dev`
- target：`esp32s3`
- manifest：`dirty=false`

**干净构建**：
- ESP-IDF：`v5.5.4`
- App：1,215,680 B
- App SHA-256：
  `c1541ab51aea21c09764a157f12d55f74a71971053446cf2bb899a3b87b0ed2a`
- factory 6 MiB 分区剩余约 81%。

**发布产物**：
- `releases\luoye-fw-v0.3.0-dev.1-flash.zip`
- Flash ZIP SHA-256：
  `3d4f61e637c512813c14f6a5efa64624491c34583c2ce3df65e87b084593bf7c`
- `releases\luoye-fw-v0.3.0-dev.1-symbols.zip`
- Symbols ZIP SHA-256：
  `61bd997b1a75920160b14b695b6785c5a170867c50a53c5fc587a0b13a443e41`
- 解包后 manifest、版本、commit、API、target 和 4 个 BIN 的大小/哈希全部复验通过。

**允许验证**：
- 长按 BACK 进入配网。
- 随机密码 SoftAP 可见。
- `192.168.4.1` 页面、WiFi 扫描、错误密码重试、正确密码连接。
- 复位后使用已验证凭据自动连接。
- 固定式 SD 文案和既有录音功能无回归。

**不允许宣称**：
- 账号绑定端到端完成。
- Device Token 已由线上服务器签发。
- HTTPS 服务器和跨账号隔离已通过。

### 2026-07-31 19:10 — v0.4.0 持久离线补传设备端完成

**版本**：`0.4.0-dev.1`
**阶段变化**：PLANNED → IN_PROGRESS → BUILD_PASS / SERVER_BLOCKED

**设备端能力**：
- 遍历固定式 SD 上所有已闭合/已恢复会话，不再只跟踪 RAM 中最后一段录音。
- `upload.state` 原子持久化远端会话、分片序号、ACK 偏移、marks ACK、final ACK、
  重试次数和 HTTP 状态，并镜像到 `session.json`。
- create、160 KiB 音频分片、marks 和 final 各自使用稳定幂等键。
- 分片携带 client session、seq、offset、长度和 SHA-256；ACK 不精确匹配则不推进。
- 断网、超时、429 和 5xx 指数退避并加入抖动；401/403 清除失效 Token，保留录音。
- WiFi 获得 IP 与云 API/TLS 可用状态分离显示。
- 账号 binding generation 固化到新会话，旧账号积压不会自动转移给新账号。
- `done` 后保留 WAV、marks、manifest，不自动删除固定式 SD 数据。

**自动测试**：
- 状态机回归：通过（46 次渲染）。
- WAV/JSONL 恢复测试：通过。
- SoftAP 表单测试：通过。
- 上传协议测试：通过，覆盖整 160 KiB 边界、ACK 校验、幂等键、HTTP 分类与退避。
- provisioning/cloud-sync 静态门禁：通过。

**首次 ESP-IDF 构建**：
- ESP-IDF：`v5.5.4`
- target：`esp32s3`
- App：1,225,664 B
- App SHA-256：`8e6770e68396802250b7a80379fa09d8b9aad8c929d6d447c2b3e6952dbaa82b`
- factory 6 MiB 分区剩余约 81%。
- 该构建来自未提交工作树，只作为编译证据；发布包必须在 commit 后重新全量构建。

**外部阻塞**：
- `meeting.example.invalid` 尚未实现 `luoye-device-api/0.3-draft`。
- 当前不能完成 Device Token、账号隔离、服务端去重、断点续传和 final 的端到端验证。

**下一步**：
- 提交源码，执行 `dirty=0` 全量构建并生成 dev.1 FLASH/symbols 包。
- 真板先验证离线多段录音、复位恢复和本地队列；服务器完成后再做网络故障注入。

### 2026-07-31 19:12 — v0.4.0-dev.1 开发包冻结

**版本**：`0.4.0-dev.1`
**阶段变化**：BUILD_PASS / SERVER_BLOCKED → READY_TO_FLASH / SERVER_BLOCKED

**版本组合**：
- 源码 commit：`483931e6eac4e01446529c2b246381d1e6b3d8e3`
- annotated tag：`luoye-fw-v0.4.0-dev.1`
- API contract：`luoye-device-api/0.3-draft`
- build profile：`dev`
- manifest：`dirty=false`，target=`esp32s3`，Flash 文件数 `4`

**发布级全量构建**：
- ESP-IDF：`v5.5.4`
- App：1,225,664 B
- App SHA-256：`1e16cd37529f2ee3ef200d10e05f370f724ec7fdacb5ebd5e6f1d9e0c41e0ba0`
- factory 6 MiB 分区剩余约 81%。

**发布产物**：
- `releases\luoye-fw-v0.4.0-dev.1-flash.zip`
- Flash ZIP SHA-256：
  `30f3018acbe6268fac03f9605a7f12bc10ba67d1a0b373ec296b6cae0cf175df`
- `releases\luoye-fw-v0.4.0-dev.1-symbols.zip`
- Symbols ZIP SHA-256：
  `207d8cf5b5cdbd7914bef0db5dea7d94ac52392f1556835ce2d4b1450f0e24b2`

**结论**：
- 设备端固件可烧录并验证离线多会话、重启恢复和持久队列。
- 服务器 API 尚未实现，因此本状态不代表账号绑定、服务端去重或端到端补传已通过。
- 真板验收前不得标记 `BOARD_PASS`；服务器联调通过前不得标记 `ACCEPTED`。

### 2026-07-31 20:40 — v0.5.0 实时字幕、翻译和完整屏幕交互设备端完成

**版本**：`0.5.0-dev.1`
**阶段变化**：PLANNED → IN_PROGRESS → BUILD_PASS / SERVER_BLOCKED

**设备端能力**：
- 活动录音只从 SD 最近一次 `fsync` 边界读取，并只发送完整 160 KiB 分片；闭合后发送尾片。
- 轮询 `/live?after_revision=N`，严格校验 client/server session、revision 和连续 PCM 偏移。
- `result_revision`、`result_pcm_bytes` 原子持久化，断网恢复后从正确游标继续。
- 会议字幕与翻译原文/译文使用加锁 RAM 快照，正文不进入工程日志。
- 会议两页、翻译三页、充电页、真实空议程页、状态页、配网页、收尾页和错误页完成。
- 纯正文约 15 秒刷新，按键、暂停、结束、断网、配对和错误立即刷新。
- UI 不再使用 HTML 演示字幕；没有服务器结果时只显示等待、离线或本地保存事实。

**自动测试**：
- 状态机回归：通过（55 次渲染，含翻译三页循环）。
- 上传协议、实时游标/UTF-8/长度边界测试：通过。
- storage、provisioning、cloud-sync 与 live UI 静态门禁：通过。

**首次 ESP-IDF 构建**：
- ESP-IDF：`v5.5.4`
- target：`esp32s3`
- App：1,230,704 B
- App SHA-256：`40d0fed728c6b980f6f894fe26f5d96e7f6aa3458ed768e2bede5da82370d945`
- factory 6 MiB 分区剩余约 80%。
- 该构建来自未提交工作树，只作为编译证据；发布包必须在 commit 后重新全量构建。

**外部阻塞**：
- `meeting.example.invalid` 尚未实现 `luoye-device-api/0.4-draft`。
- 当前不能验证真实 Device Token、live revision、ASR/翻译、客户端活动会话和账号隔离。

**下一步**：
- 完成全部回归、提交源码，在 `dirty=0` 状态重新全量构建并冻结 dev.1 工程包。
- 服务器实现 0.4-draft 后执行断网、乱序 revision、偏移回退和双语一致性真板测试。

### 2026-07-31 20:08 — v0.5.0-dev.1 开发包冻结

**版本**：`0.5.0-dev.1`
**阶段变化**：BUILD_PASS → READY_TO_FLASH / SERVER_BLOCKED

**可追溯构建**：
- 源码 commit：`1f642c45b5cc64eedc2c736692464bec826c83b0`
- 构建时工作树：`dirty=false`
- API contract：`luoye-device-api/0.4-draft`
- ESP-IDF：`v5.5.4`，target `esp32s3`，profile `dev`
- 全量 clean build 与全部工程门禁：通过
- App：1,230,704 B
- App SHA-256：`46ebbdf3c0670186574925babb248a1618ba739613459553c06f5632240b5c33`

**发布产物**：
- `releases\luoye-fw-v0.5.0-dev.1-flash.zip`
  - SHA-256：`a1b48c982cc1fe0ce61b1fa79d3f8457af879c56f1d6266ba1ad38011c5482bf`
- `releases\luoye-fw-v0.5.0-dev.1-symbols.zip`
  - SHA-256：`ea6e48059f760be8466756e9c8ec77c114db15cd813154f69951b3fcaf035644`

**限制**：
- 包可烧录并验证设备 UI、录音与离线状态，但真实字幕/翻译仍依赖服务器实现 0.4-draft。
- 真板验收前不得标记 `BOARD_PASS`；服务端联调前不得标记 `ACCEPTED`。

### 2026-07-31 20:20 — v0.5.0-dev.2 全部刷新统一 FAST

**版本**：`0.5.0-dev.2`
**阶段变化**：READY_TO_FLASH → READY_TO_FLASH / SERVER_BLOCKED

- 所有 UI 实际渲染统一调用 SSD1680 厂商 FAST 波形 `0xC7`。
- 不再调用全刷 `0xF7` 或局刷 `0xFF`；`PART/FULL` 仅作为事件优先级标记保留。
- 适用于开机、配网、状态、录音、字幕、翻译、按键和收尾页面。
- 取舍：更新更快、无全刷闪烁；长时间运行残影风险增加，后续可由用户触发全刷维护。
- clean build、主机测试和静态门禁：通过。
- App：`0x12c590`（1,230,224 B）。
- FLASH SHA-256：`c525464e23b5ded1fb50c2ef6430ef24ec5eb435ef18547f751e81f8d6623e14`。

### 2026-07-31 23:26 — v0.6.0 议程、提醒和语音待办工程包冻结

**版本**：`0.6.0`
**阶段变化**：CODE_COMPLETE / SERVER_BLOCKED → READY_TO_FLASH / SERVER_BLOCKED

**设备端能力**：
- SNTP、系统 UTC 和 PCF8563 双向校时；RTC 闹钟调度最近提醒。
- revision/generation 议程同步、原子 SD 缓存、三页待机 UI 和提醒 REC/MARK/BACK 操作。
- MARK 最长 30 秒单声道语音待办；离线持久化、幂等上传、结果轮询和创建确认。
- 语音采集每 64 KiB 同步，异常重启修复 WAV 头并恢复待上传状态。
- 账号 binding generation 隔离；旧账号议程和待办不会进入新账号链路。
- 有提醒时使用 GPIO light sleep 等待 GPIO41，未设提醒时继续 deep sleep。

**可追溯构建**：
- 源码 commit：`a6541d018beb8335ee9ed01f23dc2858d6e61904`
- annotated tag：`luoye-fw-v0.6.0`
- 构建时工作树：`dirty=false`
- API contract：`luoye-device-api/0.5-draft`
- ESP-IDF：`v5.5.4`，target `esp32s3`，profile `rc`
- App：1,221,872 B，SHA-256：
  `9d35e710651f57be1b91d607c4ee96c537d604c0b7115d13b9e6ff99617d0a38`
- factory 6 MiB 分区剩余约 81%。

**自动门禁**：
- 状态机回归通过（72 次渲染）。
- WAV/JSONL 存储恢复、SoftAP 表单、上传协议、实时结果和议程协议测试全部通过。
- provisioning、cloud sync、live UI、agenda/todo 静态门禁全部通过。
- RC clean build、manifest/commit/版本/分区和 ZIP 解包复验通过。

**发布产物**：
- `releases\luoye-fw-v0.6.0-flash.zip`
  - SHA-256：`336ea7b9d94bb671bdfe484a0de086e99dc9ebdaa9bbffbcaf3fa8d9db3660b4`
- `releases\luoye-fw-v0.6.0-symbols.zip`
  - SHA-256：`76bd51d43add80311c3f9accbad57cedd83717a834cae7724d2fd89a63cb4728`

**限制**：
- 当前 `meeting.example.invalid` 尚未实现 0.5-draft，真实议程、ASR、时间解析和账号日历写入
  不能在本版本冻结时做端到端验证。
- 未烧录、未执行 PCF8563 到点唤醒和语音待办真板专项测试，因此不能标记 `BOARD_PASS`。

### 2026-08-01 01:38 — v0.6.1-cloud-v1 设备端 API v1 构建通过

**版本**：`0.6.1-cloud-v1`

**阶段变化**：`IN_PROGRESS → BUILD_PASS / API_V1_INTEGRATION`

**目标**：把设备端统一到 `luoye-device-api/1`，并冻结可供三端联调的协议实现。

**代码修改**：
- 服务端地址改为构建期配置；默认 `https://meeting.example.invalid`，明文 HTTP 仅允许
  `dev/engineering` 显式启用。
- 完成 build-info 兼容门禁、设备配对 start/status、同账号令牌轮换与结构化配对错误恢复。
- 完成 session/create、连续分片 ACK、mark、end、state、断网补传和幂等键 v1 契约。
- 完成议程与语音待办 v1 契约；待办截止时间允许 `null`。
- 普通对象 404 不再关闭全局云兼容门禁；只有 WiFi 或 build-info 门禁改变
  `cloud_ready`。
- 会话服务端状态冻结为 `uploading → processing → done|failed`；本地兼容读取历史
  `complete`，但新状态只写 `done`。

**自动测试**：
- 6 组主机测试通过：state、storage、provisioning、upload、live、agenda。
- 4 组静态门禁通过：provisioning、cloud sync、live UI、agenda/todo。
- `git diff --check` 通过。

**构建**：
- ESP-IDF：`v5.5.4`，target `esp32s3`，profile `dev`。
- 服务器 origin：`https://meeting.example.invalid`；`LUOYE_ALLOW_INSECURE_HTTP=OFF`。
- 全新目录：`build-api-v1-final`。
- App：1,274,288 B（`0x1371b0`），SHA-256：
  `a43353ef218c27790db17f176a4370654bf22857e13b4224c5dc89205c2adf74`。
- factory 6 MiB 分区剩余 `0x4c8e50`（80%）。

**边界**：
- 本次只形成设备端编译和契约门禁证据；没有打包、烧录、创建标签或发布。
- `BUILD_PASS` 不代表配对、上传、实时结果、议程和待办已经完成真服务器端到端验收。

每次工作追加一节，禁止覆盖旧记录：

```markdown
### YYYY-MM-DD HH:mm — 简短标题

**版本**：
**阶段变化**：IN_PROGRESS → CODE_COMPLETE
**目标**：
**证据等级**：线上探测确认 / 线上端到端确认 / 部署源码确认 / 本地旧源码参考 / 待确认

**版本组合**：
- 固件 commit / bin SHA-256：
- API contract 版本 / SHA-256：
- 服务器 commit / 镜像 digest / release ID：
- Web/App 版本：
- 数据库 migration：
- ASR / 翻译模型版本：

**代码修改**：
- 文件：
- 变更：

**自动测试**：
- 命令：
- 结果：

**构建**：
- ESP-IDF：
- Commit：
- App大小：
- SHA-256：

**烧录**：
- 设备编号：
- PCB版本：
- COM口：
- 结果：
- 串口日志：

**真板验收**：
- 通过：
- 失败：

**问题/风险**：
- ID：
- 复现：
- 决策：

**下一步**：
```

### 2026-08-04 17:25 — 1.54 寸最终 UI r2 接入

**版本**：`v0.7.0-ui154-r2`
**阶段变化**：IN_PROGRESS → BUILD_PASS
**目标**：将确认的 22 页 200×200 UI 布局接入 GDEY0154D67 固件，不改变录音、云端、按键和充电业务。

**代码修改**：
- `tools/gen_ui154_assets.py`：从无文字背景和最终 JSON 生成 22 个 1-bit 页面资源。
- `tools/gen_ui154_layout.py`：生成 130 个固件动态文字字段。
- `main/ui_render.c`：按布局字段绑定时间、电量、日程、字幕、录音、配网和待办数据。
- `main/ui_font.c`：支持按 JSON 像素字号缩放固件字库。

**自动测试**：
- BQ25186、议程待办、云同步、配网、实时字幕和 UI154 静态门禁通过。
- 22 个页面资源均为 5000 B，总计 110000 B。
- 固件字库真实预览：`docs/UI154_FIRMWARE_R2_PREVIEW.png`。

**构建**：
- ESP-IDF：v5.5.4-3
- Build：`build-154-ui`
- App：`0x12db20` B；factory 分区剩余 80%。

**边界**：
- 已完成编译和资源校验；仍需烧录后核对真屏文字细度、方向和 22 页状态切换。

### 2026-08-05 — SSD1681 深睡后差分 RAM 修复

**版本**：`v0.7.0-ui154-r2.1-epdfix`
**问题**：首帧后进入深睡，下一次 FAST 刷新没有重载旧帧 RAM2，导致屏幕显示随机噪点。
**修复**：ESP32 保存上一帧；每次唤醒后向 `0x26` 写入上一帧、向 `0x24` 写入当前帧，再执行 `0xC7` 快刷；BUSY 超时记为 `ESP_ERR_TIMEOUT`。
**验证**：UI154/BQ 静态门禁通过，ESP-IDF v5.5.4-3 编译通过，烧录包逐文件 SHA-256 校验通过。
**烧录包**：`luoye-fw-v0.7.0-ui154-r2.1-epdfix-flash.zip`。

### 2026-08-06 — 基于 r2.11 重做手动同步队列

**版本**：`v0.7.0-ui154-r2.11-syncqueue-r1`
**阶段变化**：SPEC_CONFIRMED → BUILD_PASS / READY_TO_FLASH

**实现**：
- 完整移除后续实验版的 32 KiB 分片、持久前台会话、固定服务器路由和 60 秒 idle light-sleep 策略，回到 r2.11 的黑白 FAST、160 KiB 分片与常规联网基线。
- 当前正在录制的会话仍在线实时上传并获取字幕；已结束历史录音不再自动抢占上传通道。
- 待机长按中间键进入同步确认页；短按中间键后按最早优先 FIFO 上传，BACK 可取消确认或返回主页。
- 云端 final ACK 持久化后立即原子删除对应本地目录；网页删除任意已闭合本地录音不再要求上传完成。
- 删除正在写入的会话会被设备拒绝，避免破坏 FAT/WAV；闭合后的任意上传阶段均可删除。

**验证**：
- ESP-IDF v5.5.4-3 `build-dev` 全量编译通过；最终 App `0x12e280` B，6 MiB 应用分区剩余 80%。
- 状态机、存储格式、上传协议、实时结果、议程和配网 6 组主机测试通过。
- UI154、cloud sync、live UI、agenda/todo 和 manual-sync/FIFO/delete 静态门禁通过。
- ClearMeeting 设备 API 16 项测试和网页 5 项测试通过，网页生产构建通过。
- 固件烧录包：`luoye-fw-v0.7.0-ui154-r2.11-syncqueue-r1-flash.zip`。
- 配网 `LUOYE-XXXX` SoftAP 改为开放网络；墨水屏显示“无需密码”，目标 WiFi 自身的密码仍按网络实际情况填写。

**真板待验**：
- 中间键确认/取消、两场历史录音 FIFO 顺序、final ACK 后 SD 目录消失。
- 云端删除未上传/上传中/已上传的已闭合会话，以及断网和重启后的幂等恢复。

### 2026-08-07 — v0.8.0 单网络调度器与 API/2

**版本**：`v0.8.0-engineering-api2-r1`
**阶段变化**：SPEC_CONFIRMED → BUILD_PASS / READY_TO_FLASH

**实现**：
- 所有已认证云业务收敛到一个网络调度任务；在线录音、收尾、手动历史同步、
  待办、议程和存储命令按状态门禁与优先级运行。
- 在线音频保持 160 KiB；完全离线和断网补洞采用 10 MiB 逻辑范围，以 64 KiB
  RAM 缓冲流式发送，不提供 2 MiB 降级。
- `upload.state` 持久化 `live/bulk/repair` 与服务器确认进度；缺口补齐、MARK 成功、
  complete 最终 ACK 后才删除 SD 历史副本。
- 网页删除不完整上传时先取消远端临时会话；录音中的删除延迟到安全收尾。
- 录音和收尾禁止休眠；已安全闭合的离线队列在联网失败 60 秒后可持久休眠。

**自动验证**：
- ESP-IDF v5.5.4 工程构建成功，应用镜像约 1.19 MiB，应用分区剩余约 80%。
- 固件主机测试和静态门禁全部通过。
- ClearMeeting 79 项服务器测试、6 项真实 HTTP API/2 联调、5 项网页测试和生产
  构建通过。

**真板待验**：
- 在线 160 KiB、纯离线 10 MiB、中途断网补洞与重启续传。
- 云端删除、完成 ACK 后 SD 删除、字幕时延、60 秒休眠及按键唤醒。

### 2026-08-10 — v0.9.0 三功能键交互基线

**版本**：`v0.9.0-engineering-three-key-r1`
**阶段变化**：SPEC_CONFIRMED → BUILD_PASS / READY_TO_FLASH

**实现**：
- 录音键：短按录音/暂停/继续，录音中长按安全结束，待机长按进入历史同步。
- 待办键：待机短按进入并循环翻阅日程，长按开始待办、松开结束；确认页短按确认；录音中短按保留 MARK。
- 设置键：待机短按设备状态/返回，日程页短按返回主页，长按配网；录音中保留状态切换与锁定。
- 日程改为每页两条、时间一行加内容两行，显示当前页/总页数；修复旧选择器可能重复第一条的问题。
- 只合并用户批准的 `02_agenda` 页面，其余 21 页继续沿用已验证布局。

**已通过**：
- 状态机 PC 单元测试。
- UI154、agenda/todo、manual-sync 静态门禁。

**构建与发布**：
- ESP-IDF v5.5.4 全新构建通过；应用镜像 `0x1315b0` B，6 MiB 应用分区剩余 80%。
- 22 页 UI、SimSun 单色点阵字库和 assets 分区打包通过。
- 烧录包：`luoye-fw-v0.9.0-engineering-three-key-r1-flash.zip`。
- Flash ZIP SHA-256：`bea517726f965d7beda2af99e8c8d382004cb1fcff46083f9ce4850855cb7454`。

**待完成**：
- 真板验证三键短按/长按、待办松手收尾、日程循环分页和录音 MARK/锁定。

### 2026-08-11 — v0.9.1 双麦远场与 Wi-Fi 唤醒恢复

**版本**：`v0.9.1-engineering-dualmic-wifi-r2`
**阶段变化**：`SPEC_CONFIRMED → BUILD_PASS / READY_TO_FLASH`

**实现**：
- 将双麦 A/B r3 前端接入正式会议 WAV 与语音待办：20 ms 帧、左右灵敏度平衡、±2 sample TDOA、分数延时叠加、高通、连续语音增益与软限幅。
- 保留正式驱动的左右声道诊断旁路；远场算法不改变 PDM 引脚、采样率、WAV 格式和 SD 写入协议。
- Wi-Fi 待机恢复改为异步三态：休眠、恢复中、取得 IP；只有 `IP_EVENT_STA_GOT_IP` 才清除休眠标志。
- 启动、扫描或连接失败每 5 秒重新扫描最多 8 个已保存 Wi-Fi；增加 connecting 门闩，禁止 `STA_START` 重复通知打断正在建立的连接。
- 本地录音不依赖云端恢复；录音、收尾、手动同步及正在执行的云请求均禁止再次进入休眠。

**验证**：
- ESP-IDF v5.5.4 全量构建及 connecting 门闩增量构建通过；应用镜像 `0x132c40` B，6 MiB 应用分区剩余 80%。
- 状态机 94 次渲染、WAV/断电恢复、配网、上传、实时结果、议程协议主机测试全部通过。
- provisioning、cloud-sync、agenda/todo、manual-sync/FIFO/delete、idle/light-sleep 静态门禁全部通过。
- 最终烧录包：`luoye-fw-v0.9.1-engineering-dualmic-wifi-r2-flash.zip`。
- Flash ZIP SHA-256：`64ef396c903466fab862db263eb0229a3881c53016294f2eeb796d8bb3912c22`。

**真板待验**：
- 60 秒待机后按 REC/MARK/BACK，确认 30 秒内依次出现 `resume_requested`、`radio_started`、`resumed result=ESP_OK`、`LY|WIFI`、`LY|CLOUD|ready=1`。
- 分别录制 0.5 m 与 3–5 m 人声，核对 `LY|AUDIO_FRONTEND|state=calibrated/stopped`、文件清晰度、底噪和削波。

### 2026-08-13 — v0.9.4 语义章节纪要与分钟刷新

**版本**：`v0.9.4-engineering-semantic-timeline-r1`
**阶段变化**：`SPEC_CONFIRMED → BUILD_PASS / READY_TO_FLASH`

**实现**：
- 保留 v0.9.0 已确认的前 22 页，仅追加用户批准的第 23 页“本段纪要”；布局与素材
  SHA-256 均为 `8d6c8fa9d1c442b38a5416d8e6ceedf99d39ea836e7cb36ecde41574a354b5ba`。
- 页面显示本段起始时间、章节标题及两条动态要点；没有云端章节时继续使用字幕页，不阻断录音。
- 录音开始立即显示首帧；之后章节/字幕仅在自然分钟边界使用 SSD1681 FAST 刷新。
- 网络轮询和章节缓存继续后台运行；网络、云端及 SD 状态变化不会绕过分钟显示闸门。
- 暂停、继续、结束、错误及用户按键仍即时刷新。
- 接口保持 `luoye-device-api/2`，配套 ClearMeeting 服务器版本为 `0.19.0`。

**验证与发布**：
- UI154、实时 UI、配网、云同步、议程/待办、手动同步、休眠/EPD 静态门禁全部通过。
- 状态机 94 次渲染以及字幕、议程、存储、上传、配网协议测试全部通过。
- ESP-IDF v5.5.4 完整构建成功；应用镜像 `0x133ac0` B，6 MiB 应用分区剩余 80%。
- 烧录包：`luoye-fw-v0.9.4-engineering-semantic-timeline-r1-flash.zip`。
- Flash ZIP SHA-256：`c307ebbb8d8541a259e517b56c7749ce5ab248bf0c46a0eea56c2235a1f5a180`。

**真板待验**：
- 烧录后核对第 23 页方向、字体、两条要点和 FAST 波形。
- 录音跨越两个自然分钟，确认每分钟最多一次章节页自动刷新，暂停/结束仍立即变化。
- 同一议题持续讨论与明确切换议题各测试一次，确认章节数由语义变化决定，而不是固定时间决定。

### 2026-08-14 — v0.9.5 字幕/时间轴双视图与季度刷新

**版本**：`v0.9.5-engineering-caption-timeline-r1`
**阶段变化**：`SPEC_CONFIRMED → BUILD_PASS / READY_TO_FLASH`

**实现**：
- 恢复独立实时字幕页；字幕使用 18px 宋体单色点阵、24px 行距，最多显示 6 行。
- 每场新会议默认进入实时字幕；录音中长按待办键可切换实时字幕和时间戳纪要。
- 当前显示选择在暂停、锁定和录音状态页之间保持；结束后新开会议自动回到实时字幕。
- 录音中短按待办键继续写入 MARK，短按设置键继续切换录音主显示和状态页，其他页面操作不变。
- 时间戳纪要改为字幕式排版，显示章节时间范围、18px 标题及两条动态要点。
- 活跃录音主显示在自然时钟 `:15`、`:30`、`:45` 使用黑白 FAST 刷新，在 `:00` 执行一次黑白 FULL 清屏；暂停、结束和用户切页仍即时响应。
- 接口保持 `luoye-device-api/2`，配套 ClearMeeting 服务器版本仍为 `0.19.0`。

**验证**：
- 状态机 98 次渲染回归通过，覆盖长按切换、暂停/锁定保持、MARK 与新会议复位。
- UI154、实时 UI、配网、云同步、议程/待办、手动同步、休眠/EPD 静态门禁全部通过。
- 字幕、议程、存储、上传、配网协议测试全部通过。
- ESP-IDF v5.5.4 完整构建成功；应用镜像 `1261056` B。
- 烧录包：`luoye-fw-v0.9.5-engineering-caption-timeline-r1-flash.zip`。
- Flash ZIP SHA-256：`65b904bd7806ed523b8c15bf71396d80b5a3116a7eb8f80352e12031c0abdaea`。

**真板待验**：
- 新会议确认默认字幕；录音中长按待办键反复切换字幕/时间戳纪要。
- 切换后依次测试暂停、锁定、状态页往返，确认所选视图不丢失；新会议确认回到字幕。
- 跨越自然分钟观察 `:15/:30/:45` FAST 与 `:00` FULL，确认无额外周期刷新。

### 2026-08-14 — v0.9.6 SSD1681 真局部窗口刷新

**版本**：`v0.9.6-engineering-caption-timeline-partial-r1`
**阶段变化**：`v0.9.5 FAST 代替局刷 → BUILD_PASS / READY_TO_FLASH`

**实现**：
- 新增 SSD1681 原厂 `0xFF` PARTIAL 更新路径和逻辑坐标到屏幕 RAM 坐标的旋转/镜像换算。
- PARTIAL 只设置并写入录音主页面动态区域 `(4,8)-(195,178)`，不会再调用全屏 FAST 冒充局刷。
- FULL 与 FAST 后同步 SSD1681 RAM `0x26` 基准，避免随后的局部差分刷新花屏。
- `:15/:30/:45` 使用窗口 PARTIAL；`:00` 保持 FULL 清残影；用户切页仍保持全屏 FAST。
- v0.9.5 烧录包由本版本替代，不再作为真板测试候选。

**验证**：
- 状态机 98 次渲染以及 UI154、实时 UI、议程/待办和配网静态门禁通过。
- ESP-IDF v5.5.4 完整构建成功；应用镜像 `0x134160` B，应用分区剩余 80%。
- 烧录包：`luoye-fw-v0.9.6-engineering-caption-timeline-partial-r1-flash.zip`。
- Flash ZIP SHA-256：`03d7c8559b7b6425ae950c0ba67f62ca18c207c9097d0e198370226a9dce2ff0`。

### 2026-08-14 — v0.9.8 五秒局刷与两分钟 FAST

**版本**：`v0.9.8-engineering-partial5s-fast2m-r1`
**阶段变化**：`SPEC_CONFIRMED → BUILD_PASS / READY_TO_FLASH`

**实现**：
- 延续 v0.9.7 的时间戳纪要字库修正，标题、项目符号和两条要点均使用完整的 16px SimSun 点阵字库。
- 录音字幕页和时间戳纪要页在自然时钟每 5 秒执行一次 SSD1681 真窗口 PARTIAL。
- 每 2 分钟执行一次全屏黑白 FAST，用于统一屏幕基准并抑制局刷残影。
- 删除所有运行期周期 FULL；页面切换、暂停、继续、结束和错误状态均使用 FAST。
- 仅屏幕上电后的首帧保留一次 FULL，以建立 SSD1681 差分刷新所需的基准 RAM。

**验证与发布**：
- 状态机 98 次渲染以及存储、上传、配网、实时字幕/纪要和议程协议测试全部通过。
- UI154、实时 UI、云同步、手动同步和休眠/EPD 静态门禁全部通过。
- ESP-IDF v5.5.4 完整构建成功；应用镜像 `0x134180` B，6 MiB 应用分区剩余 80%。
- 烧录包：`luoye-fw-v0.9.8-engineering-partial5s-fast2m-r1-flash.zip`。
- Flash ZIP SHA-256：`f90c604e3d0cef63e39be2147f71bb5abeb53216a7dffa783204de19950e48f9`。

### 2026-08-14 — v0.9.9 时间戳纪要字体修正

**版本**：`v0.9.9-engineering-timeline-font-r1`
**阶段变化**：`BUG_CONFIRMED → BUILD_PASS / READY_TO_FLASH`

**实现**：
- 章节大标题固定使用 18px SimSun 完整点阵字库。
- 顶部标签统一为“时间戳纪要”，从 12px 精简字库切换到 16px 完整字库。
- 16px 字库已确认包含 `U+6233 戳`，不再使用缺字方框代替。
- 保留 v0.9.8 的每 5 秒窗口 PARTIAL、每 2 分钟全屏 FAST 策略。

**验证与发布**：
- 时间戳字体门禁、UI154 静态检查和状态机 98 次渲染回归通过。
- ESP-IDF v5.5.4 完整构建成功；应用镜像 `0x134180` B。
- 烧录包：`luoye-fw-v0.9.9-engineering-timeline-font-r1-flash.zip`。
- Flash ZIP SHA-256：`eb4995241ab5b76e63891bd46ccc08600598a7d6995ae7d05c594db3aced699a`。

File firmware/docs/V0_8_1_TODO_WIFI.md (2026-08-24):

# 落叶 v0.8.1 待办与多 Wi-Fi 工程版

配套服务器：ClearMeeting v0.14.1；设备协议保持 `luoye-device-api/2`。

## 本版变化

- 主页将下一条待办拆为时间一行、内容最多两行；无时间待办显示“未定时间”。
- 议程协议增加 `has_time`，无时间待办不再被丢弃，也不会触发 RTC 提醒。
- 最多保存 8 个历史 Wi-Fi；启动、唤醒和掉线重连时扫描当前环境，在已保存网络中
  选择信号最强者。连接失败时下一轮会尝试其他可见的已保存网络。
- 兼容旧版单 SSID NVS 数据；第一次升级无需重新配网。

## 真板验收

1. 确认主页时间独占一行，长事项能换为两行且不越过屏幕底边。
2. 分别确认有时间和无时间待办都能保存、同步、显示。
3. 配置两个热点后重启，关闭最近配置热点，确认自动连接另一已保存热点。
4. 串口检查 `LY|WIFI_SELECT|saved=... matched=... selected=...`，日志不应包含密码。

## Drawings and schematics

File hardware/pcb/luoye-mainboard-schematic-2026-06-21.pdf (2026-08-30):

# I2C_SDA I2C_SDA

# BQ_INT_N I2C_SCL

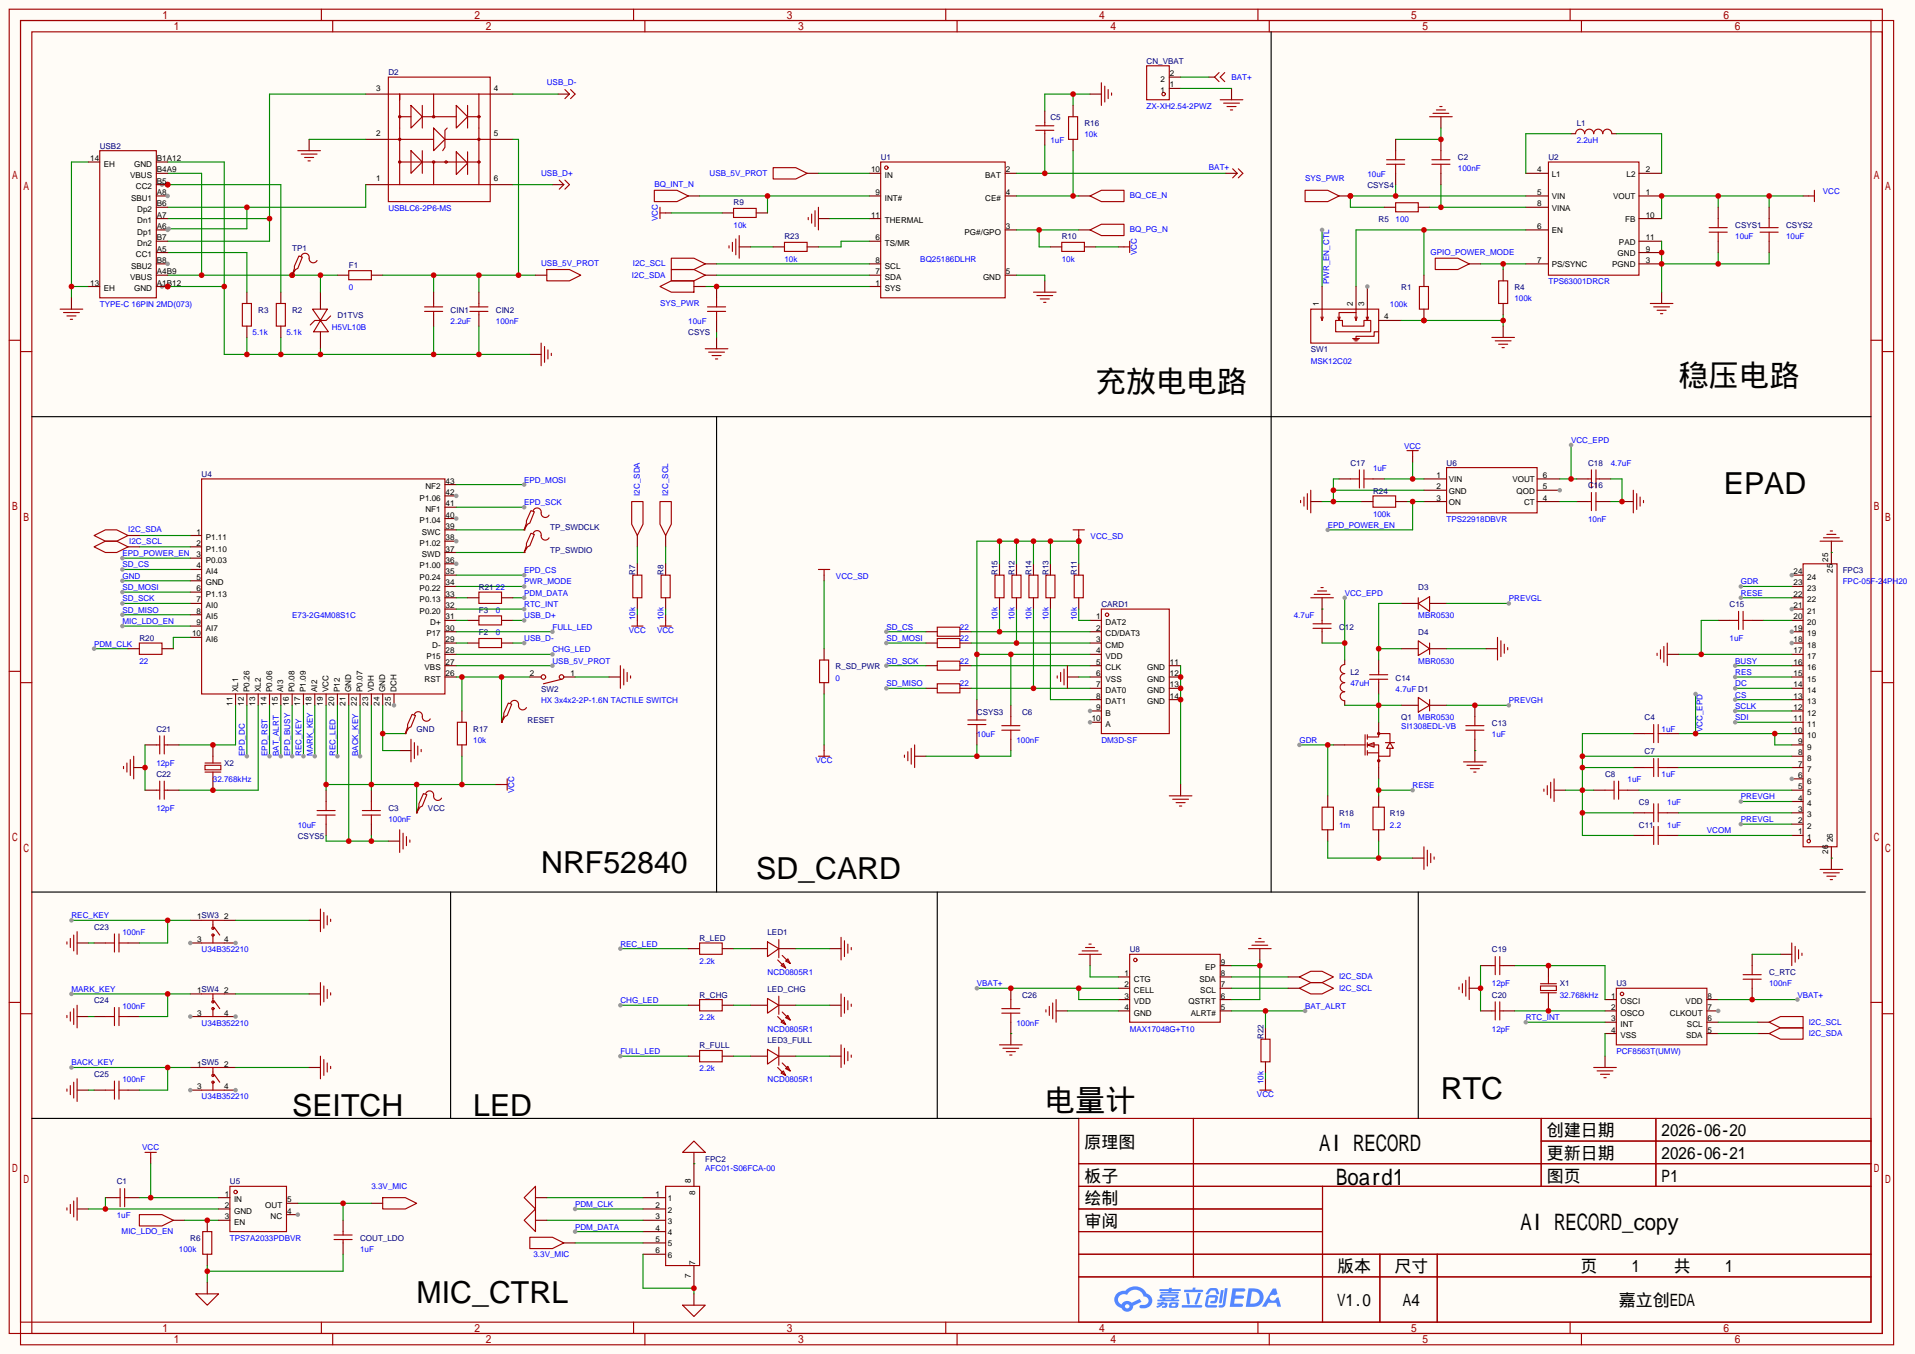
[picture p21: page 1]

USB2
GND A1B12 VBUS A4B9 SBU2 B8 CC1 A5 Dn2 B7 Dp1 A6 Dn1 A7 Dp2 B6 SBU1 A8 CC2 B5 VBUS B4A9 GND B1A12 EH 14

EPD_MOSI
RST 26 VBS 27 P15 28 D- 29 P17 30 D+ 31 P0.20 32 P0.13 33 P0.22 34 P0.24 35 P1.00 36 SWD 37 P1.02 38 SWC 39 P1.04 40 NF1 41 P1.06 42 NF2 43

更新日期 | 2026-06-21

板子 | Board1 | 图页 | P1
绘制 | | AI RECORD_copy
审阅

V1.0 | A4 | 嘉立创EDA

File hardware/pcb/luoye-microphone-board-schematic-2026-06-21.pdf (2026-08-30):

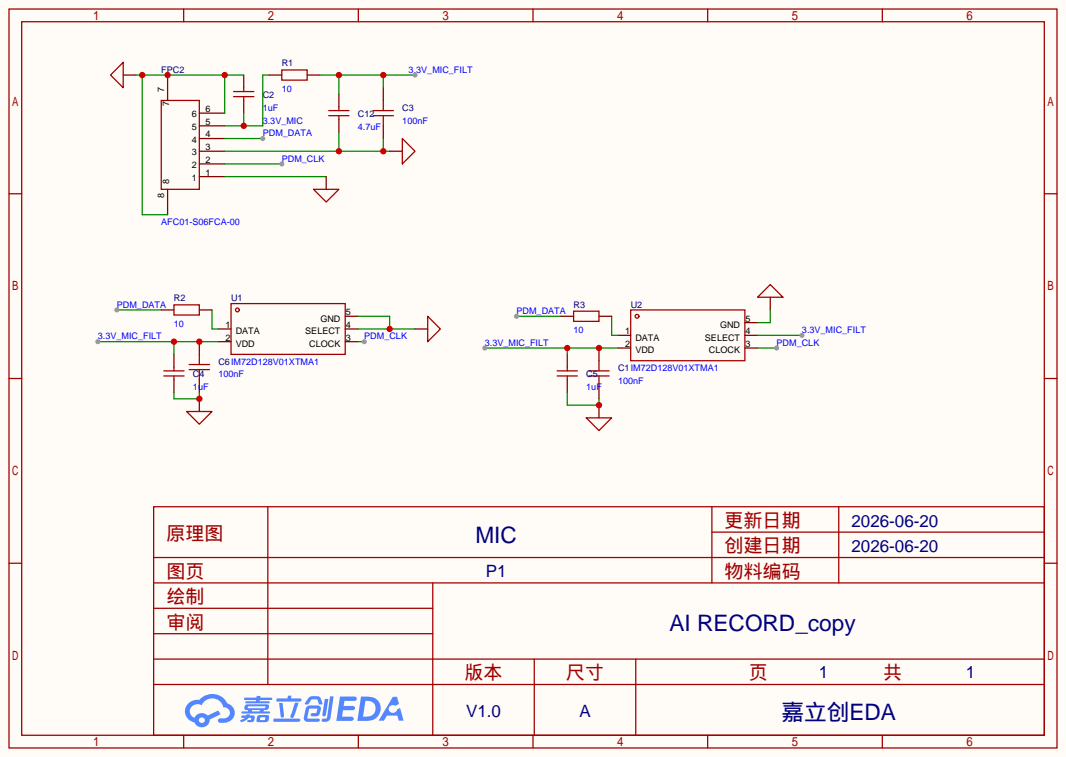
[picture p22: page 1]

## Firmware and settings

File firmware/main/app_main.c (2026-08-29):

// app_main.c — 装配层:状态机(app_state)是唯一决策者,这里把它的副作用回调
// 接到 EPD/音频/SD/网络/电源各子系统,并提供单一事件队列(所有事件串行进状态机)。
//
// 任务全景:
//   keys(10ms 轮询) ─┐
//   power_poll(5s)  ─┼→ [app 事件队列] → app_task → app_state → hooks
//   uploader(3s)    ─┘                                   │
//   audio_cap(核1,prio18) → StreamBuffer → sd_writer(核0,prio15)
//   ui(渲染,prio6) ← ui_request_render        led(50ms 花样)
#include <stdio.h>
#include <stdlib.h>
#include <string.h>
#include <sys/time.h>
#include <time.h>
#include "freertos/FreeRTOS.h"
#include "freertos/task.h"
#include "freertos/queue.h"
#include "nvs_flash.h"
#include "esp_timer.h"
#include "esp_sleep.h"
#include "esp_log.h"
#include "driver/gpio.h"
#include "driver/rtc_io.h"

#include "board_pins.h"
#include "app_state.h"
#include "input_keys.h"
#include "led_ctrl.h"
#include "ui_render.h"
#include "epd_ssd1681.h"
#include "audio_pdm.h"
#include "storage_sd.h"
#include "net_uploader.h"
#include "power_mgr.h"
#include "agenda_todo.h"
#include "luoye_build_info.h"
#include "luoye_diag.h"

static const char *TAG = "luoye";

// ---------- 事件队列 ----------
typedef struct { app_event_t ev; int32_t arg; } app_msg_t;
static QueueHandle_t s_q;
static bool s_ui_ready;
static bool s_audio_ready;
static bool s_todo_started_audio;

#define IDLE_SLEEP_AFTER_MS 60000
#define IDLE_WAKE_FALLBACK_US (60ULL * 1000000ULL)
#define IDLE_AGENDA_MAINTENANCE_MS 30000
#define IDLE_AGENDA_STOP_GRACE_MS 22000

static bool event_is_critical(app_event_t ev) {
  return ev == APP_EV_TIMER || ev == APP_EV_RTC_ALARM ||
         ev == APP_EV_TODO_RESULT ||
         ev == APP_EV_SESSION_CLOSE_DONE || ev == APP_EV_SESSION_SETTLED ||
         ev == APP_EV_STORAGE_ERROR;
}

static bool event_must_arrive(app_event_t ev) {
  return ev == APP_EV_SESSION_CLOSE_DONE || ev == APP_EV_SESSION_SETTLED ||
         ev == APP_EV_STORAGE_ERROR;
}

static void app_post(app_event_t ev, int32_t arg) {
  app_msg_t m = {ev, arg};
  if (!s_q) {
    luoye_diag_note_event_drop((int32_t)ev, "queue_not_ready");
    return;
  }
  TickType_t wait = event_must_arrive(ev)
                      ? portMAX_DELAY
                      : (event_is_critical(ev) ? pdMS_TO_TICKS(250) : 0);
  if (xQueueSend(s_q, &m, wait) != pdPASS) {
    luoye_diag_note_event_drop((int32_t)ev, "queue_full");
  }
}

static void log_main_stack(const char *stage) {
  UBaseType_t free_units = uxTaskGetStackHighWaterMark(NULL);
  ESP_LOGI(TAG, "LY|STACK|task=main stage=%s free=%u unit_bytes=%u",
           stage, (unsigned)free_units, (unsigned)sizeof(StackType_t));
}

// ---------- 状态机定时器(esp_timer 单次,回调只投递事件) ----------
static esp_timer_handle_t s_timers[APP_TIMER_COUNT];
static void timer_cb(void *arg) { app_post(APP_EV_TIMER, (int32_t)(intptr_t)arg); }
static void hook_set_timer(app_timer_id_t id, uint32_t ms) {
  esp_timer_stop(s_timers[id]);
  esp_timer_start_once(s_timers[id], (uint64_t)ms * 1000);
}
static void hook_cancel_timer(app_timer_id_t id) { esp_timer_stop(s_timers[id]); }

// ---------- 录音会话 hooks ----------
// 只有四个会话文件均已同步、麦克风成功启动后才进入 RECORDING。
static app_error_t hook_start_recording(app_scene_t scene, const char *title) {
  if (!storage_sd_mounted()) {
    ESP_LOGE(TAG, "LY|REC|action=start result=failed subsystem=storage reason=no_sd");
    return APP_ERR_NO_SD;
  }
  if (!s_audio_ready) {
    ESP_LOGE(TAG, "LY|REC|action=start result=failed subsystem=audio reason=not_initialized");
    return APP_ERR_MIC;
  }
  char sid[48];
  esp_err_t id_err = sd_session_generate_id(sid, sizeof(sid));
  if (id_err != ESP_OK) {
    ESP_LOGE(TAG, "LY|REC|action=start result=failed subsystem=nvs esp=%s",
             esp_err_to_name(id_err));
    return APP_ERR_STORAGE_OPEN;
  }
  power_set_low_noise(true);                 // TPS63001 强制 PWM,压住录音底噪
  esp_err_t audio_err = audio_pdm_start();
  if (audio_err != ESP_OK) {
    ESP_LOGE(TAG, "LY|REC|action=start result=failed subsystem=audio esp=%s",
             esp_err_to_name(audio_err));
    power_set_low_noise(false);
    return APP_ERR_MIC;
  }
  app_error_t storage_result = sd_session_open(sid, scene, title);
  if (storage_result != APP_ERR_NONE) {
    ESP_LOGE(TAG, "LY|REC|action=start result=failed subsystem=storage code=%d",
             (int)storage_result);
    audio_pdm_stop();
    power_set_low_noise(false);
    return storage_result;
  }
  net_session_begin(sid, scene, title);
  // Do not print meeting titles or transcript content to the engineering log.
  ESP_LOGI(TAG, "LY|REC|action=start result=ok session=%s scene=%d", sid, scene);
  return APP_ERR_NONE;
}

static void hook_stop_recording(app_close_reason_t reason) {
  ESP_LOGI(TAG, "LY|REC|action=stop phase=drain reason=%d", (int)reason);
  audio_pdm_stop();
  sd_session_request_close(reason);           // 排空后闭合;完成事件驱动“已保存”页面
  power_set_low_noise(false);
}

static app_error_t hook_recording_close_status(void) {
  app_error_t status = sd_session_close_status();
  ESP_LOGW(TAG, "LY|REC|phase=close_poll status=%d", (int)status);
  return status;
}

static void hook_mark_point(app_mark_kind_t kind, int64_t at_ms) {
  static const char *K[] = {"important", "fav", "todo"};
  esp_err_t error = sd_session_mark(K[kind], at_ms);
  ESP_LOGI(TAG, "LY|MARK|kind=%s at_ms=%lld result=%s", K[kind],
           (long long)at_ms, esp_err_to_name(error));
}

static bool hook_todo_start(void) {
  if (!s_audio_ready || !storage_sd_mounted() || todo_capture_active()) return false;
  char todo_id[LUOYE_TODO_ID_BYTES];
  if (todo_generate_id(todo_id, sizeof(todo_id)) != ESP_OK) return false;
  s_todo_started_audio = !sd_session_is_open();
  if (s_todo_started_audio) {
    power_set_low_noise(true);
    if (audio_pdm_start() != ESP_OK) {
      power_set_low_noise(false);
      s_todo_started_audio = false;
      return false;
    }
  }
  uint32_t generation = net_binding_generation();
  esp_err_t result = todo_capture_begin(todo_id, generation);
  if (result != ESP_OK && s_todo_started_audio) {
    audio_pdm_stop();
    power_set_low_noise(false);
    s_todo_started_audio = false;
  }
  if (result == ESP_OK) {
    ESP_LOGI(TAG, "LY|TODO|event=capture_start id=%s binding=%lu",
             todo_id, (unsigned long)generation);
  }
  return result == ESP_OK;
}

static bool hook_todo_end(bool saved) {
  luoye_todo_item_t item;
  esp_err_t result = todo_capture_end(saved, &item);
  if (s_todo_started_audio) {
    audio_pdm_stop();
    power_set_low_noise(false);
    s_todo_started_audio = false;
  }
  ESP_LOGI(TAG, "LY|TODO|event=capture_end id=%s pcm=%lu result=%s",
           item.id, (unsigned long)item.pcm_bytes, esp_err_to_name(result));
  return result == ESP_OK;
}

static bool hook_todo_action(bool confirm) {
  esp_err_t result = todo_request_action(net_binding_generation(), confirm);
  ESP_LOGI(TAG, "LY|TODO|event=user_action action=%s result=%s",
           confirm ? "confirm" : "cancel", esp_err_to_name(result));
  return result == ESP_OK;
}

static bool hook_sync_request(void) {
  bool accepted = net_request_manual_sync();
  ESP_LOGI(TAG, "LY|SYNC|event=user_request accepted=%d", accepted);
  return accepted;
}

static bool hook_agenda_sync_request(void) {
  bool accepted = net_request_agenda_sync();
  ESP_LOGI(TAG, "LY|AGENDA|event=page_request accepted=%d", accepted);
  return accepted;
}

static void hook_reminder_action(app_reminder_action_t action) {
  luoye_reminder_action_t mapped = action == APP_REMINDER_SNOOZE
                                     ? LUOYE_REMINDER_SNOOZE
                                     : (action == APP_REMINDER_START_MEETING
                                          ? LUOYE_REMINDER_START_MEETING
                                          : LUOYE_REMINDER_DISMISS);
  agenda_reminder_action(mapped, action == APP_REMINDER_SNOOZE ? 10 : 0);
}

static void hook_power_on(void) {
  if (s_ui_ready) epd_power(true);
  led_ctrl_self_test();
}

static void hook_power_off(void) {
  if (s_ui_ready) {
    ui_wait_idle(6000);                      // 等「已关机」页画完
    epd_deep_sleep();
    epd_power(false);
  }
  power_enter_off();                         // 无提醒不返回;有提醒时仅 RTC/长按 REC 返回
  if (gpio_get_level(PIN_RTC_INT) == 0) {
    rtc_clear_alarm();
    app_post(APP_EV_RTC_ALARM, 0);
  }
  // REC 长按由仍在运行的 keys 任务投递，不能在这里重复投递。
}

static void hook_snooze(void) { rtc_snooze_minutes(10); }
static int64_t hook_now_ms(void) { return esp_timer_get_time() / 1000; }

// ---------- 深睡唤醒:长按 REC 3s 才真正开机(模拟器语义) ----------
static void check_power_on_gate(void) {
  // 深睡前按键被切到 RTC mux(power_enter_off),唤醒后必须归还数字 GPIO,
  // 否则 gpio_get_level 读不到 → 三键失灵。非深睡启动时 deinit 也无害。
  const int keys[] = {PIN_KEY_REC, PIN_KEY_MARK, PIN_KEY_BACK};
  for (size_t i = 0; i < sizeof(keys) / sizeof(keys[0]); i++) rtc_gpio_deinit(keys[i]);

  if (esp_sleep_get_wakeup_cause() != ESP_SLEEP_WAKEUP_EXT1) return;   // 正常上电/复位直接开机
  ESP_LOGI(TAG, "LY|POWER_GATE|wake=EXT1 action=wait_rec_hold hold_ms=3000");
  gpio_config_t cfg = {
    .pin_bit_mask = 1ULL << PIN_KEY_REC,
    .mode = GPIO_MODE_INPUT,
    .pull_up_en = GPIO_PULLUP_ENABLE,
  };
  gpio_config(&cfg);
  for (int i = 0; i < 300; i++) {            // 需持续按住 3s
    if (gpio_get_level(PIN_KEY_REC) != 0) {  // 提前松开 → 回深睡
      ESP_LOGI(TAG, "LY|POWER_GATE|result=rejected action=deep_sleep");
      const uint64_t mask = (1ULL << PIN_KEY_REC) | (1ULL << PIN_KEY_MARK) | (1ULL << PIN_KEY_BACK);
      esp_sleep_enable_ext1_wakeup(mask, ESP_EXT1_WAKEUP_ANY_LOW);
      esp_deep_sleep_start();
    }
    vTaskDelay(pdMS_TO_TICKS(10));
  }
  ESP_LOGI(TAG, "LY|POWER_GATE|result=accepted action=boot");
}

static bool event_is_user_activity(app_event_t event) {
  return event == APP_EV_KEY_REC_SHORT || event == APP_EV_KEY_MARK_SHORT ||
         event == APP_EV_KEY_BACK_SHORT || event == APP_EV_KEY_REC_LONG ||
         event == APP_EV_KEY_REC_RELEASE || event == APP_EV_KEY_BACK_LONG ||
         event == APP_EV_KEY_MARK_HOLD || event == APP_EV_KEY_MARK_RELEASE;
}

static bool idle_sleep_allowed(void) {
  const app_state_t *state = app_state_get();
  return state && state->mode == APP_MODE_STANDBY &&
         (state->overlay == APP_OV_NONE ||
          state->overlay == APP_OV_REMINDER) && !state->locked &&
         state->sync != APP_SYNC_RUNNING &&
         !sd_session_is_open() && !todo_capture_active() && net_can_idle();
}

static uint64_t idle_next_minute_us(void) {
  rtc_time_t value;
  if (rtc_get_time(&value) == ESP_OK && value.sec >= 0 && value.sec <= 59) {
    int seconds = 60 - value.sec;
    if (seconds < 1 || seconds > 60) seconds = 60;
    return (uint64_t)seconds * 1000000ULL;
  }
  return IDLE_WAKE_FALLBACK_US;
}

static bool idle_key_is_down(void) {
  return gpio_get_level(PIN_KEY_REC) == 0 ||
         gpio_get_level(PIN_KEY_MARK) == 0 ||
         gpio_get_level(PIN_KEY_BACK) == 0;
}

static void idle_disable_gpio_wake(void) {
  const int wake_pins[] = {
    PIN_KEY_REC, PIN_KEY_MARK, PIN_KEY_BACK, PIN_RTC_INT,
  };
  for (size_t i = 0; i < sizeof(wake_pins) / sizeof(wake_pins[0]); ++i) {
    gpio_wakeup_disable(wake_pins[i]);
  }
  esp_sleep_disable_wakeup_source(ESP_SLEEP_WAKEUP_GPIO);
  esp_sleep_disable_wakeup_source(ESP_SLEEP_WAKEUP_TIMER);
}

static bool idle_half_hour(void) {
  time_t now = time(NULL);
  struct tm utc = {0};
  return now >= 1577836800 && gmtime_r(&now, &utc) &&
         (utc.tm_min % 30) == 0;
}

static bool idle_top_of_hour(void) {
  time_t now = time(NULL);
  struct tm utc = {0};
  return now >= 1577836800 && gmtime_r(&now, &utc) && utc.tm_min == 0;
}

static bool idle_ten_minute(void) {
  time_t now = time(NULL);
  struct tm utc = {0};
  return now >= 1577836800 && gmtime_r(&now, &utc) &&
         (utc.tm_min % 10) == 0;
}

static bool idle_stop_agenda_maintenance(void) {
  int64_t deadline = esp_timer_get_time() / 1000 +
                     IDLE_AGENDA_STOP_GRACE_MS;
  esp_err_t error;
  do {
    error = net_idle_agenda_maintenance_stop();
    if (error == ESP_OK) return true;
    vTaskDelay(pdMS_TO_TICKS(50));
  } while (esp_timer_get_time() / 1000 < deadline);
  ESP_LOGW(TAG, "LY|IDLE_AGENDA|state=stop_timeout action=full_resume");
  net_idle_resume();
  return false;
}

/* Returns true only for a full/user wake.  Silent minute, half-hour and RTC
   maintenance must not reset the user-idle deadline. */
static bool idle_light_sleep(void) {
  if (!idle_sleep_allowed() || net_idle_suspend() != ESP_OK) return false;
  ui_wait_idle(6000);
  ESP_LOGI(TAG,
           "LY|IDLE|state=enter mode=light wifi=off keys=REC,MARK,BACK rtc_int=on");
  for (;;) {
    const int wake_pins[] = {
      PIN_KEY_REC, PIN_KEY_MARK, PIN_KEY_BACK, PIN_RTC_INT,
    };
    esp_sleep_disable_wakeup_source(ESP_SLEEP_WAKEUP_ALL);
    for (size_t i = 0; i < sizeof(wake_pins) / sizeof(wake_pins[0]); ++i) {
      gpio_wakeup_enable(wake_pins[i], GPIO_INTR_LOW_LEVEL);
    }
    esp_sleep_enable_gpio_wakeup();
    esp_sleep_enable_timer_wakeup(idle_next_minute_us());
    esp_err_t sleep_error = esp_light_sleep_start();
    esp_sleep_wakeup_cause_t cause = esp_sleep_get_wakeup_cause();
    bool rtc_irq = gpio_get_level(PIN_RTC_INT) == 0;
    bool key = idle_key_is_down();
    idle_disable_gpio_wake();
    ESP_LOGI(TAG, "LY|IDLE|state=wake cause=%d key=%d rtc=%d result=%s",
             (int)cause, key, rtc_irq, esp_err_to_name(sleep_error));

    if (key) {
      net_idle_resume();
      net_request_agenda_sync();
      return true;
    }
    if (rtc_irq) {
      /* RTC reminders are entirely local.  Keep Wi-Fi suspended and let the
         app loop paint the reminder before returning to light sleep. */
      app_post(APP_EV_RTC_ALARM, 0);
      return false;
    }
    if (sleep_error != ESP_OK || cause != ESP_SLEEP_WAKEUP_TIMER) {
      net_idle_resume();
      return true;
    }

    esp_err_t rtc_error = rtc_restore_system();
    const app_state_t *state = app_state_get();
    bool clock_visible = state && state->mode == APP_MODE_STANDBY &&
                         state->overlay == APP_OV_NONE && state->page == 0 &&
                         state->charging == APP_CHG_NONE;
    const char *refresh = "none";
    bool half_hour = idle_half_hour();
    bool top_of_hour = idle_top_of_hour();
    bool ten_minute = idle_ten_minute();
    bool agenda_changed = false;
    if (half_hour) {
      bool maintenance = net_idle_agenda_maintenance_start();
      if (maintenance) {
        int64_t deadline = esp_timer_get_time() / 1000 +
                           IDLE_AGENDA_MAINTENANCE_MS;
        while (!net_idle_agenda_maintenance_done(&agenda_changed) &&
               esp_timer_get_time() / 1000 < deadline) {
          if (idle_key_is_down()) {
            net_idle_resume();
            net_request_agenda_sync();
            return true;
          }
          if (gpio_get_level(PIN_RTC_INT) == 0) {
            if (!idle_stop_agenda_maintenance()) return true;
            app_post(APP_EV_RTC_ALARM, 0);
            return false;
          }
          vTaskDelay(pdMS_TO_TICKS(50));
        }
        if (!idle_stop_agenda_maintenance()) return true;
      }
    }
    /* Keep agenda maintenance every half hour, but decouple it from the
       waveform schedule: xx:00 is FULL and every other 10-minute boundary
       is FAST.  A changed agenda is folded into that one repaint. */
    if (top_of_hour) {
      ui_request_render(APP_RENDER_FULL);
      ui_wait_idle(6000);
      refresh = agenda_changed ? "full+agenda" : "full";
    } else if (ten_minute) {
      ui_request_render(APP_RENDER_FAST);
      ui_wait_idle(6000);
      refresh = agenda_changed ? "fast+agenda" : "fast";
    } else if (clock_visible) {
      ui_request_render(APP_RENDER_CLOCK_PARTIAL);
      ui_wait_idle(6000);
      refresh = "clock+battery-partial";
    }
    ESP_LOGI(TAG, "LY|IDLE|state=minute_update rtc=%s refresh=%s wifi=off",
             esp_err_to_name(rtc_error), refresh);
    if (!idle_sleep_allowed()) {
      net_idle_resume();
      return true;
    }
    /* Give the single app event loop a chance to drain power/network events
       after every silent wake.  The unchanged idle deadline sends us back to
       sleep immediately, without treating this as user activity. */
    return false;
  }
}

static void dispatch_app_message(const app_msg_t *message) {
  if (!message) return;
  if (message->ev == APP_EV_RTC_ALARM) {
    luoye_agenda_item_t due;
    if (!agenda_take_due((int64_t)time(NULL), &due)) {
      agenda_schedule_next();
      return;
    }
    app_state_set_reminder(due.title);
  }
  app_state_handle(message->ev, message->arg);
}
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

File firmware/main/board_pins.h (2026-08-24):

// board_pins.h — AI 录音卡引脚定义
// 来源:1Netlist_AI_RECORD_2026-07-10.tel(嘉立创EDA网表)+ BOM 交叉验证,2026-07-10
// 校验锚点:USB D-/D+ 在 GPIO19/20(硅片固定)、UART0 在 GPIO43/44、
//          模块 28/29/30 脚(IO35/36/37)悬空(N16R8 八线 PSRAM 占用)——三点全部吻合。
#pragma once

// ---------- 按键(无外部上拉,仅 100nF 去抖电容 → 必须开内部上拉;按下拉低) ----------
#define PIN_KEY_REC        4    // SW3, RTC-IO,可作深睡唤醒源
#define PIN_KEY_MARK       2    // SW4, RTC-IO
#define PIN_KEY_BACK       1    // SW5, RTC-IO
#define PIN_KEY_BOOT       0    // SW7, strap 脚(下载模式),运行期可作普通输入

// ---------- LED(高电平点亮,串 2.2k) ----------
#define PIN_LED_REC        48   // LED1  红:录音常亮/暂停慢闪/标记双闪/收尾快闪
#define PIN_LED_FULL       45   // LED3  黄:SD将满常亮/离线或积压≥30s慢闪/提醒闪
                                //       ⚠ strap 脚(VDD_SPI 电压),上电瞬间勿被外部强拉
#define PIN_LED_CHG        16   // LED_CHG 绿:充电中常亮

// ---------- 墨水屏 GDEY0213B74 (SSD1680, 250×122, SPI2) ----------
#define PIN_EPD_SCLK       3    // ⚠ strap 脚(JTAG源),做 SPI CLK 无碍
#define PIN_EPD_MOSI       46   // ⚠ strap 脚:启动瞬间必须为低,屏端不得有上拉
#define PIN_EPD_CS         10
#define PIN_EPD_DC         18
#define PIN_EPD_RST        21   // ← 见文末「板改建议」:可与 RTC_INT 互换
#define PIN_EPD_BUSY       14   // 输入,高=忙
#define PIN_EPD_POWER_EN   47   // TPS22918 负载开关,高=给屏供电(R24 100k 默认下拉关断)

// ---------- microSD (SPI3, 全部 22Ω 串阻) ----------
#define PIN_SD_CS          17
#define PIN_SD_MOSI        11
#define PIN_SD_SCK         12
#define PIN_SD_MISO        13
// SD 供电经 R_SD_PWR(0Ω)常供;如日后改 MOS 控制可做掉电省电

// ---------- 双 PDM 麦克风 IM72D128(副板,一根数据线立体声) ----------
#define PIN_PDM_CLK        5    // 22Ω 串阻
#define PIN_PDM_DATA       6    // 22Ω 串阻;U1 SELECT=GND(L),U2 SELECT=VDD(R)
#define PIN_MIC_LDO_EN     7    // TPS7A2033 EN,高=开麦供电;不录音时拉低省电

// ---------- I2C 总线(BQ25186 充电 0x6A / MAX17048 电量计 0x36 / PCF8563 RTC 0x51) ----------
#define PIN_I2C_SDA        8    // MAX17048/PCF8563 正常方向；BQ25186 样板焊盘接反
#define PIN_I2C_SCL        9    // MAX17048/PCF8563 正常方向；BQ25186 样板焊盘接反
#define I2C_ADDR_BQ25186   0x6A
#define I2C_ADDR_MAX17048  0x36
#define I2C_ADDR_PCF8563   0x51

// ---------- 电源管理信号 ----------
#define PIN_PWR_MODE       15   // TPS63001 PS/SYNC:高=强制PWM(录音低噪),低=PFM省电
#define PIN_BQ_CE_N        38   // 充电使能,低有效;板上 R16 10k 下拉 → 默认允许充电,可悬空
#define PIN_BQ_INT_N       39   // 充电中断,低有效(⚠ 非 RTC-IO,不能深睡唤醒)
#define PIN_BQ_PG_N        40   // Power-Good,低=USB在位(⚠ 非 RTC-IO)
#define BQ25186_BOOT_CHARGE_CURRENT_MA 1000 // 1000mAh 电芯：上电即请求 1A CC
#define BQ25186_BOOT_INPUT_LIMIT_MA  1050 // 输入限流包含系统负载，不能等同于电池充电电流
#define BQ25186_LOW_SOC_CHARGE_MA    1000 // BQ25186 自行从 CC 进入 CV 并逐步减流
#define BQ25186_MID_SOC_CHARGE_MA    1000 // 不再按电量计 SOC 提前降低 ICHG
#define BQ25186_HIGH_SOC_CHARGE_MA   1000 // 不以 MAX17048 的 100% 代替充电终止
#define BQ25186_LOW_SOC_INPUT_MA     1050 // 系统负载会由 ILIM/DPPM 自动从电池充电电流中让路
#define BQ25186_MID_SOC_INPUT_MA     1050
#define BQ25186_HIGH_SOC_INPUT_MA    1050
#define PIN_BAT_ALRT       42   // MAX17048 低电报警,低有效(⚠ 非 RTC-IO)
#define PIN_RTC_INT        41   // PCF8563 闹钟中断,低有效
                                // ⚠⚠ GPIO41 非 RTC-IO:深睡时闹钟无法唤醒芯片!
                                //     当前方案:有待办提醒时用 light sleep;详见 README「板改建议」

// ---------- USB / 调试串口(固定,不可改) ----------
#define PIN_USB_DN         19
#define PIN_USB_DP         20
#define PIN_UART0_TX       43
#define PIN_UART0_RX       44

// ---------- SPI 主机分配 ----------
#define EPD_SPI_HOST       SPI2_HOST
#define SD_SPI_HOST        SPI3_HOST

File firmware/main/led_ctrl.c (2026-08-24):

// led_ctrl.c — 50ms tick 的花样发生器,直接读状态机快照决定三灯输出。
// REC 红:录音常亮 / 暂停慢闪(1.1s) / 收尾快闪(0.3s) / 标记双闪(优先级最高)
// FULL 黄:提醒页慢闪 / SD将满常亮 / (录音中离线 或 积压≥30s)慢闪
// CHG 绿:充电中常亮
#include "led_ctrl.h"
#include "app_state.h"
#include "board_pins.h"
#include "freertos/FreeRTOS.h"
#include "freertos/task.h"
#include "driver/gpio.h"
#include "esp_timer.h"

static volatile int64_t s_mark_flash_until;   // 双闪截止时刻(ms)
static volatile int64_t s_self_test_start;    // 自检起始时刻,0=非自检

static inline int64_t now_ms(void) { return esp_timer_get_time() / 1000; }
static inline bool blink(int64_t t, int period_ms) { return (t / (period_ms / 2)) % 2 == 0; }

void led_ctrl_mark_flash(void) { s_mark_flash_until = now_ms() + 760; }
void led_ctrl_self_test(void)  { s_self_test_start = now_ms(); }

static void led_task(void *arg) {
  (void)arg;
  for (;;) {
    const app_state_t *s = app_state_get();
    int64_t t = now_ms();
    bool r = false, f = false, c = false;

    if (s_self_test_start && t - s_self_test_start < 1440) {   // 三灯轮流点亮 3×360ms + 熄灭
      int step = (int)((t - s_self_test_start) / 360);
      r = step == 0; f = step == 1; c = step == 2;
    } else {
      s_self_test_start = 0;
      // REC 红
      if (t < s_mark_flash_until) r = blink(t, 240);                       // 双闪
      else if (s->mode == APP_MODE_STARTING || s->mode == APP_MODE_RECORDING)
        r = s->paused ? blink(t, 1100) : true;
      else if (s->mode == APP_MODE_CLOSING) r = blink(t, 300);
      else if (s->mode == APP_MODE_STORAGE_ERROR) {
        r = blink(t, 400);
        f = !r;
      }
      // FULL 黄
      if (s->overlay == APP_OV_REMINDER) f = blink(t, 1100);
      else if (s->mode == APP_MODE_STORAGE_ERROR) { /* pattern set above */ }
      else if (s->sd_low) f = true;
      else if ((s->mode == APP_MODE_RECORDING && !s->online) || s->backlog_s >= 30) f = blink(t, 1100);
      // CHG 绿
      c = s->charging == APP_CHG_CHARGING;
    }
    gpio_set_level(PIN_LED_REC, r);
    gpio_set_level(PIN_LED_FULL, f);
    gpio_set_level(PIN_LED_CHG, c);
    vTaskDelay(pdMS_TO_TICKS(50));
  }
}

esp_err_t led_ctrl_init(void) {
  gpio_config_t cfg = {
    .pin_bit_mask = (1ULL << PIN_LED_REC) | (1ULL << PIN_LED_FULL) | (1ULL << PIN_LED_CHG),
    .mode = GPIO_MODE_OUTPUT,
  };
  esp_err_t err = gpio_config(&cfg);
  if (err != ESP_OK) return err;
  if (xTaskCreate(led_task, "leds", 2560, NULL, 5, NULL) != pdPASS) return ESP_ERR_NO_MEM;
  return ESP_OK;
}

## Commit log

2026-08-24 chore: establish Luoye firmware 2.3.2 and server 1.0.1 baseline
    [luoye-enclosure-bottom-v2.step, luoye-enclosure-inner-v2.step, luoye-enclosure-outer-v2.3mf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]
2026-08-30 release: sync firmware 1.7.1 and refresh hardware showcase
    [luoye-button-leaf-v2.step, luoye-button-round-v2.step, luoye-enclosure-outer-v2.3mf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]
